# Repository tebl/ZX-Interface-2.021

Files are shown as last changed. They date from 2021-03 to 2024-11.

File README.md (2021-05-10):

# ZX Interface 2.021
I woke up in the middle of the night with idea, and like most non-sensical ideas - they usually disappear in the morning. Can't remember what that idea was, but it was properly better than this one: recreating a simple version of the *ZX Interface 2* because I simply can't afford the prices the original ones are going for. Having made a few *improvements* to the original design, I was going to call it the *ZX Interface 2000* - that would however imply that I had put anything modern into it, so *ZX Interface 2.021* was the name I came up with instead. There's even a short video showing it running on [YouTube](https://youtu.be/rGyqisjjOV8).

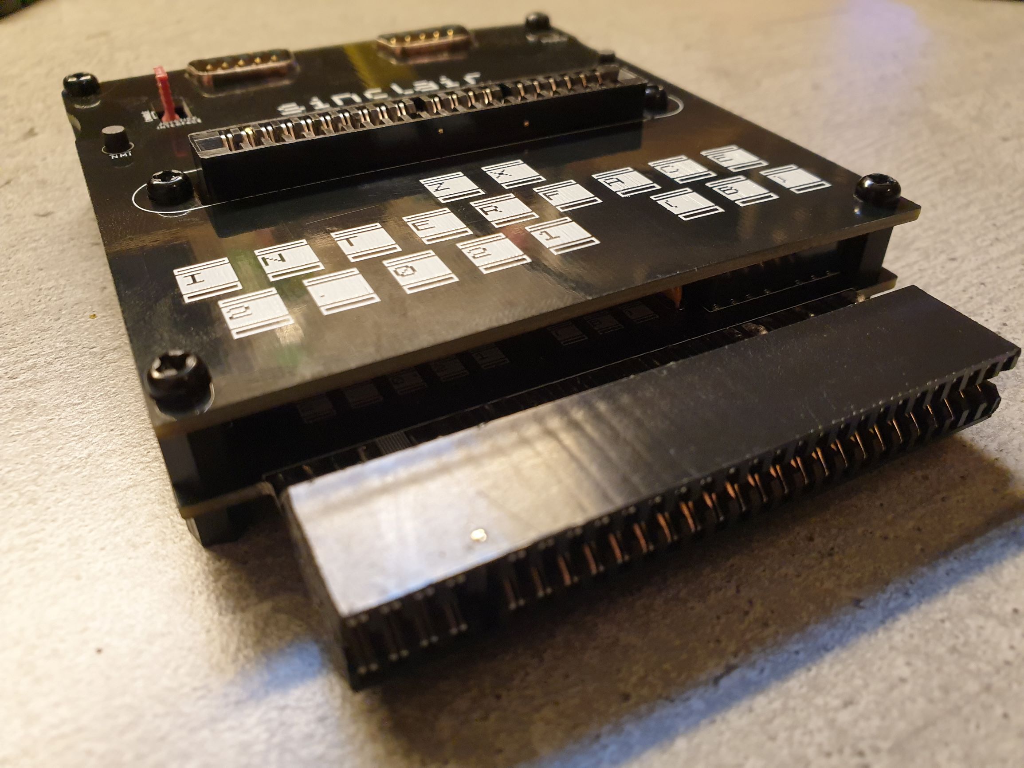
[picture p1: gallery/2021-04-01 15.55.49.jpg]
ZX Interface 2.021


There are other more modern implementations for putting together a ZX Spectrum cartridge solution, the Dandanator comes to mind, but I wanted something without the magic black boxes (MCUs, FPGAs or GALs) - my goal is that it should be easy to build and easy to understand. Also, I kind of like having various physical cartridges that can plug into it - so an actual cartridge slot was always a requisite for this project. 

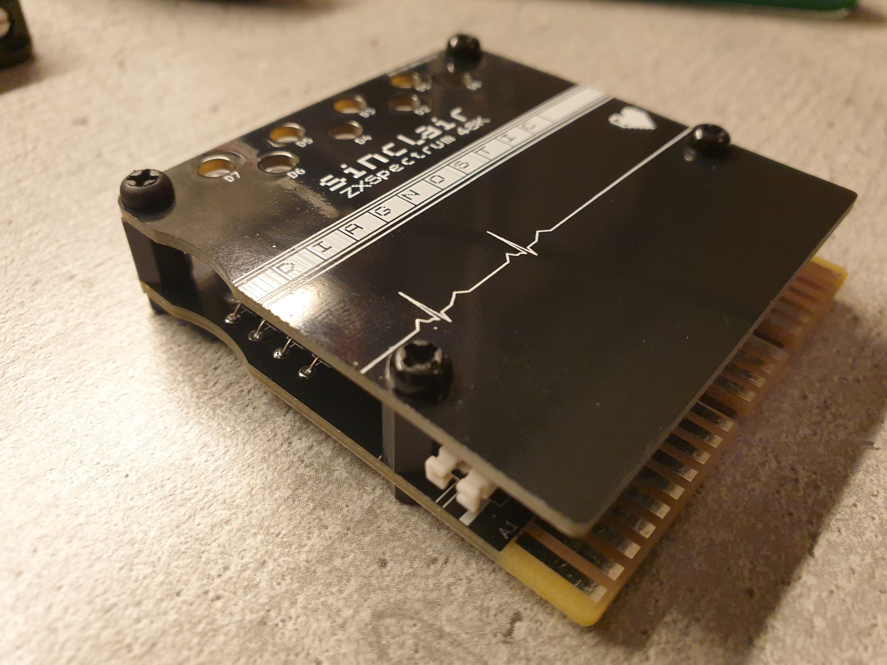
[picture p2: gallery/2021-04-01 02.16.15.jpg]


Over to the improvements then, of which there are mainly just one that hasn't already been mentioned (the first one being the elimination of custom IC, for which there are no replacements). The other one is that logic for bank switching has been integrated into the interface, in its current state it allows you to access up to 512k ROMs in 16k segments. Four of them actually, bringing the maximum addressable ROM up to a whopping 4MB (that's 4096KB, not merely 4 Mbit).

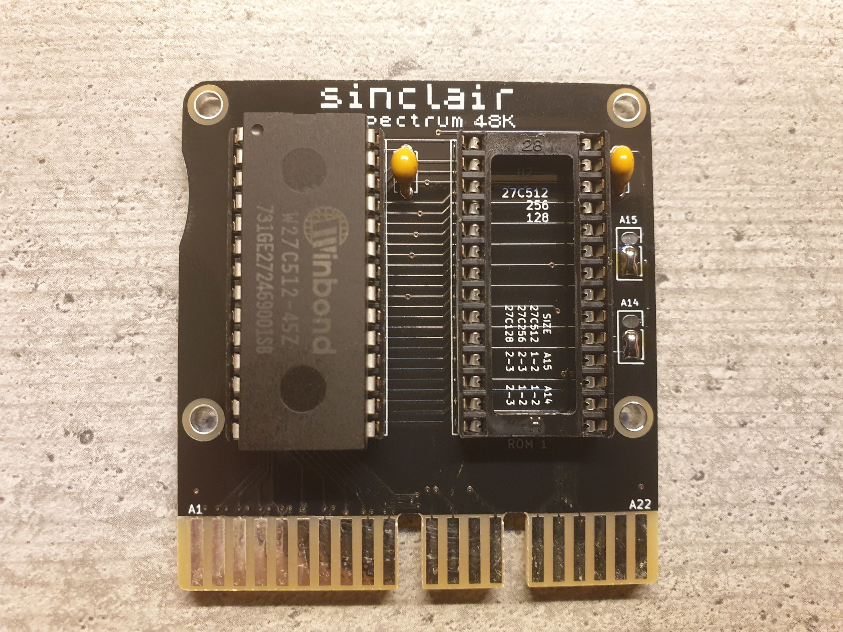
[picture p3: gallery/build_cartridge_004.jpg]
ZX Cartridge 2.021

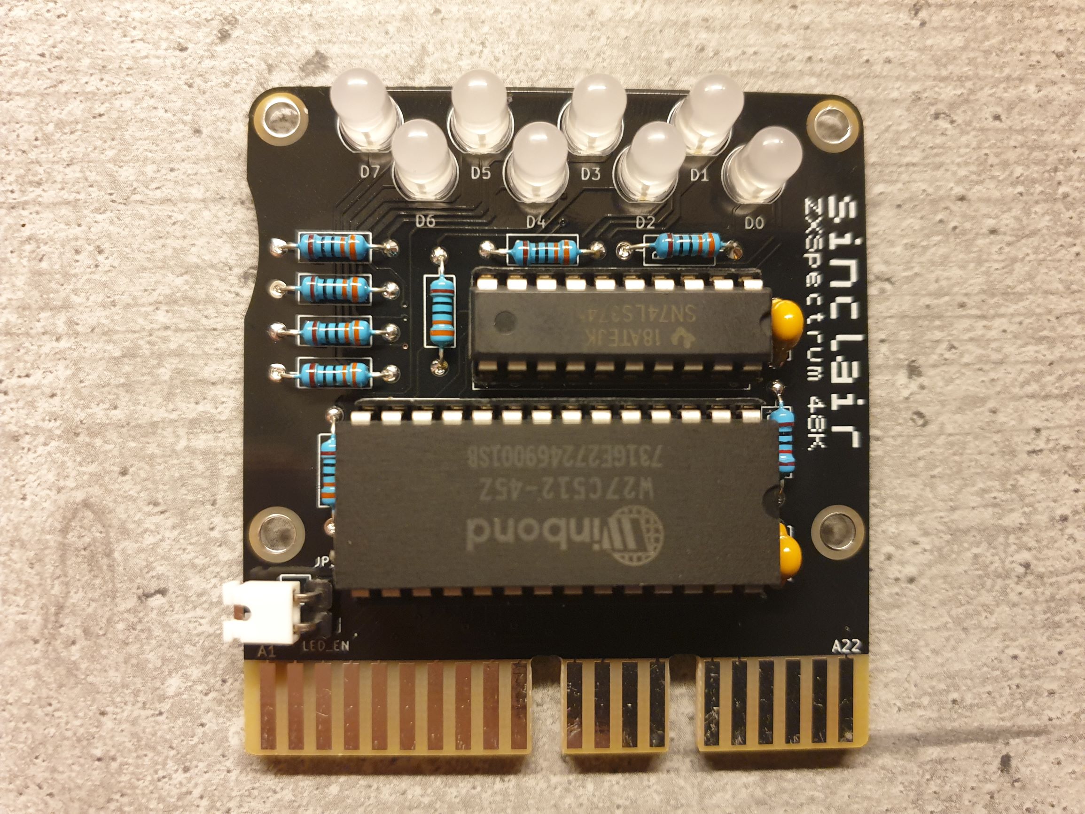
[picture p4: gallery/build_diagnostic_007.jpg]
ZX Diagnostic 2.021


The cartridges available mostly will have some different attributes, so you'll need to check out the README for each one of them to access all relevant information. When starting out I recommend starting with the diagnostic cartridge, it supports a single EPROM of up to 64K - giving you access to four 16K ROM images that you can switch between by using a technique called [bank switching](https://github.com/tebl/ZX-Interface-2.021/blob/main/documentation/bank_switching.md). The ZX Spectrum computer doesn't exactly expect you to hot-swap them this way, so there is a need to add a [Cartridge Loader](https://github.com/tebl/ZX-Interface-2.021/tree/main/software/cartridge_loader) program to ensure that the program starts correctly. To make things a bit easier on myself when it comes to creating cartridge compilations, I've put together a [Cartridge Creator](https://github.com/tebl/ZX-Interface-2.021/tree/main/software/cartridge_creator) that automates tasks as well as supporting updating the loader program with bank titles as well as changing out the boot screen with ZX Spectrum SCR-files.

The diagnostic software I'm using by Brendan Alford, will attempt to write state information to the LEDs on port 63. You can also play around with them directly from basic, just do an "*OUT 63, 255*" - to turn all of them on. Battlestar Galactica fans will intuitively know what tomorrows project ought to be!

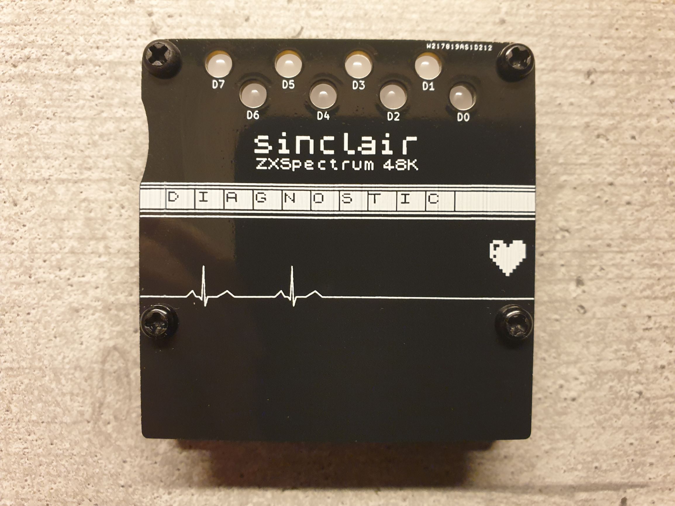
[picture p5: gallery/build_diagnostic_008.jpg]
ZX Diagnostic 2.021 FA1


The project includes a bunch of faceplates, they are mainly just there to look incredibly cool! Especially in black. While I've done a few pretty ones to match specific games, I've not obtained permission to include the likeness of any of the characters - for that reason, those have been intentionally kept separate from the github-repository. They may however show up in the gallery sections, because they exist and I had fun making them for my own personal enjoyment.

## Getting one
I don't have the capability of selling completed units or "kits" for building one, mainly due to health reasons. If you want one you will probably have to build it yourself, alternatively you could always call your favourite friend - preferably one that already owns, or is willing to buy a soldering iron of reasonable quality.

The following table will point you to more information about the specific modules, including a list of the components that goes into building one of them (referred to as a BOM). While the interface can be used as a standalone Sinclair joystick interface, you'll more than likely want at least one of the additional cartridges so that you have something to plug into it as well. Note that there will be several faceplates available for these, these as well as the PCBs for the modules listed are available on [PCBWay shared projects](https://www.pcbway.com/project/shareproject/?tag=ZX%20Interface%202.021).

| Module | Description |
| --- | --- |
| [ZX Interface 2.021](https://github.com/tebl/ZX-Interface-2.021/tree/main/ZX%20Interface%202021) | The actual interface, includes cartridge slot and joystick interface.
| [ZX Diagnostic 2.021](https://github.com/tebl/ZX-Interface-2.021/tree/main/ZX%20Diagnostic%202021) | A diagnostic cartridge, only for use with *ZX Interface 2.021*.
| [ZX Cartridge 2.021](https://github.com/tebl/ZX-Interface-2.021/tree/main/ZX%20Cartridge%202021) | Cartridge supporting up to two 64K ROMs, eight banks of data in total. Only for use with *ZX Interface 2.021*.
| [ZX Cartridge 1.983](https://github.com/tebl/ZX-Interface-2.021/tree/main/ZX%20Cartridge%201983) | A simple cartridge that can also be used with the original ZX Interface 2 (without bank switching support).

**NB!** As with all things you're soldering together by yourself, the one who soldered it - takes responsibility for it. I'll try to help in any way that I can, but know that this is a hobby-grade project and my health is not such that I can focus on too many things at any given time. Check out the [schematic](https://github.com/tebl/ZX-Interface-2.021/tree/main/documentation/schematic) while you wait, just about every problem is just an opportunity for learning and there is a significant chance that you'll be able to find your answer within it.

## Setting it up
The *ZX Interface 2.021* has a handful of jumpers that need to be set correctly in order to keep everything working as intended (refer to image below for reference). The jumper in the top left corner is used to enable the joystick interface, put a jumper across pins 1-2 (the lower position) and it should provide you with many hours of joy with your favourite Atari-compatible stick.

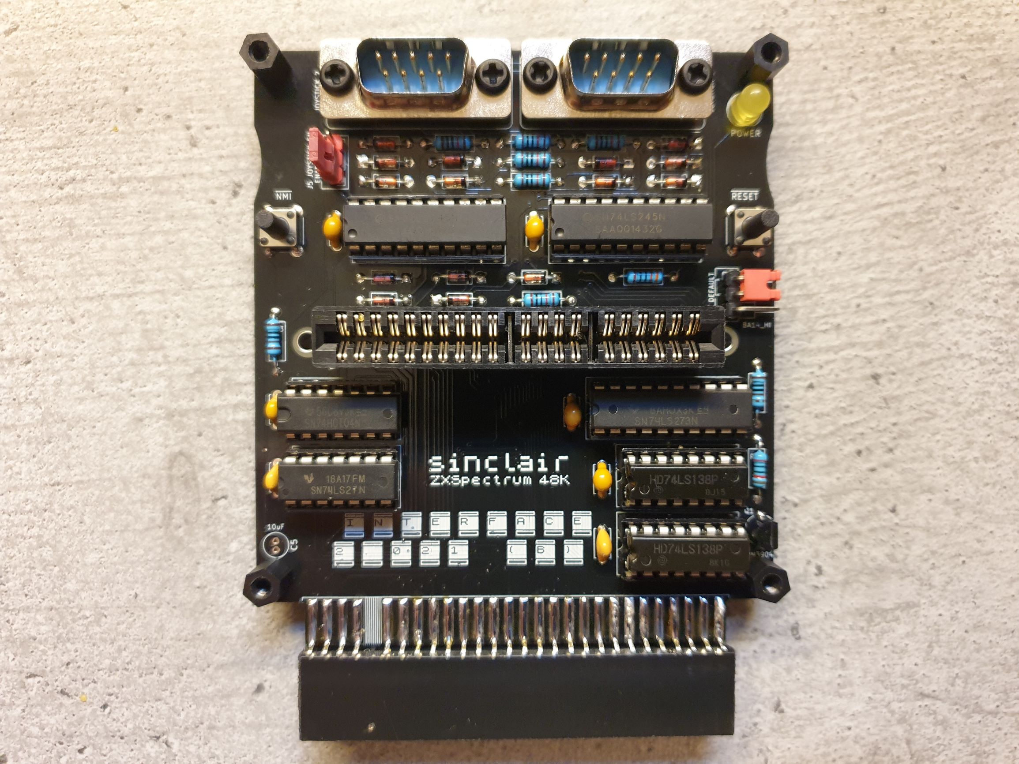
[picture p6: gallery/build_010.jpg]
ZX Interface Jumpers


The second jumper, middle right section allows you to hardcode one of the address lines used for bank switching. Setting it the lower position forces it high, in effect allowing you to quickly select between two 16k ROM images in the first and second bank - when all else fails. This is here as a way to swap between diagnostic images when the machine isn't capabable of doing this in the preferred way. In normal use, jumper across pins 1-2 (this is the upper position).

**NB!** As with all kinds of vintage electronics that you don't want to destroy, you shouldn't attempt to insert or remove a cartridge when the system is powered up. Ignoring this will either kill this interface, the cartridge or your computer - sometimes all of them.

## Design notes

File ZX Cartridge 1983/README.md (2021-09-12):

# ZX Cartridge 1.983
With the ZX Cartridge 2.021, I intentionally created a cartridge that wouldn't be compatible with any of the original cartridge interfaces released for the ZX Spectrum. The more known of these type of interfaces is the original *ZX Interface 2*, but Kempston also released a well known one in the form of the *Kempston Pro Joystick Interface*. The first one was naturally priced firmly out of my price-range, the second one I got a hold of wasn't in a working state - so I went for option three instead, the *RAM turbo Mk2* joystick interface. Having found a working interface, I wanted an actual cartridge to use with it - so I created the *ZX Cartridge 1.983* to test things out.

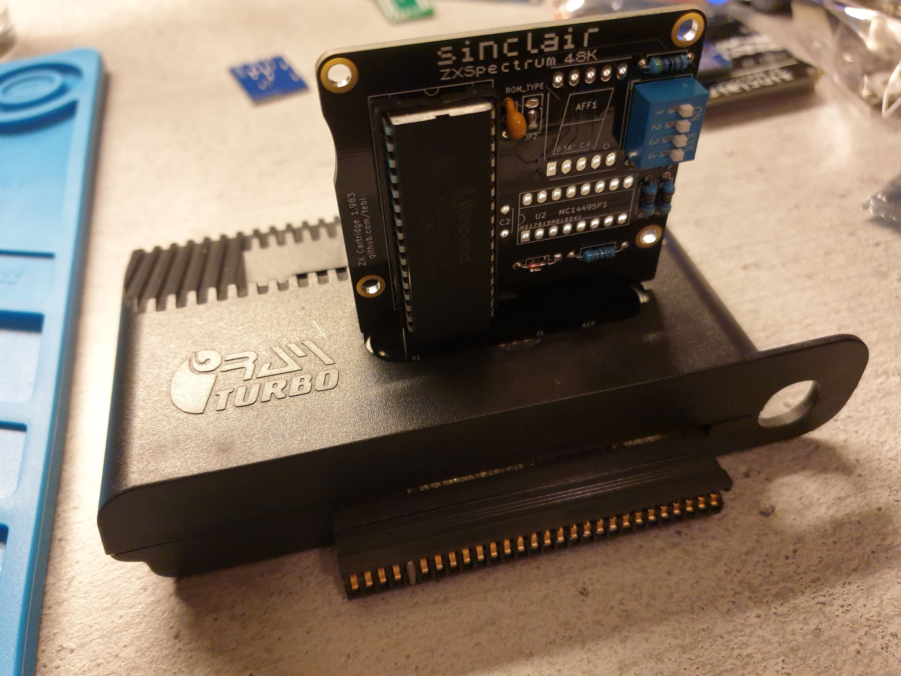
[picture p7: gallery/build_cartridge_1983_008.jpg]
ZX Cartridge 2.021


True to form, I didn't simply want to build a 16K cartridge - so I sprinkled a little bit of extra feature creep upon it. I figured that I'd look into being able to use even larger EEPROMs that what I'd used so far, with the 27C020 able to hold 16 of these images - pretty extreme when considering that the system only had 10 officially released titles. There are a few [cassette conversions](http://www.fruitcake.plus.com/Sinclair/Interface2/Cartridges/Interface2_RC_New_3rdParty_GameConversions.htm) that can be used as well, good enough to fill a couple of them. With 16 images possible combinations I needed a way to choose between them, cheap as I am the solution became a 4 position DIP-switch. Just because I already had them and the space, I added a completely optional HEX-decoder IC and 7segment display - gloriously over-engineered. Smaller (E)EPROMs can still be used such as the 27C256/27C512 can still be used, you just need to install components to match.

- [1> Building the cartridge](#1-building-the-cartridge)
  - [1.1> Soldering it together](#11-soldering-it-together)
  - [1.2> Testing it out](#12-testing-it-out)
- [2> Schematic](#2-schematic)
- [3> BOM](#3-bom)

# 1> Building the cartridge
Building the unit assumes you have at least minor experience soldering things together, recommended is at least a soldering station with adjustable temperature to get started - usually you'll want some 60/40 solder tin (if you can get that where you live). Given that we're going to be flashing data onto EPROM chips, you'll need an EPROM programmer suitable for this task - the one I'm using is a MiniPro TL866CS and so far it's surpassed my expectations for such a reasonably priced device. If you are going to use EPROM chips you will need an EPROM ereaser as well, but read on - you might not need that depending on the chips you purchase.

With the equipment sorted, now comes the shopping - so head on over to the [BOM](#3-bom)-section for some information on what you need. Note that with sites such as ebay, AliExpress and similar sites that sell cheap chinese components, you'll need to treat these as a suggested search term and look for something that matches the gallery pictures.

You'll need to order some EPROM chips as well. As previously mentioned, you can use anything from 27C128 up to 27C020 chips. One specific chip I can recommend looking for is the W27C512, W27C010 or W27C020 as that is actually an EEPROM with the compatible pin layouts, meaning you won't need the previously mentioned EPROM ereaser. The price difference should be negligible unless you're going to make a lot of them.

## 1.1> Soldering it together
The construction of this unit should be straight-forward, there's only a few components to speak of - and none of them overlap in any way. I do however recommend that you build up the components in increasing size, that way you'll have an easier time getting everything on there straight.

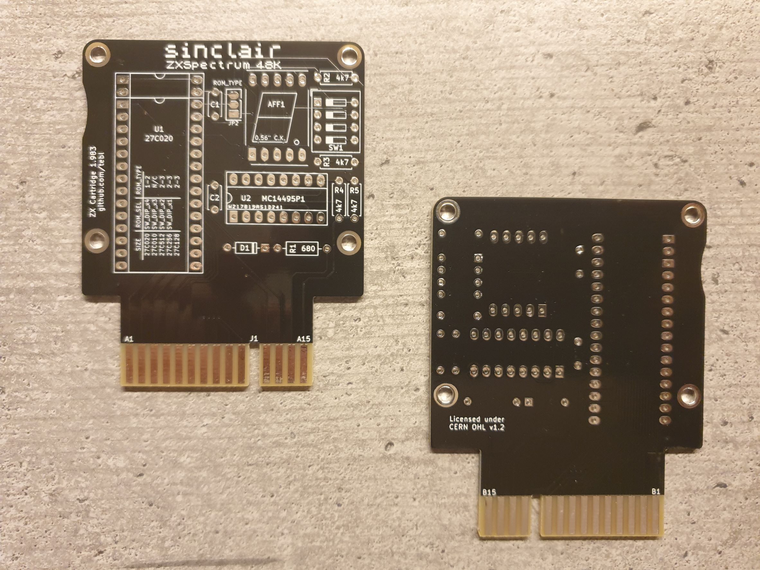
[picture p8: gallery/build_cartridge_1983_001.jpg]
Build cartridge 001

Build cartridge 001

As shown above, we've started by installing resistors as well as the single diode (note the polarity marking, the line should match up with the board). Before moving onto anything else, we need to figure out which (E)EPROM chips we're going to install, for the two larger options we'll need to use a 32-pin socket (reconsider your life choices if not installing sockets) - for anything 27C512 or smaller we can use the common 28-variety, making sure that we leave a gap of four holes at the **top** of the board. Solder the jumper marked *ROM_TYPE* according to the table (the square pad marks pin 1, N/C means leave unconnected).

| (E)EPROM | ROM_SEL | ROM_TYPE |
| --- | --- | --- |
| 27C020 | 4 way DIP | 1-2 |
| 27C010 | 3 way DIP | N/C |
| 27C512 | 2 way DIP | 2-3 | 
| 27C256 | 1 way DIP | 2-3 |
| 27C128 | | 2-3 | 

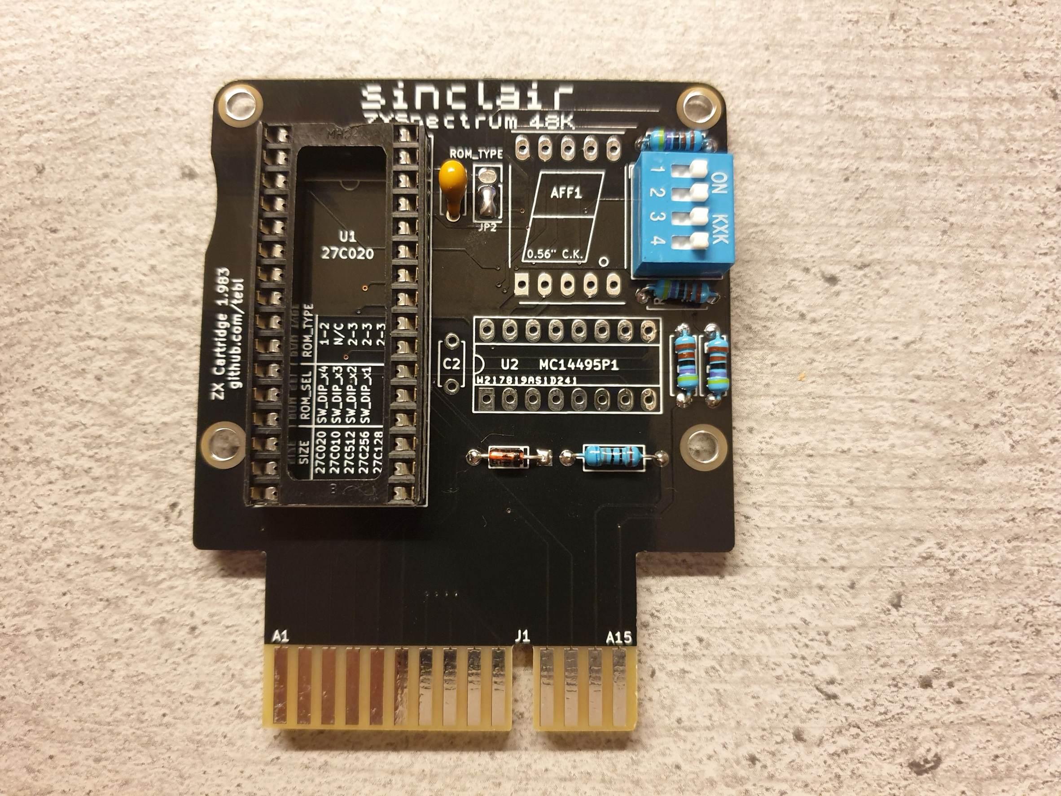
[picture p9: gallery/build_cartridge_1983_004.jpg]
Build cartridge 001


The two capacitors aren't polarized, just get them stuck into the hole and you'll be ready to move along to a suitable beat. Next step is to put in the DIP-switches, but refer to the table above so that you use the correct one - mount it at the top, leaving empty holes towards the bottom of the board.

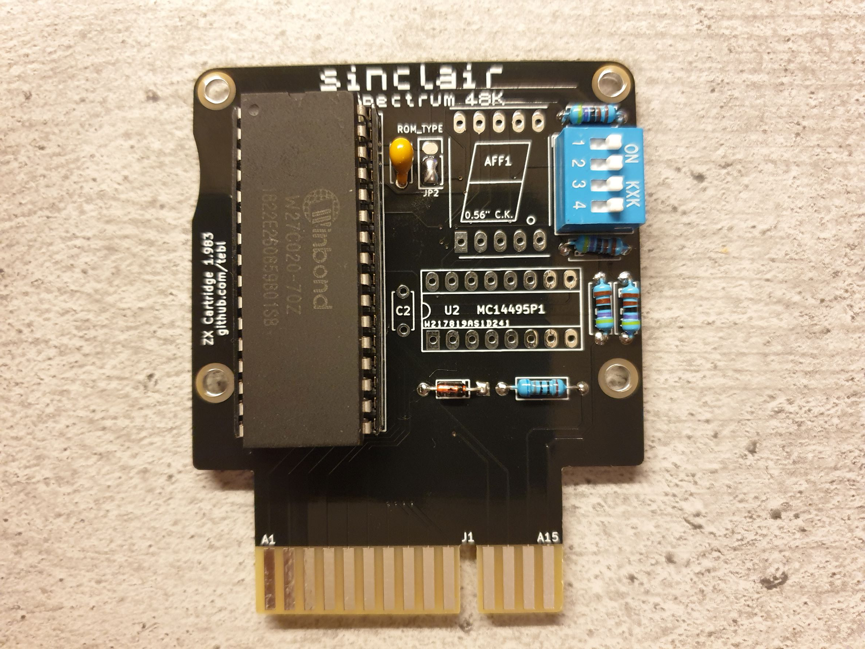
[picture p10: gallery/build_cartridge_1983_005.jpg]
Build cartridge 001


With the end of the build in sight, we focus on the single remaining component - the 7-segment display. The display should have be a 0.56" one, it should have been sold to you as one with a common cathodes (C.K.). If in doubt whether you have the correct display, put your multimeter in diode testing mode (oftenly referred to as *continuity*-mode) and ensure that you can light up one segment by putting the negative lead on the bottom center pin. Using the display requires an old IC marked MC14495P1, it is the only one I've come across that can count displays digits above 9 without costing an arm and a leg (I bought mine on AliExpress).

## 1.2> Testing it out
I shouldn't have to say it at this point, but I'll do so anyway - cartridges are not memory cards, plugging them in or unplugging them while the system is powered on will **KILL** your equipment. If you've not already done so, you'll need to put something on your selected (E)EPROM - see separate document on [flashing an EEPROM](https://github.com/tebl/ZX-Interface-2.021/blob/main/documentation/flash_eeprom.md) for details on how to do this (in particular the part on combining 16K images). With that out of the way, just plug the cartridge into the slot  and power on the ZX Spectrum.

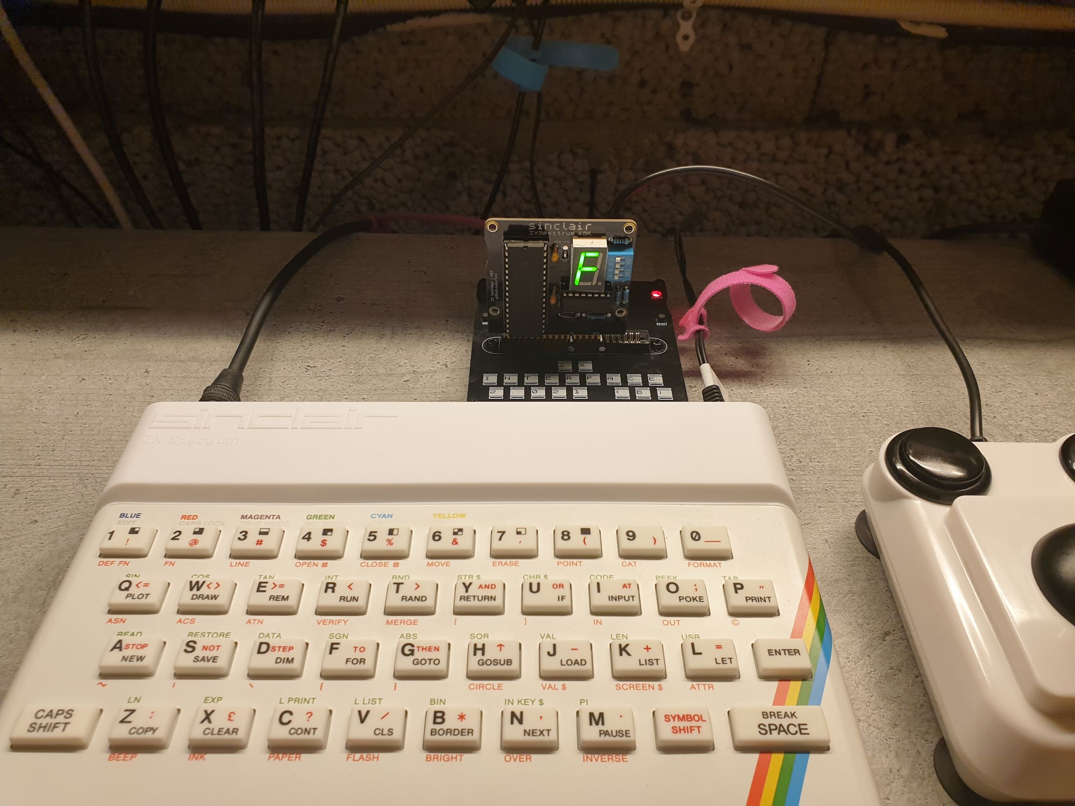
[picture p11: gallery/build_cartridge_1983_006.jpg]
Build cartridge 006


One thing that I've found with ZX Spectrum cartridges is that they tend to restart when program running on it crashes, which we can at times use to simply move the switches to swap games. Not all of them will work reliably, but as with everything ZX Spectrum - if in doubt, just reset the computer and everything should be back to normal again. If you don't have a reset button available, such as when using the old interfaces on a non-plussed computer, you'd need pull the power - just like we did in 1983.

# 2> Schematic
The supplied KiCad files should be sufficient as both a schematic and as a  starting point for ordering PCBs (basically you could just zip the contents of the export folder and upload that on a fabrication site), the schematic is also available in [PDF-format](https://github.com/tebl/ZX-Interface-2.021/tree/main/documentation/schematic) and this is what you'll need to print and work your way through this things don't work as expected after assembly.

# 3> BOM
Most parts should be easy to get a hold of from your favourite local electronic component shop, but given that I don't have access to such shops where I live so everything was based on whatever I could get cheapest from eBay/AliExpress (free shipping, but plan on waiting 3-4 weeks for delivery). 

| Reference | Item | Count | Order  |
| --- | --- | ----- | --- |
| Cartridge PCB | Fabricate using Gerber files | 1 | [PCBWay]()
| AFF1 * | 0.56" 7-segment display (C.K.) | (1)|
| C1,C2 | 100nF ceramic capacitor (5mm pin spacing) |  1 (1)|
| D1 | 1N4148 small signal diode (DO-35) | 1 | 
| R1 | 680 ohm resistor | 1 |
| R2-R5 | 4k7 (4700) ohm resistor | 4 |
| U1 ** | 27C020 or smaller (E)EPROM (W27C020 recommended) | 1 |
| U1 * | MC14495P1 (DIP-16) | (1)|
| SW1 ** | 1-4 way DIP switch | 1 |
| Mounting *** | Nylon M3 hex standoffs 8mm | (4)|
| Mounting *** | Nylon M3x6mm nylon screws | (4)|
| Mounting *** | M3 nylon nut | (4)|  

*) These are optional components that are just used to show the slot number. Cool, but not needed.

**) The DIP switch needs to match the size of the (E)EPROM that you wish to install on the board, for more information have a read-through of [1.1> Soldering it together](#11-soldering-it-together).

***) The easiest way of ordering these is to just one of the M3 nylon standoff kits on ebay, AliExpress or any similar sites. That way you'll get more than what you need in various sizes for future projects as well. Check out [faceplate](https://github.com/tebl/ZX-Interface-2.021/tree/main/faceplates) section of this repository or [PCBWay shared projects](https://www.pcbway.com/project/shareproject/?tag=ZX%20Interface%202.021) for available options.

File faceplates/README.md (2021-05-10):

# Faceplates
When designing the *ZX Interface 2.021* I had a vision of using cartridge on it that didn't look like a bare circuit board, but it needed to be something that didn't require any sort of 3D-printing facility so I opted to just make the *"case"* another PCB. Adding a label printer finishes the look though I probably should have bought some with a clear backing, but there's always next month for those sorts of changes.

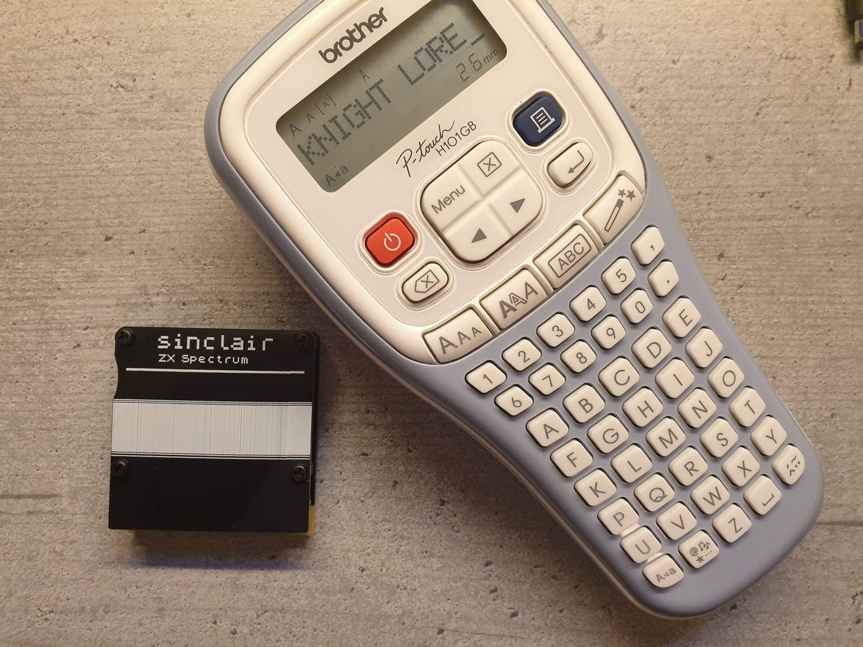
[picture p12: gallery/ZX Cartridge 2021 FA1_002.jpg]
Label printer

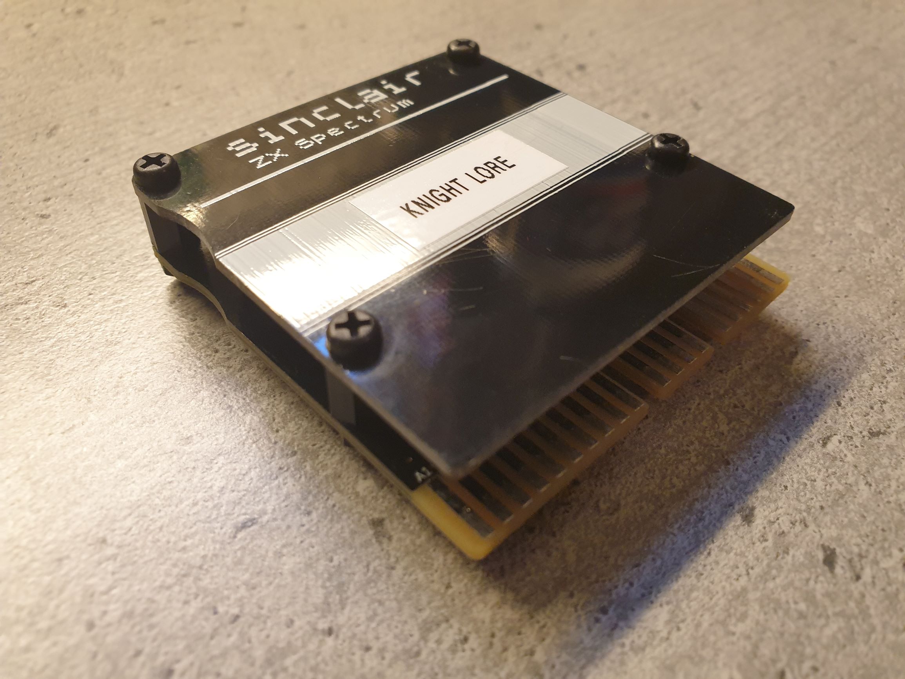
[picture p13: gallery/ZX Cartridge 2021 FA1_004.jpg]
Finished cartridge

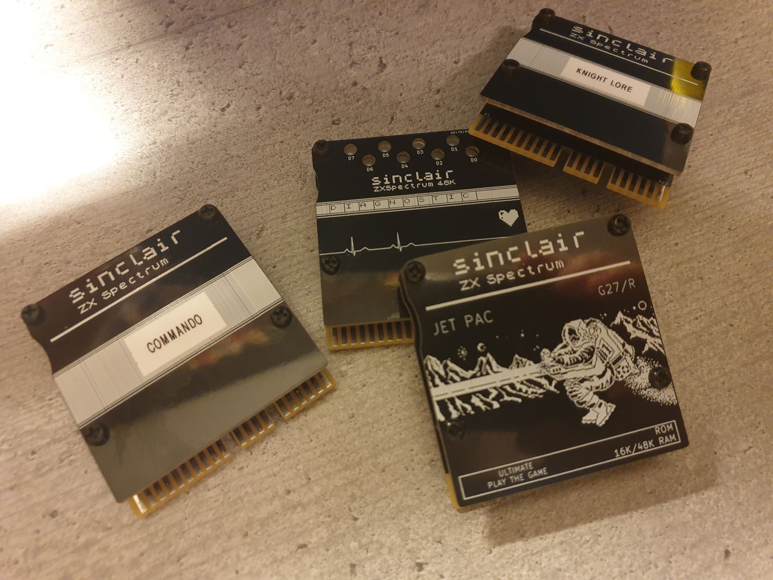
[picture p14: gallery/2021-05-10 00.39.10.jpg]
Varius cartridge


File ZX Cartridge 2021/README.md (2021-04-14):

# ZX Cartridge 2.021
The ZX Cartridge 2.021, simply referred to as *cartridge* for the remainder of this document, is a modified version of the one released by Sinclair back in 1983. The original cartridge design was limited to 16K without any of the signals required to easily build a larger one, so the *ZX Cartridge 2.01* set out to fix that - simply by extending the length of the cartridge. This does mean that you can't use it with the original *Sinclair ZX Interface 2*, you can only use it with the *ZX Interface 2.021*.

ZX Cartridge 2.021

Though the interface itself is able to address ROM chips in sizes up to 512K, four of them actually, the cartridge itself was designed with the ROM chips ranging from 27C128 up to 27C512. I might make a monster cartridge at some point, but given that there were only around 10 cartridges released for the original system - having the space for 8 of them is a good starting point.

Note that there are various faceplates available for the cartridges, these complete the look of the cartridge as well as help them balance on top of the interface. Check out the [faceplates](https://github.com/tebl/ZX-Interface-2.021/tree/main/faceplates) section for an overview over the ones that have been made available, also see [PCBWay shared projects](https://www.pcbway.com/project/shareproject/?tag=ZX%20Interface%202.021).

- [1> Building the cartridge](#1-building-the-cartridge)
  - [1.1> Soldering it together](#11-soldering-it-together)
  - [1.2> Assembling the unit](#12-assembling-the-unit)
  - [1.3> Testing it out](#13-testing-it-out)
- [2> Schematic](#2-schematic)
- [3> BOM](#3-bom)

# 1> Building the cartridge
Building the unit assumes you have at least minor experience soldering things together, recommended is at least a soldering station with adjustable temperature to get started - usually you'll want some 60/40 solder tin (if you can get that where you live). Given that we're going to be flashing data onto EPROM chips, you'll need an EPROM programmer suitable for this task - the one I'm using is a MiniPro TL866CS and so far it's surpassed my expectations for such a reasonably priced device. If you are going to use EPROM chips you will need an EPROM ereaser as well, but read on - you might not need that depending on the chips you purchase.

With the equipment sorted, now comes the shopping - so head on over to the [BOM](#3-bom)-section for some information on what you need. Note that with sites such as ebay, AliExpress and similar sites that sell cheap chinese components, you'll need to treat these as a suggested search term and look for something that matches the gallery pictures.

You'll need to order some EPROM chips as well. As previously mentioned, you can use anything from 27C128 up to 27C512 chips. One specific chip I can recommend looking for is the W27C512 chip as that is actually an EEPROM with the same pin layout, meaning you won't need the previously mentioned EPROM ereaser. The price difference is negligible unless you're going to make a lot of them.

## 1.1> Soldering it together
The construction of this unit should be straight-forward, specifically as there are only a handful of components to deal with. If you are only going to install a single (E)EPROM into the board, you just need to solder in the left socket and the capacitor next to it.

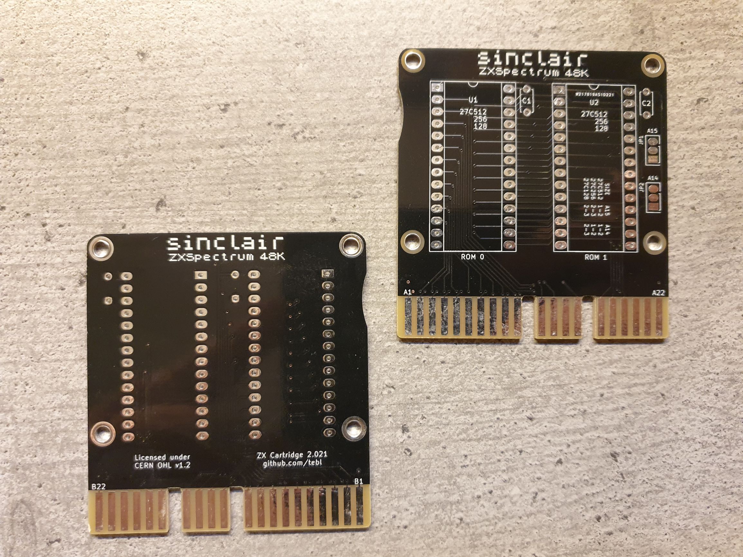
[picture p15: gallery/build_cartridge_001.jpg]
Build cartridge 001


There are two solder jumpers on the right side of the cartridge, these are clearly labelled A14 and A15 with pin 1 identifiable as the square pad. You need to add some solder to bridge between two of the pins, this is dependent on the type of (E)EPROM you are going to install into the slots (they need to be of the same kind so no mixing and matching).

| (E)EPROM | A15 | A14 |
| --- | --- | --- |
| 27C512 | 1-2 | 1-2 | 
| 27C256 | 2-3 | 1-2 | 
| 27C128 | 2-3 | 2-3 | 

A completed unit with the jumpers soldered in for the installed 27C512 chip can be seen below, this is mainly all there is to it. The rest of the components that are usually associated with ZX Spectrum cartridges are integrated into the *ZX Interface 2.021* instead - meaning you can quickly solder together all the cartridges you'll ever need in just a few minutes.

Build cartridge 004

## 1.2> Assembling the unit
There isn't all that much that can be said for assembling the unit, chances are you've already finished the entire thing by this point. The only remaining step would just be to add a [faceplate](https://github.com/tebl/ZX-Interface-2.021/tree/main/faceplates), it helps keep the cartridge from flopping around in the cartridge slot while adding quite a bit of visual flair to it.

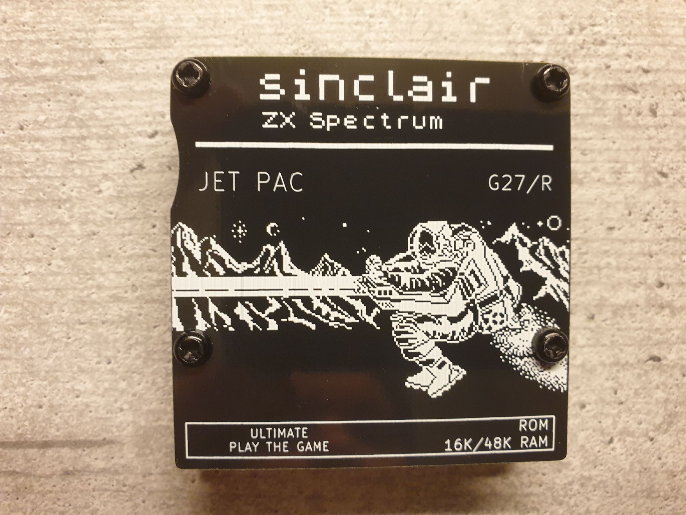
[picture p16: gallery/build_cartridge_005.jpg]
Build cartridge 005


The faceplate is just a simple PCB, the suggested way of attaching it is by using components found in cheap *M3 nylon hex* kits. It will look at its best when using an 8mm nylon hex standoff (F-F), then adding screws from both sides. If, on the other hand, you want to stay within the kit - then I suggest using the 8mm M-F standoffs, add M3 nuts on the bottom and snip off the remaining part of the nylon screw that'll poke through. Add screws on top.

## 1.3> Testing it out
I shouldn't have to say it at this point, but I'll do so anyway - cartridges are not memory cards, plugging them in or unplugging them while the system is powered on will **KILL** your equipment. With that out of the way, just plug the cartridge into the slot and then apply power to see if whatever you put into the first 16K of the (E)EPROM starts up as expected.

The ZX Spectrum doesn't actually have any knowledge of any of the bank switching logic installed on the interface, in fact the ROM in your computer will be completely disabled when any cartridge is inserted into the interface. So in order to access any of the other banks available we'll need to come up with something else, but that is described separately in [bank_switching](https://github.com/tebl/ZX-Interface-2.021/blob/main/documentation/bank_switching.md) that have been included as part of the [documentation](https://github.com/tebl/ZX-Interface-2.021/tree/main/documentation).

# 2> Schematic
The supplied KiCad files should be sufficient as both a schematic and as a  starting point for ordering PCBs (basically you could just zip the contents of the export folder and upload that on a fabrication site), the schematic is also available in [PDF-format](https://github.com/tebl/ZX-Interface-2.021/tree/main/documentation/schematic) and this is what you'll need to print and work your way through this things don't work as expected after assembly.

# 3> BOM
Most parts should be easy to get a hold of from your favourite local electronic component shop, but given that I don't have access to such shops where I live so everything was based on whatever I could get cheapest from eBay/AliExpress (free shipping, but plan on waiting 3-4 weeks for delivery). 

| Reference | Item | Count | Order  |
| --- | --- | ----- | --- |
| Cartridge PCB | Fabricate using Gerber files | 1 | [PCBWay](https://www.pcbway.com/project/shareproject/ZX_Cartridge_2_021.html)
| Faceplate PCB * | Fabricate using Gerber files | (1)| [PCBWay](https://www.pcbway.com/project/shareproject/ZX_Cartridge_2_021__Faceplate_FA1_.html)
| U1,U2 ** | 27C128,27C256 or 27C512 (W27C512 recommended) |  1 (1)|
| C1,C2 ** | 100nF ceramic capacitor (5mm pin spacing) |  1 (1)|
| Mounting * | Nylon M3 hex standoffs 8mm | (4)|
| Mounting * | Nylon M3x6mm nylon screws | (4)|
| Mounting * | M3 nylon nut | (4)|  

*) The easiest way of ordering these is to just one of the M3 nylon standoff kits on ebay, AliExpress or any similar sites. That way you'll get more than what you need in various sizes for future projects as well. Check out [faceplate](https://github.com/tebl/ZX-Interface-2.021/tree/main/faceplates) section of this repository or [PCBWay shared projects](https://www.pcbway.com/project/shareproject/?tag=ZX%20Interface%202.021) for available options.

**) Only a single (E)EPROM is required to build a cartridge, components U2 and C2 are therefore listed as optional. Installing 28-pin wide DIP sockets is highly recommended rather than soldering the (E)EPROM directly to the board.

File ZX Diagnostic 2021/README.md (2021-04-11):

# ZX Diagnostic 2.021
The *ZX Diagnostic 2.021*, simply referred to as the *diagnostic cartridge* for the remainder of this document, has been specially made to work with the [diagnostic firmware](https://github.com/brendanalford/zx-diagnostics) developed by Brendan Alford. Part of the hardware used within the *ZX Interface 2.021* has been designed to be functionally similar to other diagnostic cartridges, in particular the bank switching scheme and the way  the cartridge can be disabled by the computer was based on the following [blog post](https://blog.gjmccarthy.co.uk/wp-content/uploads/2019/12/how.html).

ZX Diagnostic 2.021
ZX Diagnostic 2.021 (no faceplate)

The rest of the functionality needed to serve as a diagnostic cartridge has been added to the *ZX Diagnostic 2.021*, apart from being a 16K cartridge there is an 8bit latch that will be used to output diagnostic status to the LEDs. The LEDs will allow some additional feedback to show that the computer is somewhat functional, even when there there is no image. Compared to the *ZX Cartridge 2.021*, this only supports a single ROM chip with sizes ranging ranging from 27C128 up to 27C512.

ZX Diagnostic 2.021 (faceplate)

Note that there are various faceplates available for the cartridges, these complete the look of the cartridge as well as help them balance on top of the interface. Check out the [faceplates](https://github.com/tebl/ZX-Interface-2.021/tree/main/faceplates) section for an overview over the ones that have been made available, also see [PCBWay shared projects](https://www.pcbway.com/project/shareproject/?tag=ZX%20Interface%202.021).

- [1> Building the cartridge](#1-building-the-cartridge)
  - [1.1> Soldering it together](#11-soldering-it-together)
  - [1.2> Assembling the unit](#12-assembling-the-unit)
  - [1.3> Testing it out](#13-testing-it-out)
- [2> Schematic](#2-schematic)
- [3> BOM](#3-bom)

# 1> Building the cartridge
Building the unit assumes you have at least minor experience soldering things together, recommended is at least a soldering station with adjustable temperature to get started - usually you'll want some 60/40 solder tin (if you can get that where you live). Given that we're going to be flashing data onto EPROM chips, you'll need an EPROM programmer suitable for this task - the one I'm using is a MiniPro TL866CS and so far it's surpassed my expectations for such a reasonably priced device. If you are going to use EPROM chips you will need an EPROM ereaser as well, but read on - you might not need that depending on the chips you purchase.

With the equipment sorted, now comes the shopping - so head on over to the [BOM](#3-bom)-section for some information on what you need. Note that with sites such as ebay, AliExpress and similar sites that sell cheap chinese components, you'll need to treat these as a suggested search term and look for something that matches the gallery pictures.

You'll need to order some EPROM chips as well. As previously mentioned, you can use anything from 27C128 up to 27C512 chips. One specific chip I can recommend looking for is the W27C512 chip as that is actually an EEPROM with the same pin layout, meaning you won't need the previously mentioned EPROM ereaser. The price difference is negligible unless you're going to make a lot of them.

## 1.1> Soldering it together
The construction of this unit should be fairly straight-forward, just take your time in order to make sure everything goes into place - more or less straight. I usually recommend starting by having a good look at the PCBs, try to figure out where all of the listed components go and in which orientation they go (all of this should be clearly marked on the silkscreen). 

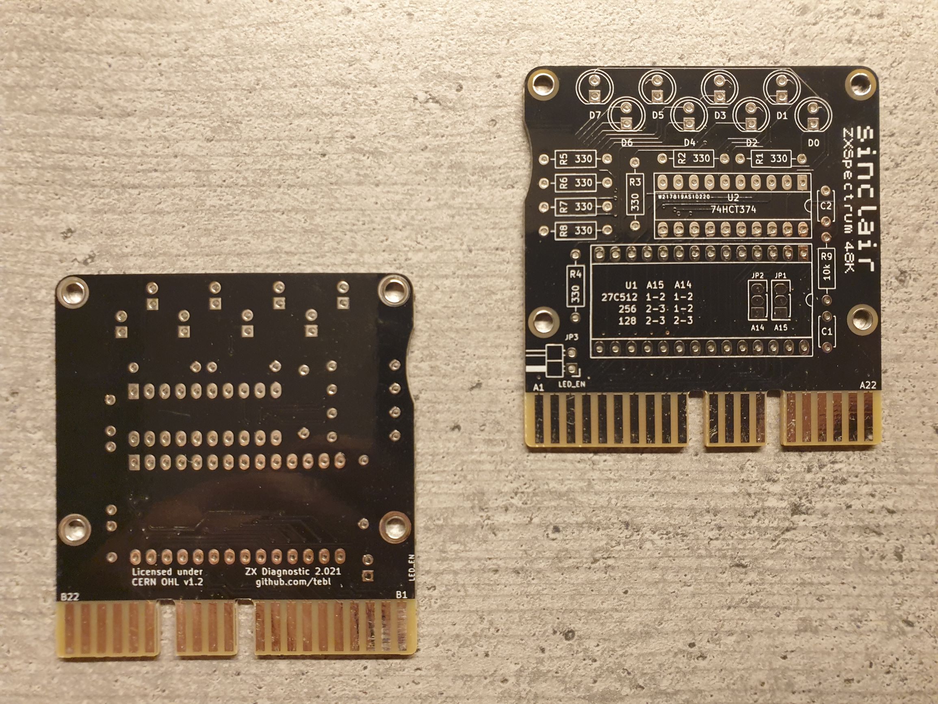
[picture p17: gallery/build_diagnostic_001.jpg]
Build cartridge 001


The last version I built is the one shown above, and going forward I usually try installing components sorted by physical - going from the smallest to the largest. The reason for this is that you want to be able to solder most of it into place before it starts wobbling on your desk, for the *ZX Diagnostic 2.021* this means saving all of those LEDs until last.

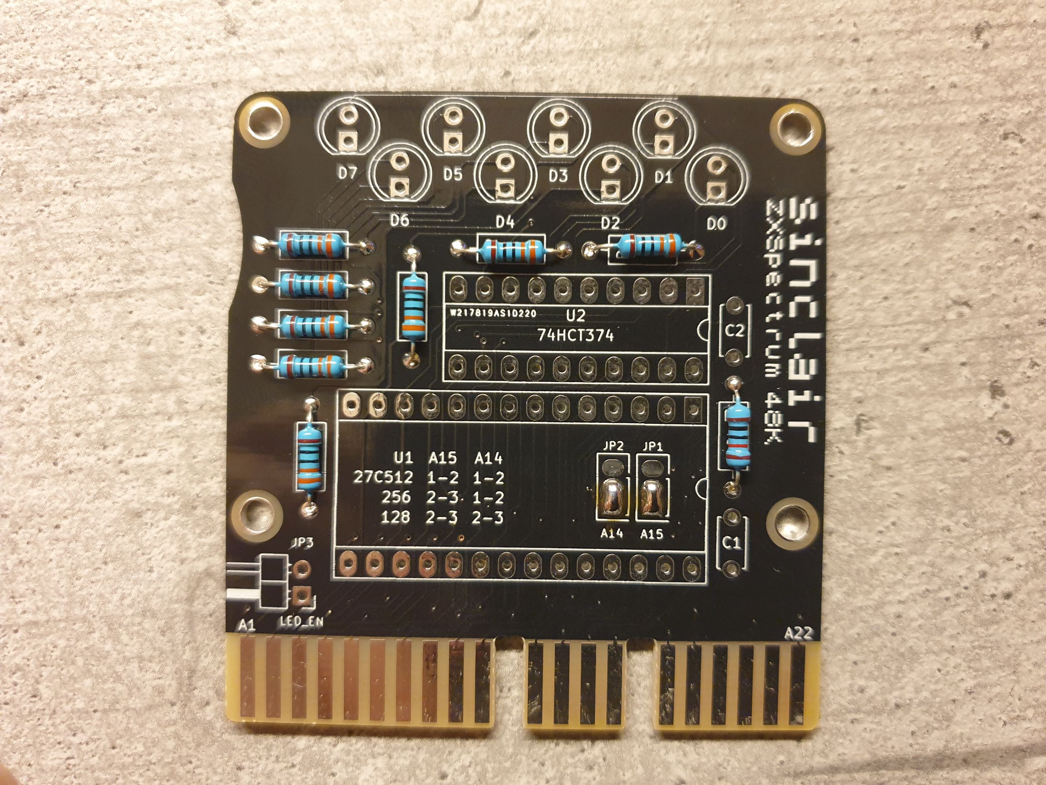
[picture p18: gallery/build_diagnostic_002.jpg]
Build cartridge 002


At this point we've soldered in all of the resistors, but take note that one of them will have a different resistor value from the others. There are two solder jumpers on the cartridge, these are clearly labelled A14 and A15 with pin 1 identifiable as the square pad. You need to add some solder to bridge between two of the pins, this is dependent on the type of (E)EPROM you are going to install into the socket marked U1 - see the table below for all supported ROM types.

| (E)EPROM | A15 | A14 |
| --- | --- | --- |
| 27C512 | 1-2 | 1-2 | 
| 27C256 | 2-3 | 1-2 | 
| 27C128 | 2-3 | 2-3 |

Next is the single right-angle pin header that is used to enable the LEDs at the top - to get that on straight, just solder on one of the pins, then reheat and adjust the position before soldering in the final pin. Alternatively you could also just solder a wire across the two pins to keep them permanently disabled, but this isn't recommended unless you know that the cartridge will only ever be used for diagnostic purposes.

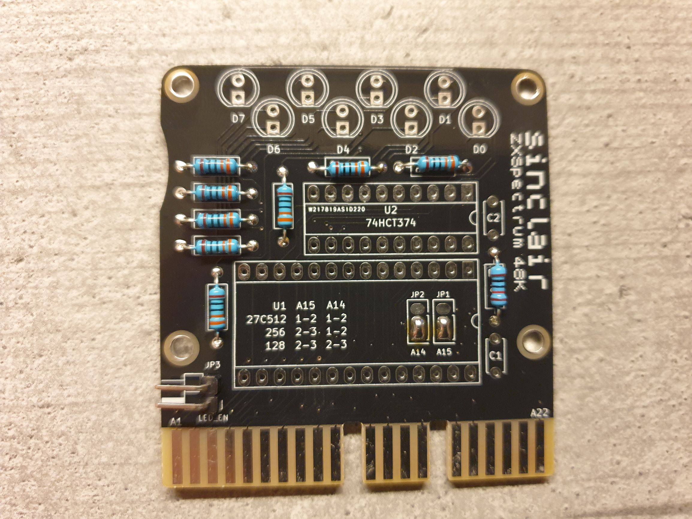
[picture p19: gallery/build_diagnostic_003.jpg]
Build cartridge 003

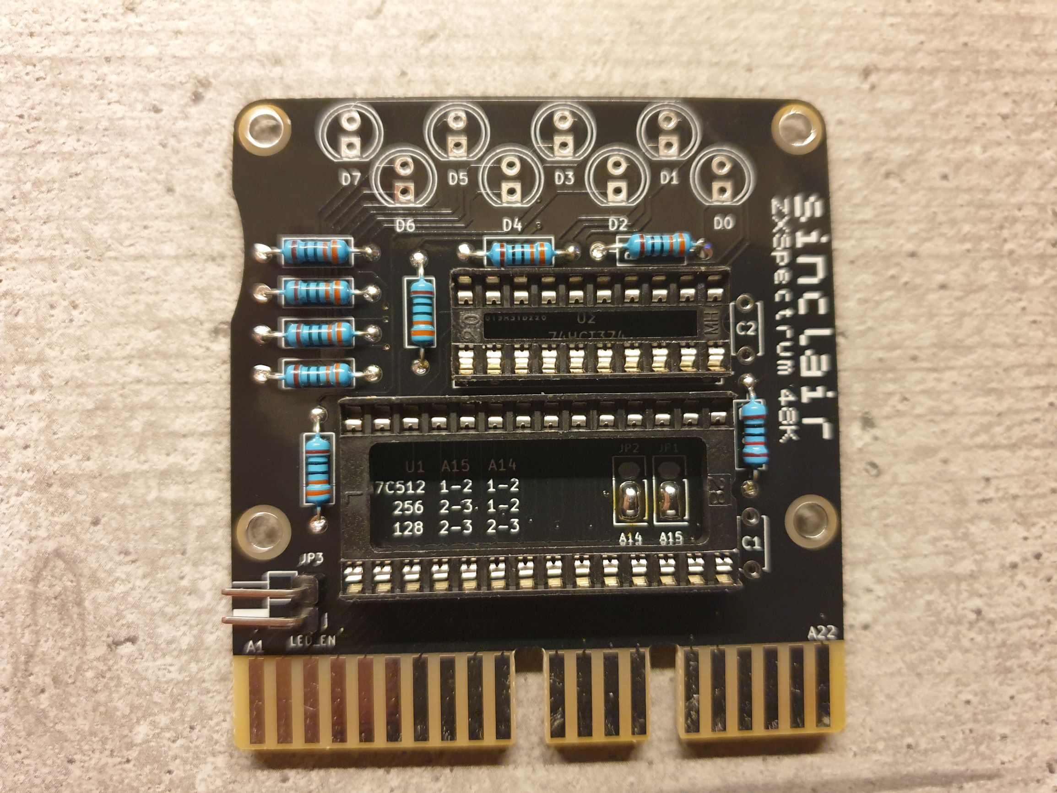
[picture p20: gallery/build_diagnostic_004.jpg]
Build cartridge 004


At this point, we've just gone ahead and added both the sockets, making sure to match the indent in the sockets with the symbols on the silkscreen - this means that pin 1 of the ICs is at the top-right corner of the sockets. Solder in the corners of the sockets first, gently reheat one pin at a time and press the socket firmly against board to avoid accidentally soldering it in at an angle (removing a socket is a lot harder than it is to solder it in).

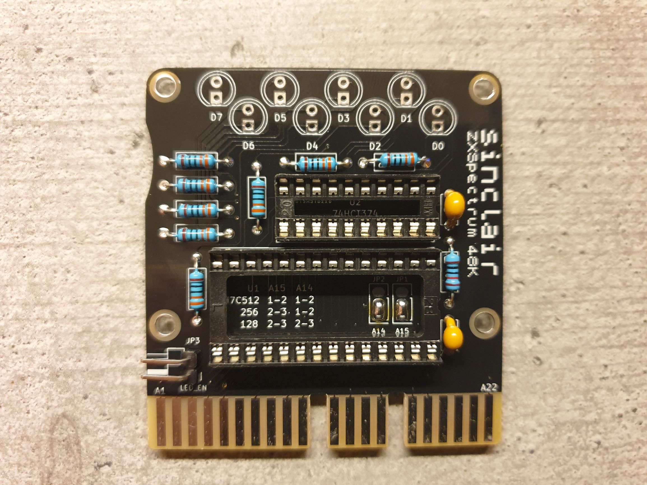
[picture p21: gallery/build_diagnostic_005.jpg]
Build cartridge 005


The ceramic capacitors do not have a polarity, so we can just solder them into place without issues. Personally I tend to ensure that the values printed on them is visible from the outside, but that's just nit-picking.

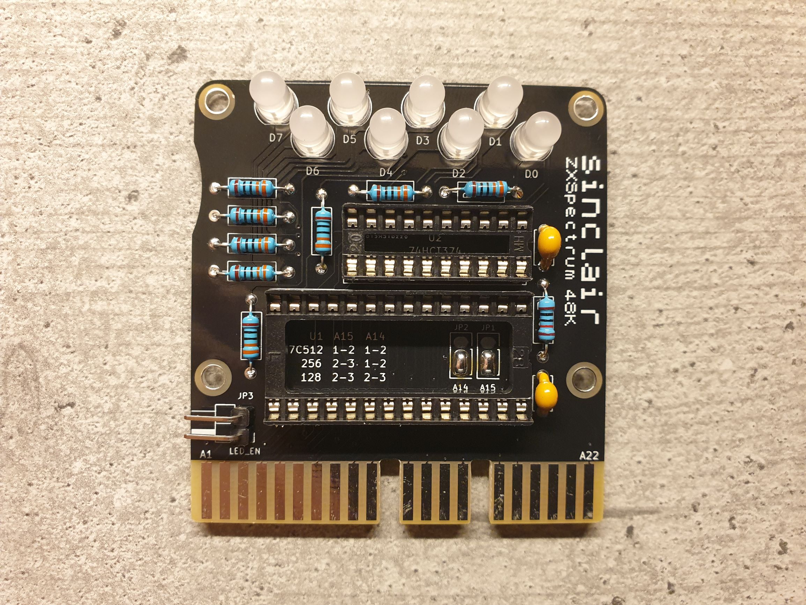
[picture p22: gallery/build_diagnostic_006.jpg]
Build cartridge 006


The last thing we're going to solder into place is the LEDs, but as they need to line up with the holes in the faceplate we'll need to take care when doing so to ensure that they're straight. Before we get that far though, we'll need to say a few words about the LEDs themselves - soldering them in the wrong way will ensure that won't work. I can never remember what the proper names of each of the pins are, so I'll just pass along the way I do it - essentially the longest lead goes into the round hole. The shorter lead, big surprise here, goes into the other hole.

Just do one row at a time, soldering in just one of the pins - then reheat and push the LED flush against the board (no matter how hard I try, they're never straight enough on the first try). When you're sure that all of them line up correctly, only then do you solder in the other pin.

Build cartridge 007

The last step that we need to do is simply inserting the chips, as has been pictured so far I've soldered the jumpers according to the settings for a 27C512-type of ROM - in this case using the W27C512 EEPROM. Make sure that you insert the chips in the correct orientation, the indent will be to the right. I put together a separate document that goes into [flashing the (E)EROMs](https://github.com/tebl/ZX-Interface-2.021/blob/main/documentation/flash_eeprom.md), the diagnostic firmware can be downloaded from the authors [github](https://github.com/brendanalford/zx-diagnostics/releases)-repository (it'll be called *testrom.bin*, this file can only be downloaded as part of the releases). Then add a jumper cap to enable the LEDs.

## 1.2> Assembling the unit
There isn't all that much that can be said for assembling the unit, chances are you've already finished the entire thing by this point. The only remaining step would just be to add a [faceplate](https://github.com/tebl/ZX-Interface-2.021/tree/main/faceplates), it helps keep the cartridge from flopping around in the cartridge slot while also adding quite a bit of visual flair to it.

Build cartridge 007

The faceplate is just a simple PCB, the suggested way of attaching it is by using components found in cheap *M3 nylon hex* kits. It will look at its best when using an 8mm nylon hex standoff (F-F), then adding screws from both sides. If, on the other hand, you want to stay within the kit - then I suggest using the 8mm M-F standoffs, add M3 nuts on the bottom and snip off the remaining part of the nylon screw that'll poke through. Add screws on top. Your success on this step will be dependent on how straight you soldered on the LEDs, so reheat and adjust any that fails to line up with the holes in the faceplate.

## 1.3> Testing it out
I shouldn't have to say it at this point, but I'll do so anyway - cartridges are not memory cards, plugging them in or unplugging them while the system is powered on will **KILL** your equipment. With that out of the way, just plug the cartridge into the slot and then apply power to see if whatever you put into the first 16K of the (E)EPROM starts up as expected. I put together a separate document that goes into [flashing the (E)EROMs](https://github.com/tebl/ZX-Interface-2.021/blob/main/documentation/flash_eeprom.md).

The ZX Spectrum doesn't actually have any knowledge of any of the bank switching logic installed on the interface, in fact the ROM in your computer will be completely disabled when any cartridge is inserted into the interface. Given that this is meant to be a diagnostic cartridge, I'll assume you've gone ahead and used Brendan Alfords diagnostic firmware as the first 16K bank - it should start automatically and run through the tests as it should.

Unless you hold down any of the buttons when starting the computer, it should run through all of the tests once and then - after a countdown - page out the diagnostic ROM and return you to the standard ZX Spectrums basic. This is normal, it just shows that the entire system for the most part works as it should. At this point you might want to try out any of the images put into the other ROM banks, I've added some more details on what to do next to the [bank_switching](https://github.com/tebl/ZX-Interface-2.021/blob/main/documentation/bank_switching.md) document.

You can control the LEDs directly from basic if you want to, they're placed on port 63 and by using the *OUT* command you can control them. All you need to do is write a value to have the LEDs display it in binary, for example the following to separately light up each row of LEDs:
```
OUT 63, 85
OUT 63, 170
```

You know you want to program an LED chaser now, you know you do! In case you're not old enough, they're what made KITT cool and the Cylons scary.

# 2> Schematic
The supplied KiCad files should be sufficient as both a schematic and as a  starting point for ordering PCBs (basically you could just zip the contents of the export folder and upload that on a fabrication site), the schematic is also available in [PDF-format](https://github.com/tebl/ZX-Interface-2.021/tree/main/documentation/schematic) and this is what you'll need to print and work your way through this things don't work as expected after assembly.

# 3> BOM
Most parts should be easy to get a hold of from your favourite local electronic component shop, but given that I don't have access to such shops where I live so everything was based on whatever I could get cheapest from eBay/AliExpress (free shipping, but plan on waiting 3-4 weeks for delivery). Components in parenthesis can be considered optional to enable basic functionality, but where's the fun in that? You deserve the complete package.

| Reference | Item | Count | Order  |
| --- | --- | ----- | --- |
| Cartridge PCB | Fabricate using Gerber files | 1 | [PCBWay](https://www.pcbway.com/project/shareproject/ZX_Diagnostic_2_021.html)
| Faceplate PCB * | Fabricate using Gerber files | (1)| [PCBWay](https://www.pcbway.com/project/shareproject/ZX_Diagnostic_2_021__Faceplate_FA1_.html)
| JP1 ** | 2pin right-angle pin-header (with jumper cap) | (1)|
| U1 | 27C128,27C256 or 27C512 (W27C512 recommended) | 1 |
| U2 ** | 74HCT374 (DIP-20) | (1)|
| C1 | 100nF ceramic capacitor (5mm pin spacing) | 1 |
| C2 ** | 100nF ceramic capacitor (5mm pin spacing) | (1)|
| R1-R8 ** | 330 ohm resistor | (8)|
| R9 ** | 10k ohm resistor | 1 |
| Mounting * | Nylon M3 hex standoffs 8mm | (4)|
| Mounting * | Nylon M3x6mm nylon screws | (4)|
| Mounting * | M3 nylon nut | (4)|  

*) The easiest way of ordering these is to just one of the M3 nylon standoff kits on ebay, AliExpress or any similar sites. That way you'll get more than what you need in various sizes for future projects as well. Check out [faceplate](https://github.com/tebl/ZX-Interface-2.021/tree/main/faceplates) section of this repository or [PCBWay shared projects](https://www.pcbway.com/project/shareproject/?tag=ZX%20Interface%202.021) for available options.

**) These components are used for the LED output, they can be considered optional for building a simple cartridge though they're recommended when you want to use it for diagnostic purposes.

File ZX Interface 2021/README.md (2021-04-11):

# ZX Interface 2.021
This is the module that the project is named after, the actual implementation of the the *ZX Interface 2.021*. Part of the hardware used within the *ZX Interface 2.021* has been designed to be functionally similar to available diagnostic cartridges, but I've also added a Sinclair joystick interface that should functionally work the same way as the original *ZX Interface 2*. 

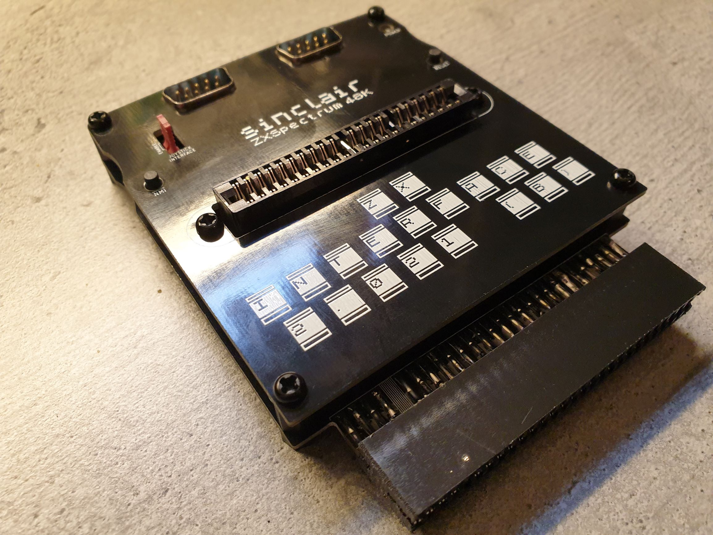
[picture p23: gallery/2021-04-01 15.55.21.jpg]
ZX Interface 2.021


While the original interface only supported 16K cartridges, severely limiting the amount of titles that could have been released for it, I didn't want to design a new interface without addressing those shortcomings. This was solved by adding a new section of pins to the end of the cartridge - these'll probably get in the way of original cartridges, but I can't afford any of those so unless someone straight-up sends me some I can't design anything for them. In theory, it should work without any changes.

ZX Diagnostic 2.021 (no faceplate)

Note that there are various faceplates available for the interface as well as the cartridges, these complete the look as well as add some sturdyness to the design. Check out the [faceplates](https://github.com/tebl/ZX-Interface-2.021/tree/main/faceplates) section for an overview over the ones that have been made available, also see [PCBWay shared projects](https://www.pcbway.com/project/shareproject/?tag=ZX%20Interface%202.021).

- [1> Building the interface](#1-building-the-interface)
  - [1.1> Soldering it together](#11-soldering-it-together)
  - [1.2> Card edge connectors](#12-card-edge-connectors)
  - [1.3> Assembling the unit](#13-assembling-the-unit)
  - [1.4> Testing it out](#14-testing-it-out)
- [2> Schematic](#2-schematic)
- [3> BOM](#3-bom)

# 1> Building the interface
Building an interface such as this assumes you have at least minor experience soldering things together, recommended is that you at least have access to a soldering station with adjustable temperature - if you can get it, you should probably start with 60/40 solder tin as the lead-free alternatives tends to be harder to work with though it's certainly a category that can be considered too cheap.

With the equipment sorted, now comes the shopping - so head on over to the [BOM](#3-bom)-section for some information on what you need. Note that with sites such as ebay, AliExpress and similar sites that sell cheap chinese components, you'll need to treat these as a suggested search term and look for something that matches the gallery pictures.

This document will only cover the actual interface, there are separate documents for the various cartridges available - at a minimum I recommend starting with the *ZX Diagnostic 2.021*, it has a few extra features that you can easily have silly amounts of fun with.

## 1.1> Soldering it together
The construction of this unit should be fairly straight-forward, just take your time in order to make sure everything goes into place - more or less straight. I usually recommend starting by having a good look at the PCBs, try to figure out where all of the listed components go and in which orientation they go in (all of this should be clearly marked on the silkscreen). 

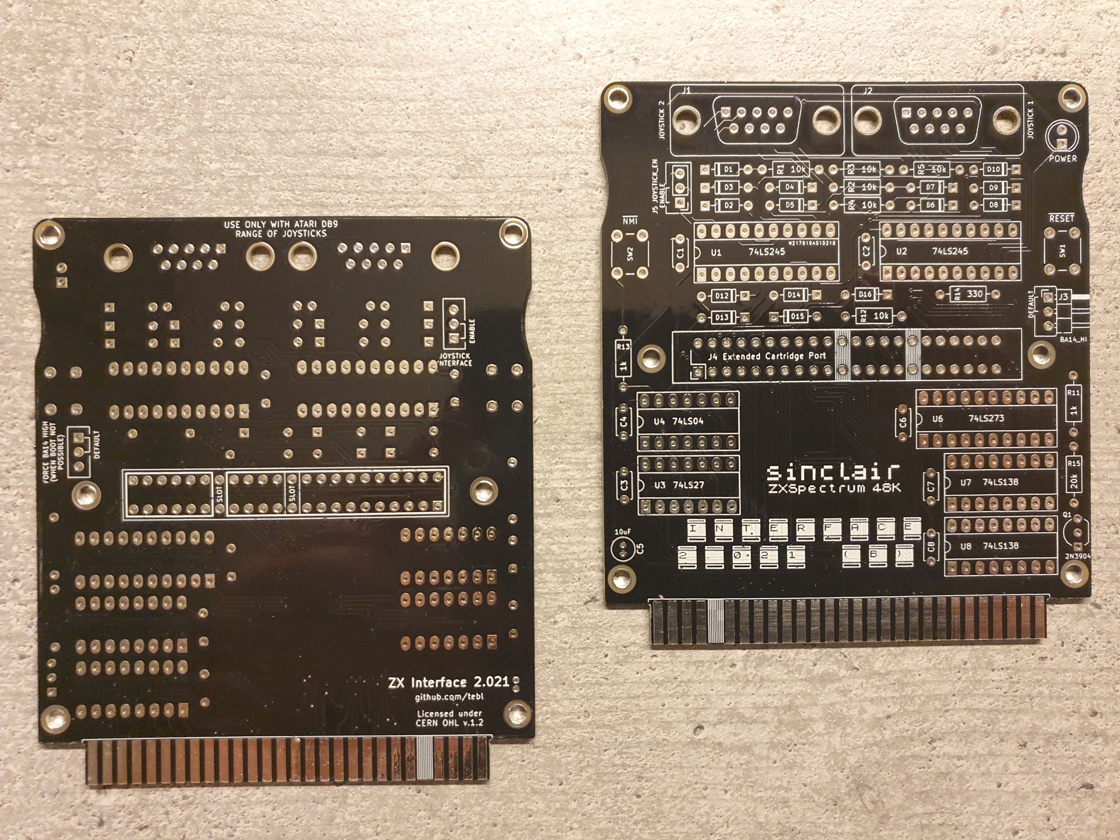
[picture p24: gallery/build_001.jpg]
Build 001


I will usually try to install components sorted by their physical size, doing it this way means you'll have an easier time keeping everything from looking somewhat crooked. This is your board, your build and you want it perfect - don't you? If you said no, then go sit in the corner because I worked hard creating this for myself and whoever wants one.

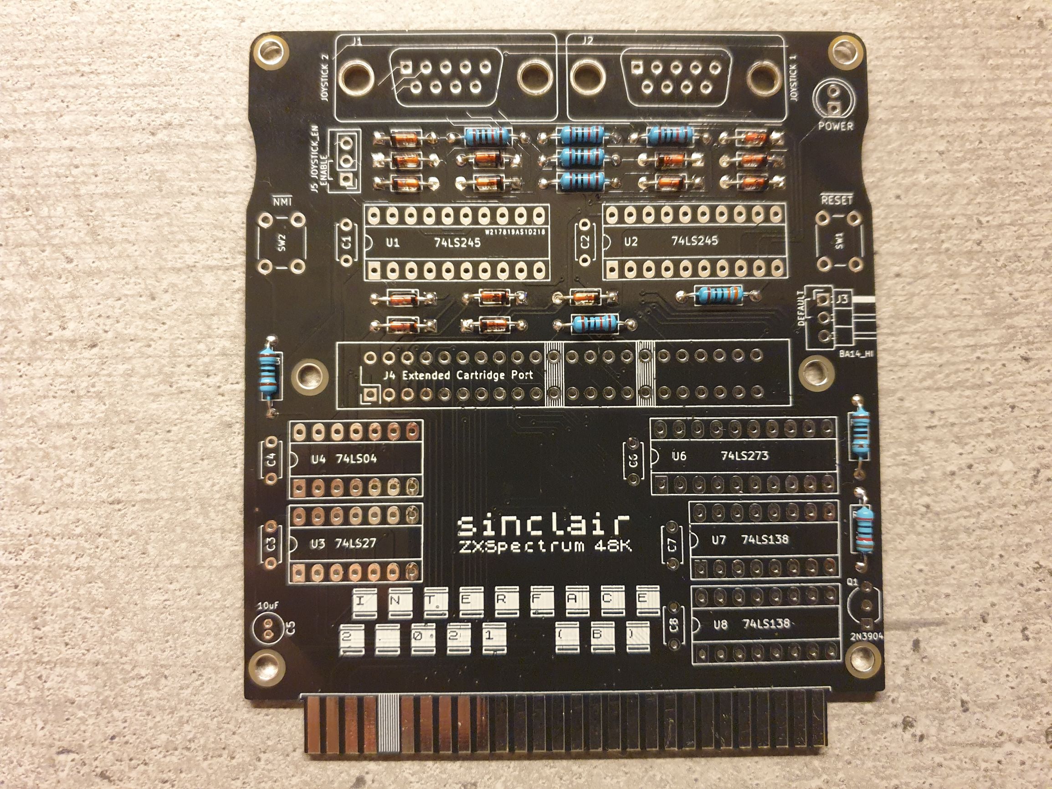
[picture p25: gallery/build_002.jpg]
Build 002


Here we've started by soldering all of the resistors, ensuring that we're using the correct values in each position. The diodes are installed similarly, but these have a polarity and so you need to install these correctly by matching up the stripe with the stripe as shown on the silkscreen.

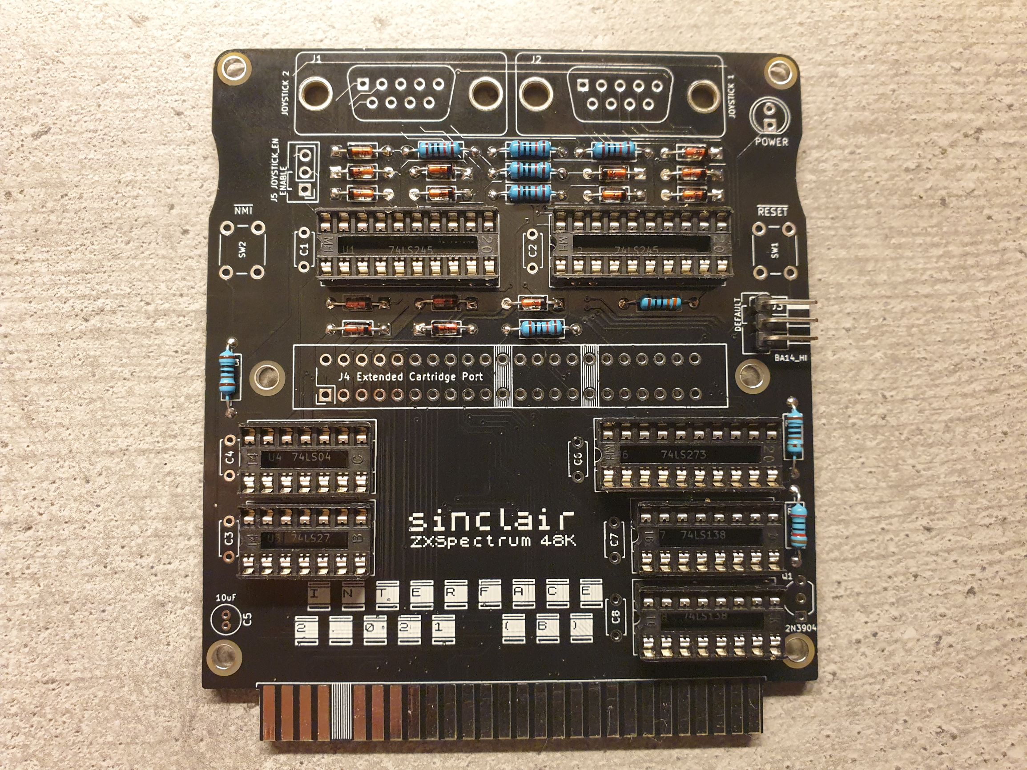
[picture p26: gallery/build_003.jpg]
Build 001


Moving things along, we've added the right-angle pin header - soldering one pin into place, then reheating and adjusting it's position so that it looks straight before soldering the rest of the pins. The sockets have been installed as well, here we've taken care to match up the indent in the socket as shown on the silkscreen - pins 1 on all of the ICs here will therefore be found on the lower-left corner. I recommend soldering in each of the corners on the sockets, but before soldering the rest - check that they're still sitting flush against the board.

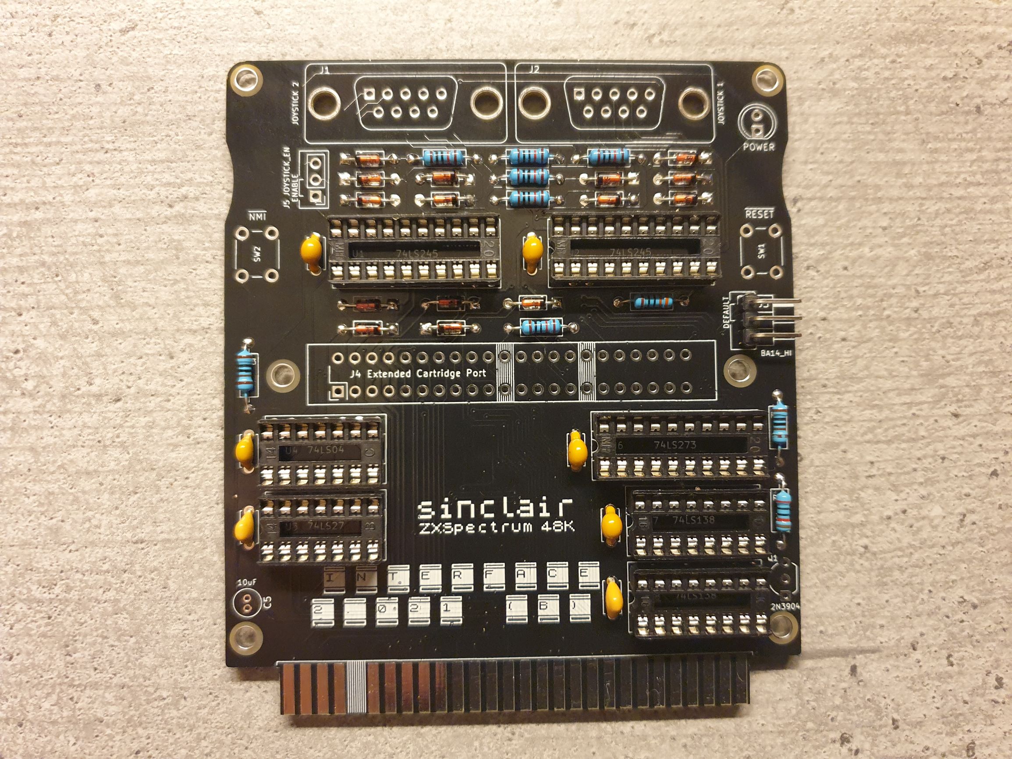
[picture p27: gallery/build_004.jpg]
Build 001


The capacitors used on this board are mainly non-polarized, these are the small yellow ones found next to the IC-sockets and these are quickly soldered into place. The electrolytic marked C5 on the other hand needs to be installed the correct way - the longer lead goes into the lower hole marked with a "*+*". Don't solder that into place yet though, you need to measure the height of the component first as we will only have space for one that is at most 8mm tall - if the ones you have are longer, you'll need to install it on it's side instead.

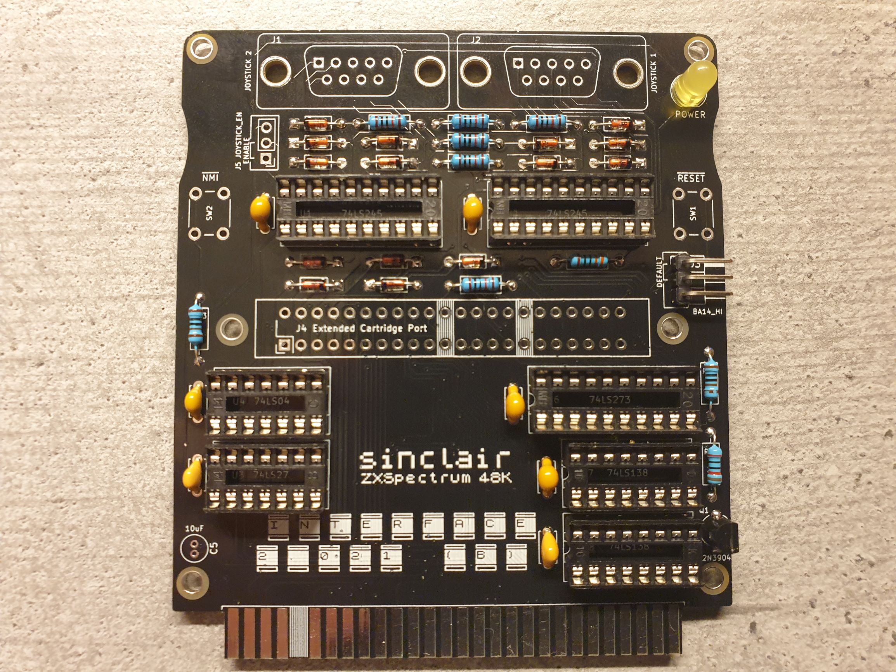
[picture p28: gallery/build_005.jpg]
Build 001


Here, the LED have been added to the PCB. These also have a specific orientation that you need to install it in, but to keep things short without actually using any of the correct terms - just put the longer lead into the round hole. Solder one of the pins into place first, then reheat and push it firmly against the board before soldering in the remaining lead. We need this to line up with the faceplate that goes on top, so you need to aim straight here. Given that this is your new power LED, this will always be lit when the computer is on - so pick a colour you find comfortable to look at (preferably not one of those awful super-bright blue ones).

At this point we'll be jumping a bit ahead in the build, mainly because there are a few components that we need to ensure will match the cutouts on the faceplate. So here I've gone ahead and soldered in the two switches, choosing something that's long enough to poke through the faceplate so that you can actually push them (or not, in case you want to force yourself to use a sharpie to push them instead). The DB9-connectors I've just screwed onto the main PCB by using longer M3 nylon screws through eight M3 nylon nuts, through the board and finally adding four more M3 nylon nuts to the underside of the board.

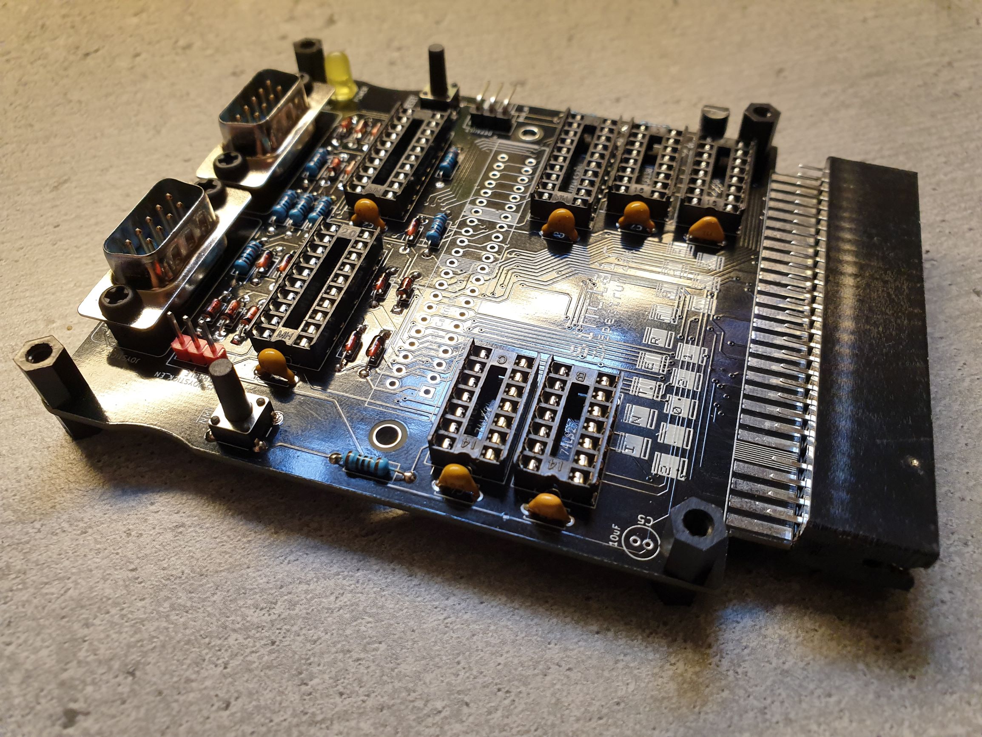
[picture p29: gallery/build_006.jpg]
Build 006


Now it's time to the install the card edge connectors that connects to the actual ZX Spectrum computer, but we'll need to cut it down for size and add a nail through it to add some keying. Given that doing this is an entirely different project by itself, at least when you're doing it for the first time - you'll find all of the details in [1.2> Card edge connectors](#12-card-edge-connectors), then come back here for the exciting continuation of this project.

Start by soldering the component, aligning the pins to the underside of the PCB without bending them in any way - keep them straight and take care that you install the keyed part with the section marked *SLOT* on the PCB. When it looks straight enough, solder in two of the opposing corners before doing the rest. At this point you need to check that the slot isn't at an angle, but looks to be parallell to the PCB. When satisfied continue soldering the rest of the pins on the underside.

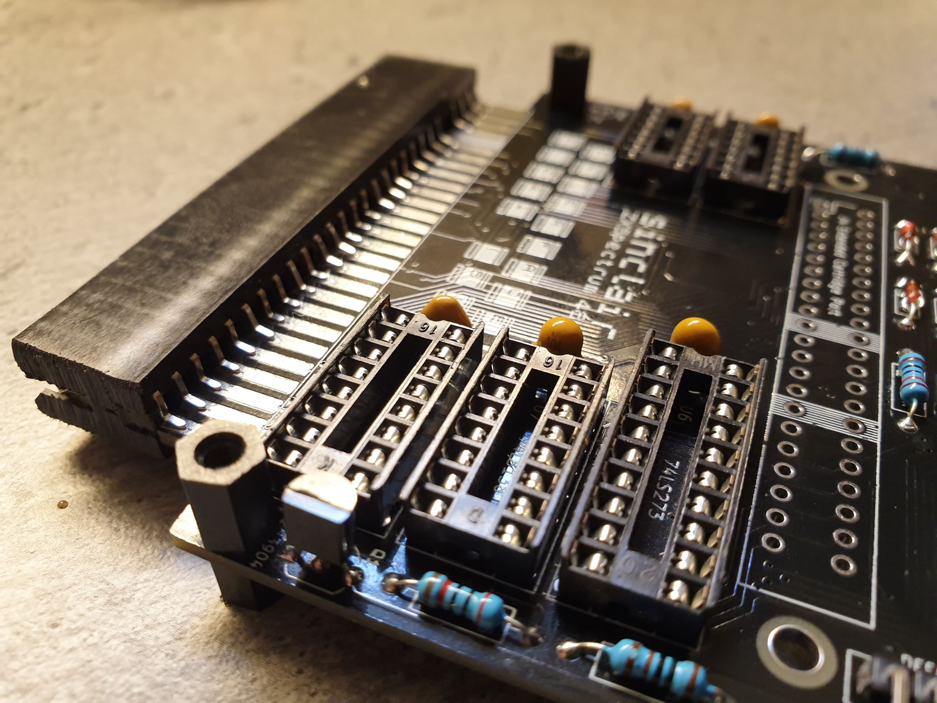
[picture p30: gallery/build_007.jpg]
Build 007


Now it's time to deal with the pins on the topside of the PCB. There are no correct way to install it as the part really has pins that are too short, but I thing you'll get the strongest joint when the pins have been bent into an L-shape like in the picture. You can easily get this shape by taking a flat-bladed screwdriver, place it onto the center of the pin and pushing it down until you get the desirable shape as you can see in the picture above. When done, recheck that the connector still is parallel to the main PCB - bend it slightly if not. Solder everything into place, as long as you don't bridge anything onto the next pin I recommend adding a *LOT* to give it some added strength.

Build 008
Build 009

The last of the big components to go into place is the cartridge connector, as with the other connector we'll need to match up the areas marked *SLOT* with the keying added. You should already have checked out [1.2> Card edge connectors](#12-card-edge-connectors), where I went into detail on how the keying part is done. Solder it into place. If you haven't already soldered the DB9-connectors into place, feel free to do so after testing that the alignment will fit snuggly with the faceplate.

Build 010

Finally, we're ready to add the jumper caps to the board as shown above - the joystick enable jumper must be in the lower position (across pins 1-2) for the Sinclair joystick interface to work. The other jumper should be kept in the upper position, this can be used to select between the two lower ROM banks of the inserted cartridge - the idea here was that with a non-functional computer you could use this to swap between two diagnostic ROMs. The various ICs have also been inserted into the sockets, taking care to match up the indented part of the chip with the socket as well as the silkscreen underneath.

At this point you should be ready to skip forward to section [1.3> Assembling the unit](#13-assembling-the-unit), mainly as we've already done everything that was described in section [1.2> Card edge connectors](#12-card-edge-connector) at an earlier stage.

## 1.2> Card edge connectors
The card edge connectors used with the *ZX Interface 2.021* widely vary in terms of quality, especially those sold from sites that primarily sell Chinese components tend to be somewhat weak. If you want one that is of a better quality, you can usually get them ready-made from Ben Versteeg at [bytedelight.com](https://www.bytedelight.com/?product=edge-connector-ready-for-zx-spectrum-a-brand). The cheaper ones are however the ones I have, so these are the ones you'll find in the pictures. If you intend to sell a completed unit to someone else, you'll probably need to look for one for sale at a more reputable electronics shop such as mouser etc.

Build 050

Cheap or expensive, unless you bought some that have already been adapted for use - we'll need to make some changes to them. If you find an ebay seller that describes them as *uncut* ZX Spectrum edge connectors, you're getting the cheap ones at a higher price - you'll still need to follow the rest of this section to adapt them for use. For the computer-side of the interface, we'll need to cut down on the width of the connector as well as add keying to it.

Build 051

Starting with the ones that plug into the ZX Spectrum computer, you'll quickly find that these are a bit too wide to actually fit the computer. At this point you'll need some sort of fine-toothed saw, I simply can't recommend attempting to chew it off - they taste rather *industrial*. A vise such as the one shown above will help quite a bit if you have one, but you could always try holding it in place. Where exactly to cut? Well, notice the little nubs on the underside of the component? Just align your saw with the inner side of these and cut straight down through the plastic, use some sanding paper or a file to clean up the edges.

This connector, as well as the cartridge slot, will require some sort of keying - this ensures that the pins line up perfectly, or at least close enough that we don't accidentally short the wrong things. These are marked on the PCB as *SLOT*, the classic way of adding them is using nails. Not even kidding, I'm totally serious.

Build 052

Start by removing the copper spring from that area, just push the pin upwards from the underside of the connector, then pull them out from the top. For the next step I recommend finding an extremely small drill, it needs to be smaller than the nail you want to use and then drill a hole along the top of the connector - leaving enough space that the nail won't simply be pulled through the plastic.

Build 053

Take your selected nail, making sure that it's not a ridiculously big one or made super-strong so that you can't cut it - think of those super-cheap ones you get with IKEA furniture, these are ones you're looking for. Push it through the holes you drilled. In order to get the head flush with the plastic, I tend to use my soldering iron to push it slightly into the plastic - this'll also ensure that it won't be going anywhere soon. Use a strong pair of pliers to cut off the remainder of the nail from the other side, try to get it as close to the plastic as you can to avoid scratching up your desk or ZX Spectrum case too much.

Build 054
Build 055

That should be it, remember that the cartridge slot will have two keying pins that you need to add, but at least you won't have to cut the actual connector. When finished, get back to section [1.1> Soldering it together](#11-soldering-it-together) to finish building the actual interface.

## 1.3> Assembling the unit
There isn't all that much that can be said for assembling the unit, chances are you've already finished the entire thing by this point - test-fitting as you went along with it. A [faceplate](https://github.com/tebl/ZX-Interface-2.021/tree/main/faceplates) might not be a requirement for building a functional interface, but it is highly recommend that you get it -  it helps keep the cartridge from flopping around in the cartridge slot. Not to mention the added visual flair!

Build 011
Build 012

The suggested way of attaching the faceplate is by using 8mm tall nylon hex standoffs between it and the main PCB, adding M3 screws from the top to fit it firmly into place. The middle section can be of the F-F kind, but the M-F will also work here. The most important part is that you need 6mm tall M3 nylon standoffs to the bottom of the PCB, this should ensure that the interface lines up with your desktop surface while plugged into ZX Spectrum computer without wobbling around - refer to the image above to see how they're assembled (just don't over-tighten them like I did).

## 1.4> Testing it out
I shouldn't have to say it at this point, but I'll do so anyway - cartridges are not memory cards, plugging them in or unplugging them while the system is powered on will **KILL** your equipment. With that out of the way, just plug any suitable cartridge into the slot and then apply power to see if whatever you put into the first 16K of the (E)EPROM comes up as expected.

With the interface connected to your ZX Spectrum computer, but no cartridge inserted - the computer should boot into ZX Basic as normal. If it doesnt't then quickly disconnect it as something will have gone wrong with the build, you should attempt to figure out what that is before powering it up again. Try comparing your built unit to the pictures earlier in this document, pay particular attention to the components that need to be installed in a specific way - especially the diodes, the transistor and the various ICs all have a specific orientation that they need to be installed in.

If it boots as normal, then you can test out the joystick interface - simply by plugging in an Atari-style joystick into any of the ports and you should get characters printed on the screen when any of the directions or the button is pushed.

ZX Spectrum Diagnostics

When you're ready to plug in a cartridge, remember to unplug the power to the computer - now that we've added that fancy new power LED, this should be easy to remember so unplug the bleeping thing. Ahem... now just plug in a cartridge you've previously built, it should start up whatever has been added as the first data bank on the inserted cartridge. This could be a a game, a diagnostic program, which was badly photographed above, or even a complete replacement for the ZX Basic.

If you want to access something in the other banks, you'll at least need a basic or some other kind of selector program in the first bank - these are all details I've attempted to describe in a separate document named [bank_switching](https://github.com/tebl/ZX-Interface-2.021/blob/main/documentation/bank_switching.md). For more information, also see the README that comes with each of the cartridges.

# 2> Schematic
The supplied KiCad files should be sufficient as both a schematic and as a  starting point for ordering PCBs (basically you could just zip the contents of the export folder and upload that on a fabrication site), the schematic is also available in [PDF-format](https://github.com/tebl/ZX-Interface-2.021/tree/main/documentation/schematic) and this is what you'll need to print and work your way through this things don't work as expected after assembly.

# 3> BOM
Most parts should be easy to get a hold of from your favourite local electronic component shop, but given that I don't have access to such shops where I live so everything was based on whatever I could get cheapest from eBay/AliExpress (free shipping, but plan on waiting 3-4 weeks for delivery). Components in parenthesis can be considered optional to enable basic functionality, but where's the fun in that? You deserve the complete package.

| Reference | Item | Count | Order  |
| --- | --- | ----- | --- |
| Interface PCB | Fabricate using Gerber files | 1 | [PCBWay](https://www.pcbway.com/project/shareproject/ZX_Interface_2_021.html)
| Faceplate PCB * | Fabricate using Gerber files | (1)| [PCBWay](https://www.pcbway.com/project/shareproject/ZX_Interface_2_021__Faceplate_FA1_.html)
| C1-C4,C6-C8 | 100nF ceramic capacitor (5mm pin spacing) | 6 |
| C5 | 10uF 25v electrolytic capacitor (2mm pin spacing) | (1)|
| D11 | 5mm LED, preferably one that is frosted | 1 |
| D1-D10,D12-D16 | 1N4148 small signal diode (DO-35) | 15 | 
| J1,J2 | D-SUB 9 Pin Male straight round pin PCB connector | 2 |
| J3 | 3pin right-angle pin-header (with jumper cap) | 1 |
| J4 | Industrial Card Edge Slot Socket Connector 22x2P 44P 2.54mm 0.1"  | 1 |
| J5 | 3pin straight pin-header (with jumper cap) | 1 |
| Q1 | 2N3904 transistor (TO-92) | 1 |
| R1-R5,R12 | 10k ohm resistor | 6 |
| R11,R13 | 1k ohm resistor | 2 |
| R14 | 330 ohm resistor | 1 |
| R15 | 20k ohm resistor | 1 |
| SW1,SW2 | 6x6x9mm momentary switch | 2 |
| U1,U2 | 74LS245 (DIP-20) | 2 |
| U3 | 74LS27 (DIP-14) | 1 |
| U4 | 74LS04 (DIP-14) | 1 |
| U6 | 74LS273 (DIP-20) | 1 |
| U7,U8 | 74LS138 (DIP-14) | 2 |
| Z1 | Industrial Card Edge Slot Socket Connector 28x2P 56P 2.54mm 0.1"  | 1 |
| Metal nails | Small metal nails used for keying edge connectors | 3 |
| Mounting ** | Nylon M3 hex standoffs 6mm (F-F) | 6 |
| Mounting ** | Nylon M3 hex standoffs 8mm (M-F) | (6)|
| Mounting ** | Nylon M3x6mm nylon screws | 6 |
| Mounting *** | Nylon M3x10mm nylon screws | (4)|
| Mounting *** | M3 nylon nut | (12)|  

*) Check out [faceplate](https://github.com/tebl/ZX-Interface-2.021/tree/main/faceplates) section of this repository or [PCBWay shared projects](https://www.pcbway.com/project/shareproject/?tag=ZX%20Interface%202.021) for available options. The default one will be linked as the order URL.

**) These are used in various places of the project. You can usually find some kits for M3 nylon standoffs, but given the amounts we're using - it's a good idea to order extras as well. The F-F variants won't be included with the tip, but with some creative cutting and combining things you should be able to achieve the same results - the important part is the heights between the components. When not installing a faceplates you'll be able to save on these, just keep the 6mm tall standoffs on the bottom.

***) These are used when bolting the DB9 connectors to the PCB - you can do without them, but in order to reduce the wear and tear on the main PCB I recommend installing them. You can't add these after the DB9-connectors have been soldered into place, at least not easily.

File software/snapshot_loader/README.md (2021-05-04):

# Snapshot Loader
The ZX Spectrum wasn't originally designed to have cartridge support, I assume this was due to the rather excessive costs involved in creating one-off hardware like this at the time when it was designed. The expansion connector at the back of the computer did however have the capability of disabling the system ROM found inside the machine, no doubt with the intention of allowing peripherals to upgrade the machine in this way.

This is what they did with the release of the Sinclair Interface 1, replacing the built-in ROM with one that supported the Microdrive and RS232 hardware that it added. The Interface 2 that was released sometime later did not come with a ROM by itself, this was moved onto individual cartridges like what people at that point had come to expect. The did however make a few mistakes, the biggest one was designing it in a way that made it hard to access more than the initial 16K ROM found on the cartridge - at a time when games had started to adopt the larger capabilities of the 48K machines. While I've sought to improve the hardware side of things when designing the *ZX Interface 2.021*, it still sees software in 16K segments and we need some software to handle switching between the available 16K banks of data (see [bank switching](https://github.com/tebl/ZX-Interface-2.021/blob/main/documentation/bank_switching.md) for a more general description on how that is done).

The *Snapshot Loader* is actually the second loader I've written for the *ZX Interface 2.021*, the other is the [Cartridge Loader](https://github.com/tebl/ZX-Interface-2.021/tree/main/software/cartridge_loader) and handles the traditional 16K ROM-files available for the ZX Spectrum. Back to the *Snapshot Loader* again, this one instead of dealing with ready-made cartridge images focuses on snapshot-files ([*.SNA*](https://worldofspectrum.org/faq/reference/formats.htm) files) - more than likely created by the computer itself (using additional hardware such as the Multiface).

The snapshot, when created freezes the contents of a running program by copy all parts of the running computer - the entire 48K of RAM, as well as the CPU registers added to the start of the snapshot as a header. So in order to restore a snapshots, we'd just need to restore all of the RAM and set the CPU registers equal to what it was when the computer was frozen. All of that is easy stuff, on an emulator. When doing it on the computer itself, it's an entirely different situation as you need at least some of those register to keep track of where we are in the process - essentially counting fingers, breaking one off for every step. Anyway, that's my explanation for the state of the code.

When it comes to the final steps of the restoration process, we need to bank out the code we're running in order to get back the standard ZX Spectrum ROM. Doing this when running code from the ROM at the same time is a guaranteed crash of some sort, so we'll need to use some small amount of RAM for this part of the program (13 bytes to be specific) and jump to that location to run it. This location is referred to as the *LOADER_ADR* by the assembly code, *LoaderAddress* in the [Snapshot Creator](https://github.com/tebl/ZX-Interface-2.021/tree/main/software/cartridge_creator) and if this is left at the default value of 0x0000 (2 bytes) - we'll attempt to figure this out for ourselves. The strategy for doing this is to take the snapshots SP-value (Stack Pointer) and subtract 17 addresses and place the program there (we're leaving 4 bytes for actual stack usage). The routine will then perform a *RETN*-instructions, normally only used to end interrupt handlers that pop the current stack value and resume the program from there (this value will have been added when the snapshot was created).

 That should just about cover it when it comes to describing what the *Snapshot Loader* does, but for those that just want to create their own cartridge compilations and have fun doing that - I've put together a [Cartridge Creator](https://github.com/tebl/ZX-Interface-2.021/tree/main/software/cartridge_creator) that will do most of the heavy lifting when it comes to dealing with the loader.

# 1> Assembling the code
This section is mostly for those that want to reprogram parts of the loader, the binary files are included in the repository so unless you want to assemble it yourself there shouldn't be a need to actually do so. The program is written in Z80 Machine Language, and as everyone who's attempted to do so - there is a lot of differences in the code due to the various dialects used by the assembler, every program therefore needs to be paired with the assesmbler it was written for.

The one I'm using is the [SB-Assembler 3](https://www.sbprojects.net/sbasm/index.php), it is open source and written in [Python](https://www.python.org/) so you should be able to use it on all common platforms without issues - just download and unzip the assembler files somewhere you'll be able to find them. I'm using Windows, for some reason, so there are batch-files accompanying the source code - these assume that you've added the location of the assembler in your PATH-variable. Double-click the file named *__assemble.bat* to assemble the output, then pause to allow you to actually see the command-line output before the batch execution finishes.

I've tried quite a few solutions for developing, assembling and testing out code for the ZX Spectrum and most of them quite simply don't work or can be considered more *proofs of concept* rather than usable setups. Your mileage may wary though, but this is the state of things as I see it. Most emulators are quite good at playing games, but they have varying amounts of helpful tools when it comes to testing out new code. For developing the *Cartridge Loader*, a cartridge ROM, the solution that worked for me was the ZXSpin emulator and using *Tools -> Options... -> ROM Images* and setting *ROM Image* to point to the file generated by the assembler (*snapshot.rom*).

ZXSpin Options

# 2> References
Everything comes from something, so does every bit of code created from earlier code found in manuals and blogs. Particularly helpful was a series of blog posts on a site called [Break into program](http://www.breakintoprogram.co.uk/) which in addition of a copy of *Spectrum Machine language for the absolute beginner* by William Tang inspired most of the code. The bugs are probably all mine.

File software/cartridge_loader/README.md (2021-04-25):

# Cartridge Loader
The ZX Spectrum wasn't originally designed to have cartridge support, I assume this was due to the rather excessive costs involved in creating one-off hardware like this at the time when it was designed. The expansion connector at the back of the computer did however have the capability of disabling the system ROM found inside the machine, no doubt with the intention of allowing peripherals to upgrade the machine in this way.

This is what they did with the release of the Sinclair Interface 1, replacing the built-in ROM with one that supported the Microdrive and RS232 hardware that it added. The Interface 2 that was released sometime later did not come with a ROM by itself, this was moved onto individual cartridges like what people at that point had come to expect. The did however make a few mistakes, the biggest one was designing it in a way that made it hard to access more than the initial 16K ROM found on the cartridge - at a time when games had started to adopt the larger capabilities of the 48K machines. While I've sought to improve the hardware side of things when designing the *ZX Interface 2.021*, it still sees software in 16K segments and we need some software to handle switching between the 16K banks.

Boot screen

The *Cartridge Loader* is the software-side of my solution for supporting more than one 16K games or applications on a single cartridge. Placing it in the first 16K bank of a cartridge, will allow the routines to prepare the computer for running machine code (setting up CPU registers and so on) before showing a boot screen. In order to allow us to switch out the first 16K bank for something else, we'll need to relocate the program into RAM instead before starting to execute instructions from there instead. At this point the user will be presented with a menu, selecting one of the items will switch over to the specified bank and at this point we can start the program we want to run. Check out the [documentation](https://github.com/tebl/ZX-Interface-2.021/blob/main/documentation/) for a separate document on [bank switching](https://github.com/tebl/ZX-Interface-2.021/blob/main/documentation/bank_switching.md).

Loader menu

 That should just about cover it when it comes to describing what the *Cartridge Loader* does, but for those that just want to create their own cartridge compilations and have fun doing that - I've put together a [Cartridge Creator](https://github.com/tebl/ZX-Interface-2.021/tree/main/software/cartridge_creator) that for the most part automates dealing with the loader.

# 1> Assembling the code
This section is mostly for those that want to reprogram parts of the loader, the binary files are included in the repository so unless you want to assemble it yourself there shouldn't be a need to actually do so. The program is written in Z80 Machine Language, and as everyone who's attempted to do so - there is a lot of differences in the code due to the various dialects used by the assembler, every program therefore needs to be paired with the assesmbler it was written for.

The one I'm using is the [SB-Assembler 3](https://www.sbprojects.net/sbasm/index.php), it is open source and written in [Python](https://www.python.org/) so you should be able to use it on all common platforms without issues - just download and unzip the assembler files somewhere you'll be able to find them. I'm using Windows, for some reason, so there are batch-files accompanying the source code - these assume that you've added the location of the assembler in your PATH-variable. Double-click the file named *__assemble.bat* to assemble the output, then pause to allow you to actually see the command-line output before the batch execution finishes.

I've tried quite a few solutions for developing, assembling and testing out code for the ZX Spectrum and most of them quite simply don't work or can be considered more *proofs of concept* rather than usable setups. Your mileage may wary though, but this is the state of things as I see it. Most emulators are quite good at playing games, but they have varying amounts of helpful tools when it comes to testing out new code. For developing the *Cartridge Loader*, a cartridge ROM, the solution that worked for me was the ZXSpin emulator and using *Tools -> Options... -> ROM Images* and setting *ROM Image* to point to the file generated by the assembler (*loader.rom*).

ZXSpin Options

# 2> References
Everything comes from something, so does every bit of code created from earlier code found in manuals and blogs. Particularly helpful was a series of blog posts on a site called [Break into program](http://www.breakintoprogram.co.uk/) which in addition of a copy of *Spectrum Machine language for the absolute beginner* by William Tang inspired most of the code. The bugs are probably all mine.

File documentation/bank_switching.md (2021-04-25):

# Bank switching
The cartridges I've designed can utilize (E)EPROM chips with a size larger than the original 16k, but while the program put into the first 16K of the ROM will start automatically as you would normally expect - accessing software placed in the other 16K banks requires something more than that. An essential bit of information to start with, is that the ZX Spectrum was never designed with any knowledge of the cartridge system added later. Additionally, inserting a cartridge completely deactivates the ROM found within the machine - it's simply not there anymore, taking with it all hope of sharing routines between them without straight out copying them into your own program.

That solution is creating a small launcher program that goes into the first bank, it would then ensure that each cartridge can be started properly - setting up CPU registers, RAM contents and so on. What we've got now is a ZX Spectrum running code from the first bank, but when the bank is switched out - it'll still attempt to execute reading instructions from the same ROM location. The CPU is completely oblivious to the fact that the program previously stored there has disappeared and more problematically, something else has appeared there instead. That's a recipe for a crashed CPU - no actual damage, it just won't be doing anything sensible until we reset the computer. The launcher program should solve this by copying itself into RAM, then start executing it from there before doing any of the actual bank switching. 

The [Cartridge Loader](#2-cartridge-loader) program is my solution for all this, it is also described in more detail later in this document. If you would like to learn a bit more about the bank switching routine, I recommend playing around with the functionality in a more direct fashion - check out the [Doing it manually](#1-doing-it-manually) section for this.

# 1> Doing it manually
Doing it manually is a bit hit and miss for the reasons previously explained, but it does allow us to learn about the interface when doing so. We'll need a program in the first bank that'll actually allow us to do something, so we'll need some sort of basic ROM in the first slot. You can use a copy of the original ZX Spectrum ROM, alternatively you can use any of the rather excellent replacements instead. Both [OpenSE BASIC](https://sourceforge.net/projects/sebasic/) or the [Gosh wonderful ROM](https://k1.spdns.de/Vintage/Sinclair/82/Sinclair%20ZX%20Spectrum/ROMs/gw03%20'gosh%2C%20wonderful'%20(Geoff%20Wearmouth)/gw03%20info.htm) will be perfectly suited for this task.

When booted up into either of the basics, you can then do a write to port 31 in order to manaully control the bank switching logic. You need to enter the value in the form of a decimal number, but it will be easiest to list it up as individual bits (as each bit is used for different things):

| BIT | 0 | 1 | 2 | 3 | 4 | 5 | 6 | 7 |
| --- | ---- | ---- | ---- | ---- | ---- | ---- | --- | --- |
| | BA14 | BA15 | BA16 | BA17 | BA18 |  /EN | ROM_SEL0 | ROM_SEL1 |

The *ROM_SEL* bits can be used to select one of four ROM chips addressed on a cartridge, bits 0 through 4 is used to select the 16K bank within the chip (not all of which may be available, depending on the type of ROMs installed on the cartridge). Bit 5 deactivates the cartridge, effectively reactivating the ROM chip found within the ZX Spectrum computer.

For now we'll just attempt to select between the four 16K images flashed onto a 27C512 (64K) (E)EPROM, it has then been inserted into the *ROM 0* socket on a *ZX Spectrum 2.021* cartridge. The 27C512 only has two extra address lines, so only values written to BA14 and BA15 will have an effect on the bank switching. ROM banks can be selected by writing a value between 0 and 3, to select the second bank we'll write a 1 to port 31:
```
OUT 31,1
```
Either it works or it just crashed the basic, try hitting the *NMI* button to see if that fixes it. Using the reset button will reset the bank switching circuit, returning us to whatever we had in the first bank.

Try some of the other values until you find something to have fun with. Setting bit 6 high allows you to access banks on the *ROM 1* socket, meaning you'd write value from 64 through 67 instead.

# 2> Cartridge Loader
As previously mentioned, the Cartridge Loader is a program intended for flashing into the first 16K bank of any of the regular ZX Interface 2.021 cartridges - it is the first thing that runs when the computer is powered up with the cartridge inserted. Because I couldn't help myself and had already commited to using the entire 16K bank for this purpuse, I added a pretty little boot screen to it as well. Note that there is also a specific [Cartridge Loader](https://github.com/tebl/ZX-Interface-2.021/tree/main/software/cartridge_loader) page, this is where you'll find more information on tools used to assemble the code.

Boot screen

The loader functions in a two-stage manner, the first thing it'll do is copy itself out of the ROM and into the computers RAM then it'll start executing instructions from that location - this is done while the boot screen is being displayed. Relocating the code to RAM avoids the common bank switching pitfalls, as the RAM stays where it is while we switch around the ROM banks. Once all of that is done, the program will display a menu - allowing the user to select from any of the other 16K banks (using either a joystick or the keyboard keys as listed on the screen).

Loader menu

You can find the [Cartridge Loader](https://github.com/tebl/ZX-Interface-2.021/tree/main/software/cartridge_loader) as a file named [loader.rom](https://github.com/tebl/ZX-Interface-2.021/blob/main/software/cartridge_loader/loader.rom), make sure that you click the *Download*-button on that page instead of right-clicking and selecting *save link as* - we want to save a copy of the ROM and not a web page describing it. You can refer to the document [Flash (E)PROM](https://github.com/tebl/ZX-Interface-2.021/blob/main/documentation/flash_eeprom.md) for more details on manually combining ROM-files and then flashing them onto an (E)EPROM.

The [So BASIC!](https://github.com/tebl/ZX-Interface-2.021/tree/main/software/cartridge_creator/cartridges/basic) cartridge can be found at the link provided, this is suitable for flashing onto a single 27C512 or W27C512 (E)EPROM. As I did not want to manaully edit assembly files in order to create a new cartridge such as this one, I've also created a [Cartridge Creator](https://github.com/tebl/ZX-Interface-2.021/tree/main/software/cartridge_creator) tool - this takes care of assembling the images into the correct positions, updating titles and even changing the boot screen.

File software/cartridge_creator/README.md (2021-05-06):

# Cartridge Creator
The *ZX Interface 2.021* supports more than a single 16K cartridge program, using a [bank switching](https://github.com/tebl/ZX-Interface-2.021/blob/main/documentation/bank_switching.md) technique implemented on the interface itself. Unfortunately the computer has no concept of how to deal with bank switching by itself, so the we'll to add some sort of software to the machine to help it along.

ZX Interface 2.021

These are the various loader programs found within the repository, the first one is [Cartridge Loader](https://github.com/tebl/ZX-Interface-2.021/tree/main/software/cartridge_loader) and allows you to create compilations of 16K ROM files such as those released for the original ZX Interface 2 (complete with a boot screen and menu to select between them). The second one is the [Snapshot Loader](https://github.com/tebl/ZX-Interface-2.021/tree/main/software/snapshot_loader) and allows you to load and restore a snapshot file from the cartridge.

I did not want to change the assembly source every time I wanted to change out the program content or any of the settings, nor did I want the user to deal with installing an assembler and making them learning how to use it - the solution I came up with for all this is the *Cartridge Creator*. In reality it's just a fancy name for a [Python](https://www.python.org/) script, but it takes out a lot of the trial and error that would usually be associated with trying to do a lot of little things manually.

- [1> Requirements](#1-requirements)
- [2> Using the tools](#2-using-the-tools)
  - [2.1> Creating a blank cartridge](#21-creating-a-blank-cartridge)
    - [2.1.1> Creating a standard cartridge](#211-creating-a-standard-cartridge)
    - [2.1.2> Creating a snapshot cartridge](#212-creating-a-snapshot-cartridge)
  - [2.2> Verifying a cartridge](#22-verifying-a-cartridge)
  - [2.3> Processing cartridge](#23-processing-cartridge)
- [Appendix A> Command-line arguments](#appendix-a-command-line-arguments)
- [Appendix B> Cartridge defition](#appendix-b-cartridge-definition)
  - [B.1> 'standard' cartridge](#b1-standard-cartridge)
  - [B.2> 'snapshot' cartridge](#b2-snapshot-cartridge)
- [Appendix C> Attributes](#appendix-c-attributes)

# 1> Requirements
The scripts do not require anything other than a standard installation of [Python](https://www.python.org/), it should be available for all of the modern operating systems. though I don't have the ability to test on anything other than my Windows laptop. There will be some Windows batch included in the project, you can use them if you prefer or you can have a look at their contents to determine what they're attempting to do. 

The *Cartridge Creator* should come with everyting you need to use it, *loader.rom* as well as the fonts are from the [Cartridge Loader](https://github.com/tebl/ZX-Interface-2.021/tree/main/software/cartridge_loader) - that is also where you'll find source code can be found for these files. Likewise, there are also files from the [Snapshot Loader](https://github.com/tebl/ZX-Interface-2.021/tree/main/software/snapshot_loader) that will be used depending on the arguments used with the tool. The batch files *assemble.bat* and *copy_loader.bat*, respectively take care of assembling the machine code as well as copy the resulting files into the expected locations. For regular use, unless you want to change parts of the code, you probably don't want deal with these directly and so you wouldn't need to go through installing the assembler I'm using.

# 2> Using the tools
The *Cartridge Creator* is a command-line tool, it does not come with a graphical interface (for us Windows users starting up a new *Command Prompt*, usually just referred to as *cmd.exe*). You can get a brief descriptions of what each of the possible arguments that you can give by doing the following:
```
python cartridge.py --help
```
From looking at the file hierarchy, you can see that there is a subfolder called *cartridges* - when the tool refers to a cartridge name, it'll be a named directory found here. Supplied as part of the repository, you should have two of them already - one of them is a "blank" cartridge with placeholders that you can use as a template,  the other is a collection of BASIC replacements that can be used with the ZX Spectrum. The tool works by parsing the *_cartridge.ini* found within the folder. See [Appendix A> Command-line arguments](#appendix-a-command-line-arguments) for a more comprehensive description.

Cartridge Creator

## 2.1> Creating a blank cartridge
The tool comes with the command-line arguments for creating a new blank cartridge, this mostly just creates the directory structure as well as a few of the files that are needed for it to generate a cartridge. Most of the contents should be considered placeholders, so after running the command you'll need to edit the file *_cartridge.ini* afterwards.

As there are two different loaders included in the project, there's two different cartridge types that can be created using the same tool. The **standard** cartridge are those created for use with the [Cartridge Loader](https://github.com/tebl/ZX-Interface-2.021/tree/main/software/cartridge_loader), this variant allows you to create compilations of 16K ROM files such as those released for the original ZX Interface 2 (complete with a boot screen and menu to select between them). The second is the **snapshot** cartridge, they're created using the [Snapshot Loader](https://github.com/tebl/ZX-Interface-2.021/tree/main/software/snapshot_loader) - allowing you to restore a snapshot file from a cartridge.

### 2.1.1> Creating a standard cartridge
The [ZX Cartridge 2.021](https://github.com/tebl/ZX-Interface-2.021/tree/main/ZX%20Cartridge%202021) installing two chips on the board itself, so you have the option of using 1 or 2 chips on these boards. The interface itself supports up to 4 chips, which is why the *Cartridge Creator* also support that **number** of chips. You will need to specify the size of (E)EPROMs that you intend to use as well as the number of these chips that you are going to install on the cartridge.

When there is a reference to the **size** of an (E)EPROM, this refers to the name of the chips that are used. When using a 27C512, you'd specify 512 here - 27C256 is 256 etc. In case you were wondering how a 64K (E)EPROM came to be specified as a 512, it's mainly just marketing - listing as thousands of Kilobits (Kb) instead of KiloBytes (KB) made it look like it was significantly more than you got. Just divide the number by 8 to get a sensible number, dividing that further by 16 gets you the number of 16K banks that we can put on the chip. The first bank will always be used by the [Cartridge Loader](https://github.com/tebl/ZX-Interface-2.021/tree/main/software/cartridge_loader), meaning that for a 512 chip we'll be able to fit 3 banks of data on it (4 on subsequent chips).

Cartridge Creator

To create a new standard cartridge called *test*, using a single 27C512 chips you'd issue a command like the following (note that this will overwrite the contents if you specify a name already in use):
```
python cartridge.py --create test --chip-size 512 --chip-count 1
```
As long as the command finishes without any errors, you should now have an empty cartridge definition to work with - if you named it *test* as in the example, then you'll find the files in the directory named *cartridges/test*. You can refer to the pictures below.

Cartridge Creator
Cartridge Creator

As I went into detail on earlier, we have 3 slots available on a 512 chip (ROM 0-0 is taken up by the [Cartridge Loader](https://github.com/tebl/ZX-Interface-2.021/tree/main/software/cartridge_loader)). You can customize what you want in here, it is a configuration format just about anyone wanting to deal with old hardware should have come across before. The easiest ones to tackle are the titles, all you need to do is put in what you want here - as long as you keep it under 30 characters and don't use any weird non-ASCII characters.

For the ROMs, you just copy them into the folder and then copy the FileName into the file. The *blank.rom* just displays an image on the screen, so it is actually a valid ZX Spectrum machine code program though you'll no doubt have more interesting things to put in the slots. If you just want something to test things out with, you can find a few of the original cartridge titles on [www.fruitcake.plus.com](http://www.fruitcake.plus.com/Sinclair/Interface2/Cartridges/Interface2_RC_Cartridges.htm), they've also got a set of [Cassette Conversions](http://www.fruitcake.plus.com/Sinclair/Interface2/Cartridges/Interface2_RC_New_3rdParty_GameConversions.htm) that I've enjoyed immensely.

The *Cartridge Creator* also supports replacing a few of the assets used by the [Cartridge Loader](https://github.com/tebl/ZX-Interface-2.021/tree/main/software/cartridge_loader), you can uncomment the **BootScreen** option and supply it with a filename to change out the boot screens that shows when the computer is started. It expects a ZX Spectrum SCR-file, these can either be created by saving the contents of a screen in a ZX Spectrum emulator or you can download something from [zxart.ee](https://zxart.ee/eng/graphics/top-rated/) (click on the title of the picture to get to the download links).

**Font1** is used for the title at the top, **Font2** is used for the rest. The value here should match any of the fonts found within the fonts-directory, the case is ignored and the name corresponds to a file named *fonts/font_<name>.bin*. The fonts were adapted for the ZX Spectrum by Jim Blimey and there are pictures of each one on his [blog](https://www.jimblimey.com/blog/24-zx-spectrum-fonts/).

### 2.1.2> Creating a snapshot cartridge
The snapshot cartridge, allows you to use ZX Spectrum [*.SNA*](https://worldofspectrum.org/faq/reference/formats.htm)-files instead of the traditional 16K ROM-files supported by the standard cartridge. What this means is that you aren't limited by the original 10 titles released for the ZX Interface 2, instead you'll have access to thousands of them instead. The [Snapshot Loader](https://github.com/tebl/ZX-Interface-2.021/tree/main/software/snapshot_loader) takes care of most of the complexity running on the ZX Spectrum itself, but the *Cartridge Creator* will take care of packaging the 48K snapshot data along with the loader itself on a single 27C512 or W27C512 (E)EPROM chip.

Cartridge Creator

To create a new snapshot cartridge called *test*, you'd issue a command like the following (note that this will overwrite the contents if you specify that is already in use):
```
python cartridge.py --create test --cartridge-type snapshot
```
As long as the command finishes without any errors, you should now have an empty cartridge definition to work with - if you named it *test* as in the example, then you'll find the files in the directory named *cartridges/test*. You can refer to the pictures below.

Cartridge Creator
Cartridge Creator

The file *_cartridge.ini* defines how the script works, for the most part it should be familiar to anyone who's ever taken look at a standard ini-file before (given that you're interested in old stuff, I'll take that bet). Most of the settings that are there at the moment can be considered placeholders and while you actually could run it as it is, it probably won't be all too exciting stuff apart from showing that everything works as expected.

Put the snapshot-file that you want to use and copy it into the folder, then change the *FileName* option to match. The only other setting that you might need to deal with is *LoaderAddress*, it is used to override the current behavior of [Snapshot Loader](https://github.com/tebl/ZX-Interface-2.021/tree/main/software/snapshot_loader) when it comes to the final steps necessary to restore the snapshot - it is a routine that needs to be stored in RAM as we'll be banking out the cartridge in favor of the original ZX Spectrum ROM. Leaving it commented out or set to 0x0000, means that we'll try to put this routine below the system stack - possibly overwriting some parts of the program. If you experience a program where this destroys something that is needed for the game to work, you can specify a different address to use here instead. Finding a suitable location may require loading the snapshot in an emulator, then opening up the debugger or memory browser within it and look for a space that is at least 17 bytes then try again.

## 2.2> Verifying a cartridge
Somehow I ended up writing a lot of verification code to ensure that the options entered into the cartridge definition, for a description of most of the stuff that goes into them - see [Creating a blank cartridge](#21-creating-a-blank-cartridge). The idea is that you run through the verification routines and it spits out most of your errors in an understandable format.

The following command verifies the cartridge definition for a cartridge named *test*:
```
python cartridge.py --verify test
```
The output from my system is shown below, you just go through the list and ensure that the status of each task is listed with an *OK* in the second column. Relevant parameters should be listed along with it, check these sections of the configuration if you encounter any errors among the way - usually this is due to errors in filenames specified.

Cartridge Creator

## 2.3> Processing cartridge
Processing a cartridge means actually going through the routines to generate the resulting *.bin* files (as well as Intel HEX files), these are the files that you need when you want to [flash your (E)EPROMs]([flashing](https://github.com/tebl/ZX-Interface-2.021/blob/main/documentation/flash_eeprom.md)). It's recommended that you [verify the cartridge](#22-verifying-a-cartridge) before going on with this step, mainly to catch the more obvious mistakes before using these routines - mainly because of the information overload.

The following command verifies the cartridge definition for a cartridge named test:
```
python cartridge.py --process test
```

The output from running this command on my system is shown below. The most important part is to ensure that the output is generated without any errors, for the most part you just check that most have a result listed as *OK*. The easiest is for the most part is to look for the part that reads *(E)EPROM image* near the end and ensure that it says *Size OK*, after that it'll have listed the status of the operation that took care of generating some Intel HEX files for use with your (E)EPROM Programmer.

Cartridge Creator

Note that depending on the type of cartridge specified, you may have more than one output file generated and you should in those cases use the same size of (E)EPROMs and in the capacity specified (mixing of sizes is not supported by any of the loaders). As previously mentioned, head on over to [flashing (E)EPROMs](https://github.com/tebl/ZX-Interface-2.021/blob/main/documentation/flash_eeprom.md) for instructions on using one of the more common (E)EPROM Programmers (Minipro TL866).

# Appendix A> Command-line arguments
The main executable script file, *cartridge.py* supports a number of command-line arguments - most of which should be straight-forward. Most of the commands take a directory name as one or more parameters, these should correspond to a directory found within the *cartridges*-directory and will be referred to as *<dirname>*. Where certain arguments are only relevant in combination with a specific cartridge type, I've listed those specifically under *Cartridge type*.

| Argument | Cartridge type | Description |
| --- | --- | --- |
| -c, --create <dirname> | | Creates one or more empty cartridges, with <dirname> as specified. See *-t* to specify which cartridge type is used on creation, *standard* will be used if nothing else is specified.
| -cs, --chip-size <size> | standard | When creating a standard cartridge, specifies the size of the (E)EPROMs to be used. Specify 512 for 27C512, the number must be a multiple of 128 as that is the smallest unit.
| -cc, --chip-count <number>  | standard | When creating a standard cartridge, specifies the number of (E)EPROMs to be physically installed on the cartridge. Valid values are from 1 to 4.
| -t, --cartridge-type <type> | | When creating a cartridge, this specifies the type of cartridge that will be created. Valid types are either *standard* or *snapshot*.
| -p, --process <dirname> | | Processes a cartridge definition, <dirname> specifies the name of directory found within the *cartridge*-subdirectory. The command will generate *.bin*- and *.hex*-files to be flashed onto one or more (E)EPROMs (depending on cartridge type).
| -h, --help | |  List recognized program arguments
| -v, --verify <dirname> | | Verifies the contents of a cartridge definition, <dirname> specifies the name of directory found within the *cartridge*-subdirectory. The command will attempt to sanity check all configured options. This step is recommended before you --process a definition.
| --version | | Displays the scripts name and version, for reference. When in doubt, try to update and use the latest version of the files. 

# Appendix B> Cartridge definition
A cartridge definition will be named *_cartridge.ini*, found within the a named subdirectory within the folder named *cartridges* ([commands](#appendix-a-command-line-arguments) expects this in place of "*<dirname>*"). The structure of the file should be familiar to anyone with a passing experience with *.ini*, standard in the last truly great version of *MS Windows (3.11)*.

Cartridge Creator

The configuration is divided into sections, the start of each of these is specified by placing the name of them within square brackets. Options are specified by name, value after the equal sign as expected. Any lines starting with a semi-colon have been commented out, the program will usually add most of these as an example of what is supported. Several cartridge types are supported, but given that they have different behavior these will be described in separate subchapters - note that some of these will have more than one section.

## B.1> 'standard' cartridge
Cartridge Creator

| Section | Option | Required | Description |
| --- | --- | --- | --- |
| **[Cartridge]**  | | Yes | Start of the cartridge definition.
| | Title | Yes | Specify the name of the cartridge, this will be displayed at the top of the menu screen. Supports up to 30 ASCII letters.
| | ChipSize | Yes | Specifies the size of the (E)EPROMs to be used, it is specified as it is specified on the chip themselves - in thousands of kilobits. Specify 512 for 27C512 and so on, the number must be a multiple of 128.
| | ChipCount | Yes | Specifies the number of (E)EPROMs to be physically installed on the cartridge, valid values are from 1 to 4.
| | BaseName | Yes | Specifies the filename used when generating files (*.bin* and *.hex*)
| | BasePath | | Specifies a base-path used for all generated files (*.bin* and *.hex*), using a relative value such as "..\\..\\" will place files in the main script directory.
| | BootScreen | | Specify the filename of an SCR-file that will be used as a boot screen, this will be displayed for a few seconds before displaying the menu. For a tool to create your own, see [img2spec](https://github.com/jarikomppa/img2spec)
| | Font1 | | Specifies the name of the font that will be used for the title-section of the menu. The font name is expected to correspond to a file within the *fonts*-directory, named in the format of *font_<name>.bin*
| | Font2 | | Same as above, except this affects the text used in the other sections of the menu such as the slot titles.
| **[ROM X-Y]** | | Yes | Specifies the start of a slot definition, X designates the chip ID with Y specifying slot ID (the IDs are numbered from 0). Note that these must be specified according to *ChipCount* and *ChipSize* specified, as the *Cartridge Loader* program takes up [ROM 0-0] there is no definition for it.
| | Title | Yes | Specifies the title of a specific slot, it will be displayed in the menu as a selectable title. Supports up to 30 ASCII letters.
| | FileName | Yes | Specifies the name of the ROM-file, the file is expected to have been placed within the cartridge definition folder.
| **[Attributes]** | | | Can optionally be used to specify text attributes used with various parts of the cartridge menu, see [Appendix C> Attributes](#appendix-c-attributes) for more information on valid combinations of values.
| | Border | | Specify the colour of the border while displaying the boot screen, usually to match the **BootScreen** used. Only supports colours, other attributes are not supported.
| | BorderMenu | | Specify the colour of the border when displaying the menu, Only supports colours, other attributes are not supported.
| | DefaultText | | Default text attributes, this is used when normally displaying text.
| | ProgramTitle | | Specify the attributes used with the program title at the top of the menu, also controls the appearance of the box around the title section.
| | CartridgeTitle | | Specify the attributes used with the title of the cartridge, as specified by the *Title*-option in the *Cartridge*-section.
| | InactiveRow | | Used on rows corresponding to slots that are currently not selected.
| | ActiveRow | | Used on the row corresponding to the currently selected slot.
| | HelpText | | Used with the help text at the bottom of the screen, usually giving instructions for valid key combinations.
| | ErrorText | | Appearance of text on the error screen (if you are lucky enough to find it).
| | ErrorTitle | | Appearance of title on the error screen (if you are lucky enough to find it).

## B.2> 'snapshot' cartridge
Cartridge Creator

| Section | Option | Required | Description |
| --- | --- | --- | --- |
| **[Cartridge]**  | | Yes | Start of the cartridge definition.
| | Type | Yes | Defines the type of cartridge that this file describes, for a *snapshot* cartridge this must be set to **snapshot**,
| | BaseName | Yes | Specifies the filename used when generating files (*.bin* and *.hex*)
| | BasePath | | Specifies a base-path used for all generated files (*.bin* and *.hex*), using a relative value such as "..\\..\\" will place files in the main script directory.
| | LoaderAddress | | Can be used to specify where the last bit of the snapshot loader routines will be placed in RAM, this will override the default behavior of trying to place it directly below current stack pointer. The routines require 13 bytes of memory, the only way of figuring out a suitable place may be to use an emulator.

# Appendix C> Attributes
The **standard** cartridge type functions by adding a menu that is loaded from the first ROM slot, enabling you to interactively select between the remaining available slots. The menu appearance of the menu can be customized through the use of relevant definition keys, see [Appendix B> Cartridge definition](#appendix-b-cartridge-definition) for more information on what these are. Attributes is specified by adding the name to the value, separating multiple values by spaces where this is possible (borders only support a single colour). The following case-sensitive values are recognized:

| Name | Description |
| --- | --- |
| BLACK |
| BLUE |
| RED |
| MAGENTA |
| GREEN |
| CYAN |
| YELLOW |
| WHITE |
| BLACK_PAPER |
| BLUE_PAPER |
| RED_PAPER |
| MAGENTA_PAPER |
| GREEN_PAPER |
| CYAN_PAPER |
| YELLOW_PAPER |
| WHITE_PAPER |
| BRIGHT | Affects colour brightness. Bright colours are the clearest, non-bright colours have a darker and slightly muddier appearance.
| FLASH | The contents will flash, colour attributes for text and paper will alternate.

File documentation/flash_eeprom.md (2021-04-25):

# Flash (E)PROM
The various cartridges for the *ZX Interface 2.021* utilizes common (E)EPROM chips of varying sizes, from 27C128 to 27C512. These are commonly EPROMs, meaning that they are UV-erasable programmable ROM chips - this requires a separate device to consistently erase the contents of the chips. Personally, I tend to instead look for EEPROMs as they are electrically ereasable instead - a common alternative is the W27C512, which is also the one I recommend purchasing unless you already have suitable chips in a drawer somewhere.

Flashing contents onto the chip requires a dedicated programmer for this, the one I recommend purchasing is the MiniPro TL866CS if you can find it. It doesn't support all of the extremely old ROM chips, but it will support just about anything that is commonly available for a reasonable price. I've not had any need to look for anything else, so I can't cover any of the other tools available. The remainder of this document will therefore assume the use of a MiniPro TL866, for anything else I'll just assume you know how to use it.

- [1> Combining images](#1-combining-images)
  - [1.1> Combining ROMs](#11-combining-roms)
  - [1.2> Padding out images](#12-padding-out-images)
- [2> Using MiniPro TL866](#2-using-minipro-tl866)

# 1> Combining images
The ZX Spectrum cartridge format has a hardware-defined 16K size, more modern cartridge alternatives as well as the ones I've created for the *ZX Interface 2.021* are still required to handle data in chunks of 16K segments. You can switch out the segment that the CPU currently sees by using a technique called [bank switching](https://github.com/tebl/ZX-Interface-2.021/blob/main/documentation/bank_switching.md). Most of the software, in particular the original releases will therefore be available as 16K files with a rom extension though you might come across files that are less than this - especially when first starting to develop your own programs in machine code. See [1.2> Padding out images](#12-padding-out-images) if you are looking for an easy way to pad it out to 16k in size.

If all of this sounds like it's a bit more work than you'd like to deal with, then I've got news for you - I did so too. So I made the [Cartridge Creator](https://github.com/tebl/ZX-Interface-2.021/tree/main/software/cartridge_creator), it takes care of assembling the image for you and taking care of updating menu titles and so forth. The following sub-sections deal with doing this in a more manual fashion, either because you want to assemble it yourself or because you don't want my fancy loader and want something else instead. A ready-made cartridge, in form of the [So BASIC!](https://github.com/tebl/ZX-Interface-2.021/tree/main/software/cartridge_creator/cartridges/basic) cartridge is available as an example of the cartridges this generates.

When you're ready to continue, meaning that you have your *.bin* or *.hex* file ready to go, skip on over to [Using MiniPro TL866](#2-using-minipro-tl866) for instructions on how to flash those onto an (E)EPROM.

# 1.1> Combining ROMs
There are many ways of combining binary files, but as MS Windows is among the most problematic when it comes to doing simple command line tasks it is the one I'll be covering. You can use the *COPY* command with a parameter for treating the data as binary, then you'll list each of the filenames with a plus in between - ending with the filename you need. Ensure that the resulting file has a reasonable file, meaning it's 32K or 64K - depending on the ROM size used. 
```
copy /B file1.rom + file2.rom 27c256_image.bin
copy /B file1.rom + file2.rom + file3.rom + file4.rom 27c512_image.bin
```
Combining files

# 1.2> Padding out images
I've encountered a few ROM-files that have a size smaller than 16k, usually this just means that unused data has been left out - when combining files we do however need those empty bytes. The easiest way of handling this is following the steps in [2> Using MiniPro TL866](#2-using-minipro-tl866), configuring the chip to be a 16K variant such as the 27C128 and then loading the image into the memory using *File -> Open*. Then just save the image using *File -> Save*, specify bin as the file type and you'll have a perfectly padded 16K file.

# 2> Using MiniPro TL866
In order to flash data onto the ROM chip we'll need a suitable file in either BIN- or HEX-file format, see [1.1> Combining ROMs](#11-combining-roms) if you don't have any of them ready to go. You could always just use a 16K image by itself with a larger chips, it just means that all of the other ROM banks will have nothing in them.

Flash 002

Starting with the *MiniPro Programmer* software, it'll look something like what is shown above. There'll be the name of a specific ROM chip under the section titled *Select IC* - more than likely it'll be the wrong one (you need to match the chip as well as manufacturer information exactly or you will get errors along the way). Click the button to get the dialog as shown below, enter a search term such as W27C512 - it's a Winbond manufactured part.

Flash 003

The main window will now be updated, the main data display will be blanked out as well (in case you had tried loading data into it earlier) and updated to reflect the exact size of the chip. You're now ready to load data into the program, just use *File -> Open* and find the file you've already prepared for this.

Flash 004

The next dialog just allows you to specify how the file is loaded into the program, mainly it should detect automatically what you need to do here. The only interesting bit here is, if you want to use *MiniPro Programmer* to combine images instead of the method described in [1.2> Combining ROMs](#12-combining-roms) - in which case you need to specify a new address in the *To Buffer Strat. Addr(HEX)* value to a different starting point (usually $0000, $4000, $8000 or $C000), then set *Clear Buffer when loading the file* to *Disabled*.

Flash 005

Verify that the data window shows data where you expect it to be, but as it is Z80 machine code most will be unreadable thought you'll probably see some recognizable text here and there. Given a 64K ROM, you should see individual 16K banks starting at $0000, $4000, $8000 and $C000.

Flash 006

Flash 007

The final steps is actually flashing the chips, use *Device -> Program* to open up the programming dialog as shown below. You'll then need to put the ROM chip into the programmer, matching the pin layout as shown. Finally, click *Program* to actually program the chip.

Flash 008
Flash 009
Flash 010

Hopefully the chip will have programmed successfully as shown in the screenshot above. If you get a chip ID error, then that usually means that either you've selected the wrong manufacturer for the chip you have - or - the chip you have was rebadged at some point, in which case you should get your money back. If the data verification failed, meaning the data read back from the chip was not the same as was written - then you've got a bad chip and need to get another one.

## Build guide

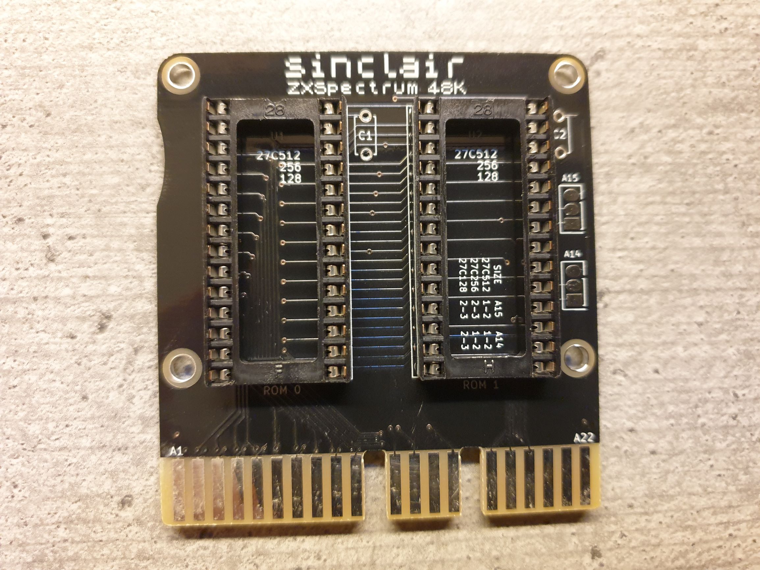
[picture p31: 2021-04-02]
gallery/build_cartridge_002.jpg

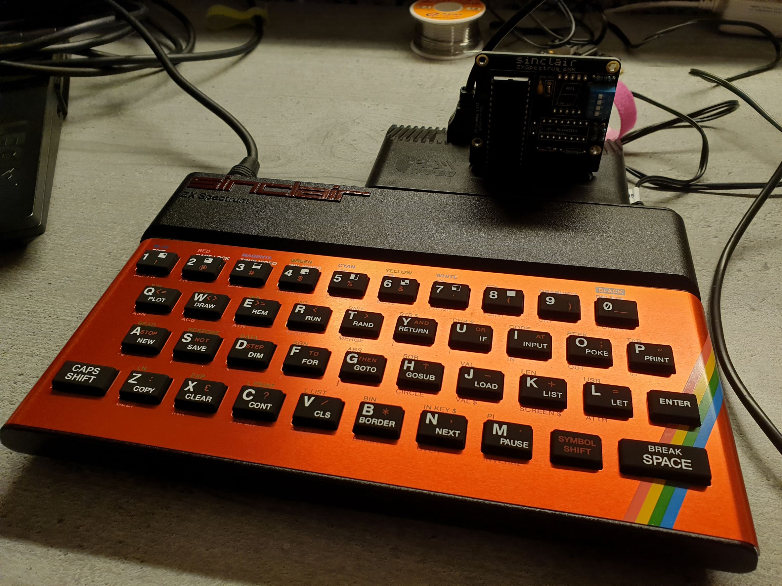
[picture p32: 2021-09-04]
gallery/build_cartridge_1983_009.jpg

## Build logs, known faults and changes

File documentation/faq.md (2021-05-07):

# FAQ
You probably have a lot of questions and while I sometimes appear to have them, they're usually a best-effort sort of thing. Electronics is not my day job, I actually don't one as I'm currently suffering from a chronic illness that severely limits my ability to function beyond basic day-to-day stuff. I dabble in electronics when I have the energy to do so, because everyone needs a hobby and I find that building simple things gives me a sense of accomplishment though it might not seem like much to actual EE-engineers.

The files made available through any of my repositories are free, but that those not mean that they come without any sort of limitations. Read through the [LICENSE](https://github.com/tebl/ZX-Interface-2.021/blob/main/LICENSE.txt) if you want to, but for most practical purposes - the most important one is that the software and hardware designs come without anything even resembling a warranty. If you soldered it together, you take full responsibility for it (intended or accidental). If you connected it, ran it or powered it up - you're still responsible. I will however attempt to help you to the best of my abilities.

For anything else not answered up until this point, I've attempted to organize things into relevant sections below. Again, to the best of my abilities - which may at times be somewhat limited.

- [1> General](#1-general)
  - [1.1> Why did you make it?](#11-why-did-you-make-it)
  - [1.2> How can I help?](#how-can-i-help)
  - [1.3> Is this the same as a ZX Interface 2?](#13-is-this-the-same-as-a-zx-interface-2)
  - [1.4> Can I use my original cartridges?](#14-can-i-use-my-original-cartridges)
  - [1.5> Can I sell these?](#15-can-i-sell-these)
  - [1.6> Did you design this from scratch?](#15-did-you-design-this-from-scratch)
- [2> Hardware](#2-hardware)
  - [2.1> Can you build me one?](#21-can-you-build-me-one)
  - [2.2> Where can I get the PCBs?](#22-where-can-get-the-pcbs)
  - [2.3> Is it compatible with the…?](#23-is-it-compatible-with-the)
  - [2.4> What joysticks can I use?](#24-what-joysticks-can-i-use)
  - [2.5> Where’s the BOM?](#25-wheres-the-bom)
  - [2.6> It doesn’t work, why doesn’t it work?](#26-it-doesnt-work-why-doesnt-it-work)
- [3> Software](#3-software)
  - [3.1> How do I put something on my cartridge?](#31-how-do-i-put-something-on-my-cartridge) 

# 1> General
## 1.1> Why did you make it?
As previously mentioned, probably because I saw it done somewhere or read about it somewhere - and - wanted one. I mainly build simple things, usually related to 8bit computers as most of those were at one point simple enough that I can figure out how the work using various descriptions found online or in my extensive library of outdated reference books.

Usually I enjoy drawing or building projects more than using them, so if I can - I do it is as a little hobby project rather than just buy one that is ready-made (as long as the skills required appears to be within my limitations). I can spend a month doing tiny little increments, build it and if it works - I usually just put it in a drawer and wonder about what to do next.

When it comes to the expensive stuff, I can't afford them. So my options are either to save up for them over extended periods of time or build them. For the excessively expensive stuff, I have to convince myself that I don't need them.

## 1.2> How can I help?
There are many ways that you can help out with projects such as this, the easiest way is to just share your pictures and the fun you had building and using it - that's inspiring for aspiring hobby-tinkerers such as myself. If you find problems and have some bit of knowledge that you feel should exist somewhere within the repository, that is also a great way to contribute.

A PCB is cheap once it is ready for use, but there are usually several versions that never worked sufficiently - every time, I'm paying out of my own pocket to the PCB fabrication company, shipping and finally the import fees collected by the country where I live. For these three alone, a project usually is in the scale of a few hundred dollars. When ordering PCBs via projects that I've shared on [PCBway](https://www.pcbway.com/project/member/?bmbno=04C9EDC7-08B5-43), you can get one without dealing with most of the difficult questions as well as give me a small discount on my next order - you can also get a list of all projects related to the [ZX Interface 2.021](https://www.pcbway.com/project/shareproject/?tag=ZX%20Interface%202.021).

If on the other hand, you'd like to buy me a cup of coffee instead - there's a button below for that stuff.



## 1.3> Is this the same as a ZX Interface 2?
The original ZX Interface 2 from Sinclair used a custom IC that doesn't have any direct replacements, which is why the ZX Interface 2.021 uses quite a lot of components in an attempt to replace it. One feature that the original interface supports, that my version of the interface does not - is the machine can't tell the difference between a keyboard press and a button or direction pushed on any of the joystick ports. For all practical purposes, both interfaces function the same.

[Bank switching](https://github.com/tebl/ZX-Interface-2.021/blob/main/documentation/bank_switching.md) was added directly to the Interface 2.021, this means that you no longer need to implement this on every cartridge. Building a [ZX Cartridge 2.021](https://github.com/tebl/ZX-Interface-2.021/tree/main/ZX%20Cartridge%202021) only requires the (E)EPROM and nothing else, meaning that you can easily build all of the cartridge you'd ever want with just a handful of components.

Yes, but no - mostly it's  more.

## 1.4> Can I use my original cartridges?
I don't own any original cartridges, I can't even afford them and I've never actually seen one - so I can't give you a straight answer here. What I can say is that I've tested it with reproduction cartridges that were designed for the original ZX Interface 2, those worked without any issues so it's unlikely that you'd have any issues using them. If in doubt, send me an original cartridge - I promise that someone'd have to pry it from my cold, dead hands to get it back from me. 

## 1.5> Can I sell these?
Yes, but please treat your customers kindly - be prepared to support them as I have limited capacity to do so. Don't charge more than what is reasonable. If you'd like to support the project, consider contributing towards improving the project with your experiences from doing so. I'd appreciate it if you ordered your PCBs via my [PCBway shared projects](https://www.pcbway.com/project/shareproject/?tag=ZX%20Interface%202.021), but I understand that you'd probably use your own favourite PCB fabrication company. Alternatively, you could simply buy me a coffee instead.



## 1.6> Did you design this from scratch?
No. I'm not good enough to just intuitively know how everything works - not even by sniffing the air around it, which is something I can't do since I simply don't own one. When it comes to technology, nothing ever comes out of nothing - everything is built upon the knowledge on things that came before it. I've tried to maintain a list of my primary sources of information when it comes to the inner workings of this design below, mainly because I repeatedly fail at finding my previous set of bookmarks. It's a safe assumption to consider that the bugs added, are probably mine alone.

* http://www.users.globalnet.co.uk/~jg27paw4/yr01/yr01_58.htm
* http://www.users.globalnet.co.uk/~jg27paw4/yr03/yr03_19.htm#Buffer
* http://www.users.globalnet.co.uk/~jg27paw4/yr04/yr04_25.htm
* https://k1.spdns.de/Vintage/Sinclair/82/Doityourself/IF2%20cartridges/
* https://blog.gjmccarthy.co.uk/wp-content/uploads/2019/12/how.html
* http://www.fruitcake.plus.com/Sinclair/Interface2/Interface/Interface2_Circuitry.htm
* http://trastero.speccy.org/cosas/droy/cartuchos/cartuchos_s.htm

# 2> Hardware
## 2.1> Can you build me one?
I unfortunately don't have the energy necessary to build more than my own prototypes, which is why they're available for *free* instead of being put on a web-shop somewhere. That's a good thing, it means you have everything I have so you can build as many as you'd like. At times there *may* be other people selling them, so consider asking on facebook groups related to the computer this project belongs to.

I take pride in doing simple things that anyone with access to decent tools should be able to build - using only the cheapest ebay parts. If someone is charging more than a moderate amount of money for them, I recommend you build it yourself - you'll enjoy it more as well.

## 2.2> Where can I get the PCBs?
- You can ask in your favourite facebook group, in particular those that specificly discuss vintage computers, to see if someone has extras.
- You can order them from [PCBway](https://www.pcbway.com/setinvite.aspx?inviteid=88707), that way you don't need to deal with Gerber files and figure out how to fill in the order forms. Add them to the cart, then someone from PCBway will come along and verify that everything looks right - only at that point can you pay for the order. Check out my [shared projects](https://www.pcbway.com/project/shareproject/?tag=ZX%20Interface%202.021) related to the *ZX Interface 2.021*.
- You can have them produced used the Gerber-files found within this repository, usually what they'll want is a zipped-up copy of the files found within each projects *export* directory. Fill in the options you need, what you'd need is two-layer PCB though there might be a few different values you'd need to fill in correctly.

## 2.3> Is it compatible with the...?
If the *...* is a *ZX Spectrum 48K* computer, either the rubber-keyed one that we all know and love - or - the *ZX Spectrum+*. Clones of these computers should also work, in fact I'm primarily using it on a ZX Harlequin 48K computer - which is why mine is the white variety as shown below.

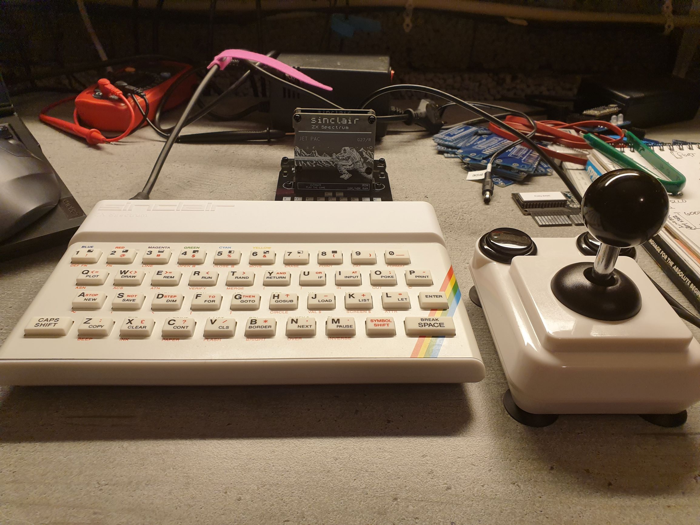
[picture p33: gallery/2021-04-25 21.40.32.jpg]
ZX Harlequin


For anything else, probably not.

It might work, it might not work, it might kill your computer and/or peripheral that you somehow managed to connect together. This is not a limitation of my design, for the most part it is the limitations of the original hardware. Most peripherals of the day simply weren't meant to be used together and without detailed of how a peripheral functions - I couldn't even pretend to know what would happen if you chose to combine them.

Except tape players, those are safe.

## 2.4> What joysticks can I use?
Contrary to popular misconceptions, the original ZX Interface 2 supported standard Atari-style joysticks. The pinouts were shuffled around with the release of the ZX Spectrum +2 computer, this was an attempt by new owner - Amstrad - to force their customers to buy their vastly inferior SJS-line of joysticks.

The ZX Interface 2.021 retains the original port pinouts, meaning that most Atari-style joysticks should function properly as long as it doesn't require a power source to work. Most joysticks produced for the Atari 2600, Commodore 64, Commodore Amiga or simply marked Kempston-compatible should be sufficient.

## 2.5> Where's the BOM?
The BOM (*Bill of Manufacturing*) is the list of components needed to build the ZX Interface 2.021, so where is it? That depends on your definition of what a BOM should look like. I unfortunately can't afford the rather extreme import and shipping costs associated with ordering from mouser, digikey and similar professional sites, so I can't provide you with the specific part numbers for those sites as I don't have the ability to verify their suitability - I would rather redesign to avoid parts that are only found on those sites. Sorry, but until the country I live decide that importing across country-lines isn't an inherent evil - then this probably won't change.

The parts I use primarily come from sources such as ebay, aliexpress or banggood. Unfortunately these sites aren't exactly known for being particularly detailed when it comes to sales listings, but on the other hand most of them only sell the same parts. My BOMs can therefore be considered as a general search query, then usually you'd need to compare the pictures to see if the listing matches what has been used. This does lead to some open questions, this is unavoidable, but usually you could order a couple of different options for a modest amount of money.

Each of the main project modules have their own BOM, most of them should have been linked here: 
- [ZX Interface 2.021](https://github.com/tebl/ZX-Interface-2.021/tree/main/ZX%20Interface%202021#3-bom)
  - [ZX Diagnostic 2.021](https://github.com/tebl/ZX-Interface-2.021/tree/main/ZX%20Diagnostic%202021#3-bom)
  - [ZX Cartridge 2.021](https://github.com/tebl/ZX-Interface-2.021/tree/main/ZX%20Cartridge%202021#3-bom)
- [ZX Cartridge 1.983](https://github.com/tebl/ZX-Interface-2.021/tree/main/ZX%20Cartridge%201983#3-bom)

## 2.6> It doesn't work, why doesn't it work?
I try my best to make my designs easy to build, but that doesn't mean everyone's guaranteed success on their first attempt at building one. All is definitely not lost though, what you've earned is the perfect chance to learn more than you've bargained for. Start by doing a visual inspection, check that every components that have a polarity (meaning that they go in a certain way) is in the same orientation as can be seen in the pictures. Look for jumpers that are missing, pins you've forgotten to solder or simply accidentally bridged.

With all of the easy stuff out of the way, now comes the time that you'll need to learn how to decipher a [schematic](https://github.com/tebl/ZX-Interface-2.021/tree/main/documentation/schematic). They're more of a logical view of how the components work together, not the physical location of them, but you shouldn't have any problems finding out which part part connects given the time - a pro tip is to print it to paper and then mark, note down your findings along the way. The designs are simple and should for the most part be easy to follow using a multimeter, allowing you to observe or decide how to isolate the problem to a specific area.

If all of that fails, you could always open a ticket here on github. Alternatively, you could always ask on any of the ZX Spectrum facebook groups to see if someone knows what the problem would appear to be. 

# 3> Software
## 3.1> How do I put something on my cartridge?
This depends somewhat on which type of cartridge you mean, but for the resmainder of this answer I'll assume you mean either the ZX Cartridge 2.021 or the ZX Diagnostic 2.021. In the case of the [ZX Cartridge 1.983](https://github.com/tebl/ZX-Interface-2.021/tree/main/ZX%20Cartridge%201983), I recommend that you take a look at [combining ROM files](https://github.com/tebl/ZX-Interface-2.021/blob/main/documentation/flash_eeprom.md#11-combining-roms) directly as it does not support [bank switching](https://github.com/tebl/ZX-Interface-2.021/blob/main/documentation/bank_switching.md) like the other two.

For the other two, I've put together a piece of software that I've creatively called the [Cartridge Creator](https://github.com/tebl/ZX-Interface-2.021/tree/main/software/cartridge_creator) in order to prepare a *.bin* or *.hex* suitable for [flashing onto an (E)EPROM using](https://github.com/tebl/ZX-Interface-2.021/blob/main/documentation/flash_eeprom.md) an (E)EPROM Programmer. Check out [Cartridge Creator](https://github.com/tebl/ZX-Interface-2.021/tree/main/software/cartridge_creator) for all of the details, but in shorter terms you find the ROM-files you want to put onto the same cartridge or you can put a single .sna (*snapshot*) file on one of them - the tool will take care of preparing the image for you.

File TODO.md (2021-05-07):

# TODO
- Add M1 override for computers with non-functional M1 (for use with diagnostic cartridge)

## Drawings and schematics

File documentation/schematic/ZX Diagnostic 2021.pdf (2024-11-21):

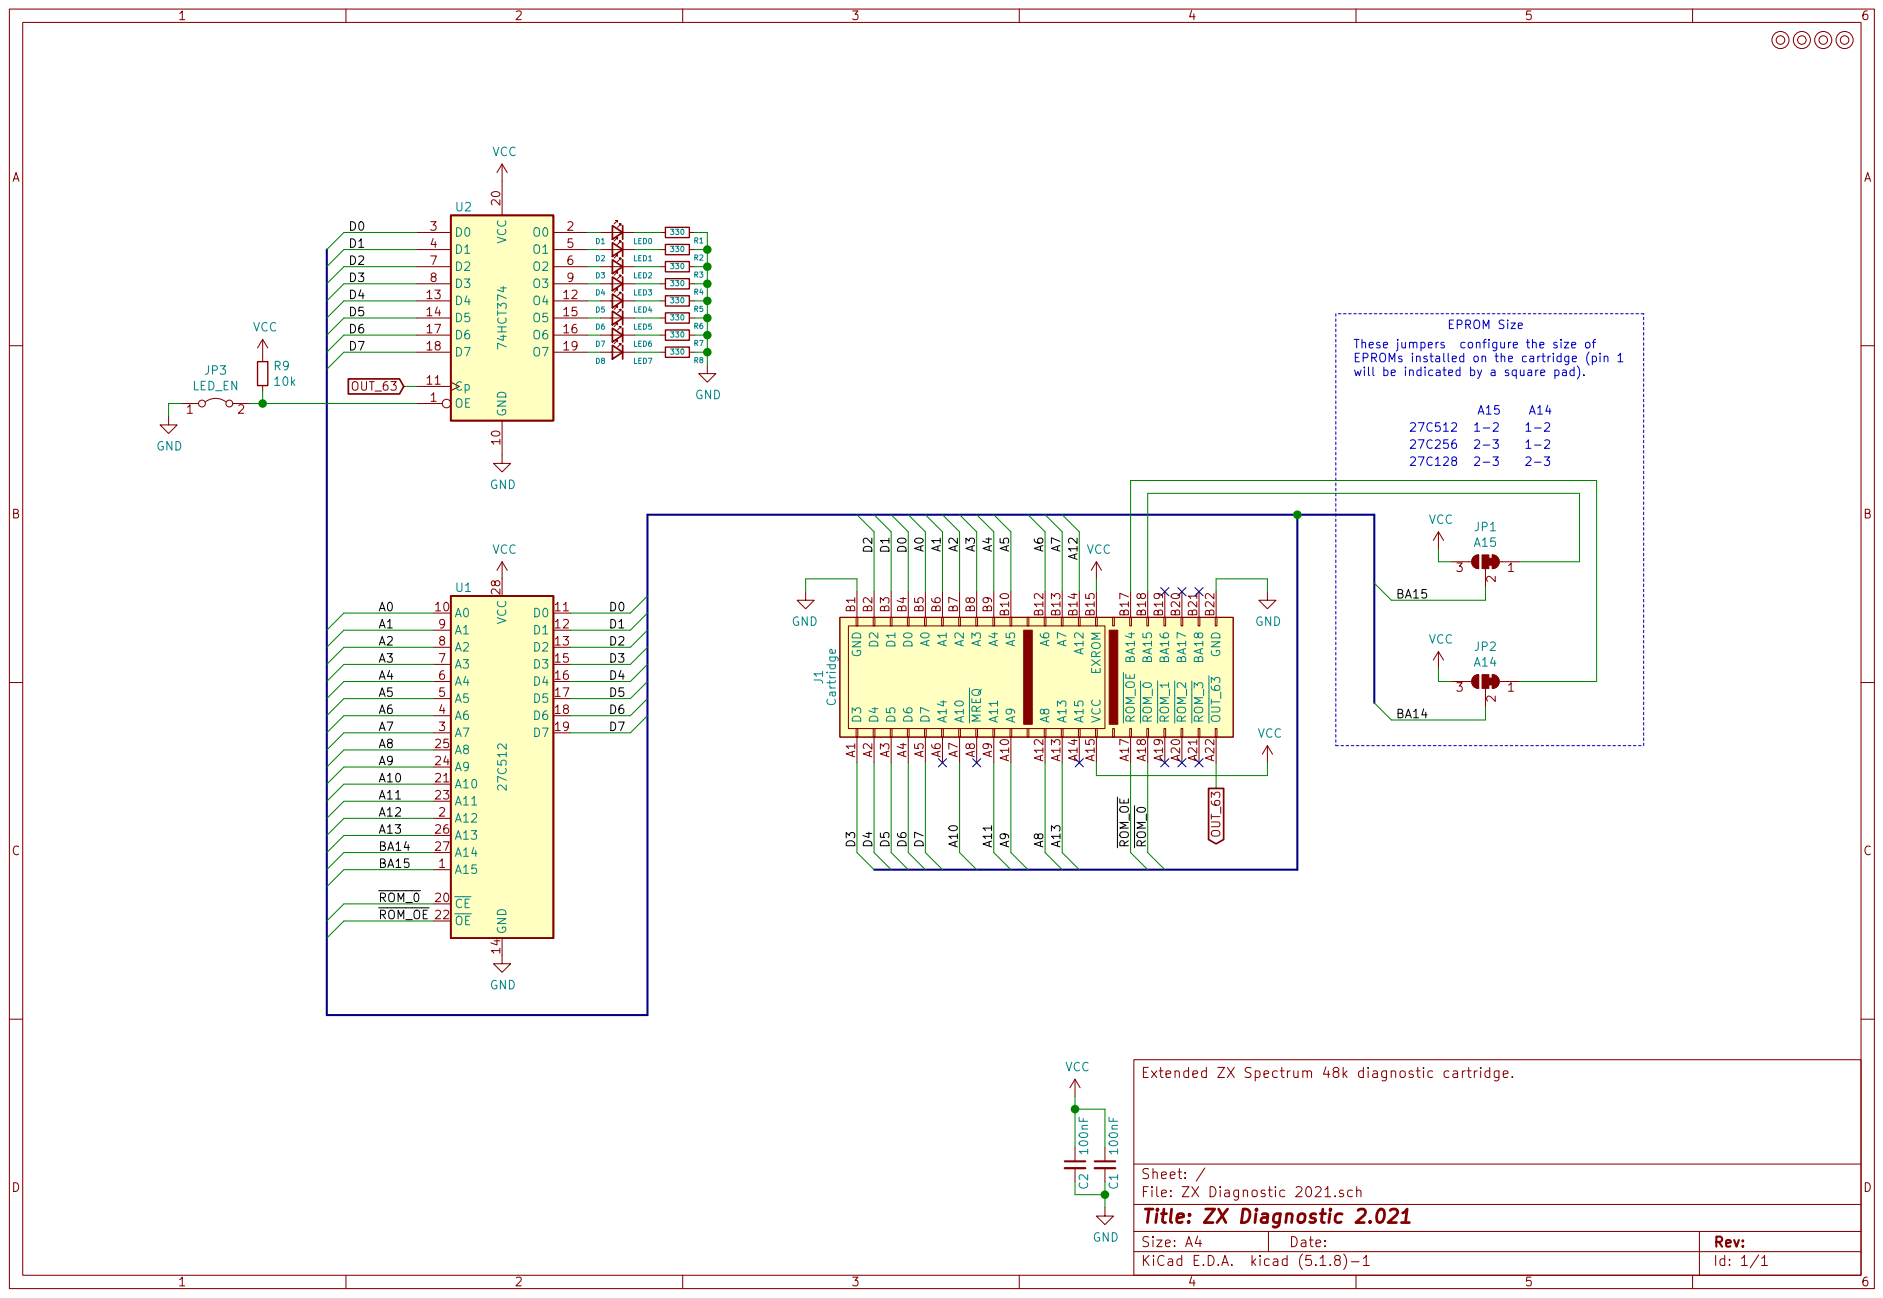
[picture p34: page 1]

will be indicated by a square pad). EPROM Size
EPROMs installed on the cartridge (pin 1

File: ZX Diagnostic 2021.sch Sheet: / Extended ZX Spectrum 48k diagnostic cartridge. C1 100nF VCC

Id: 1/1 Title: ZX Diagnostic 2.021

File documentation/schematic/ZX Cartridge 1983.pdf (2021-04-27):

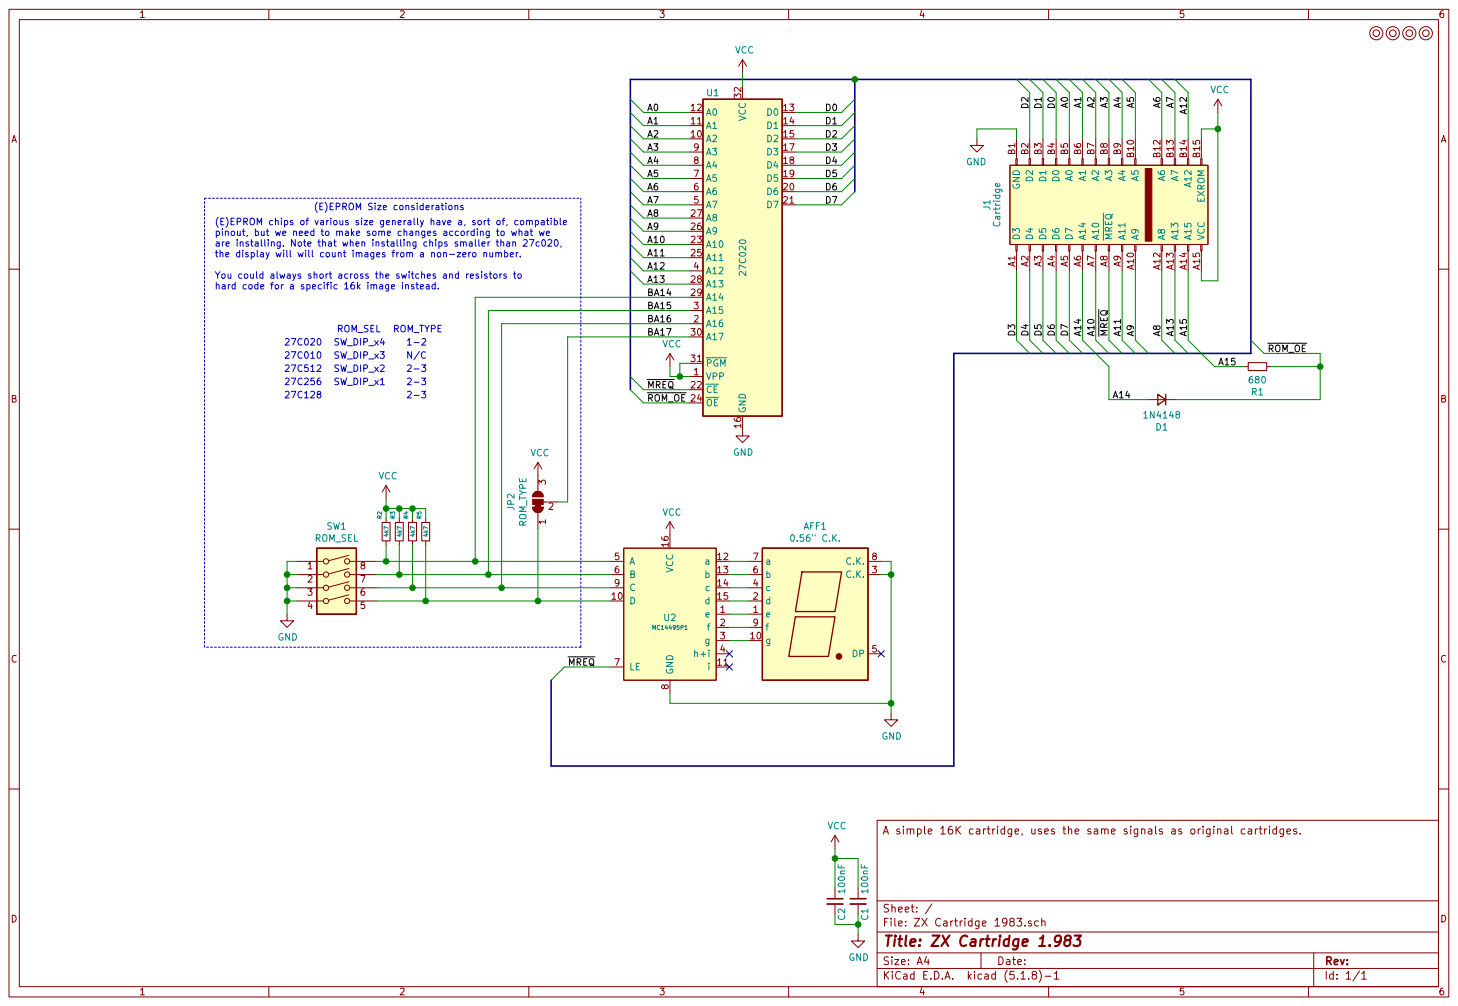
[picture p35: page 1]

(E)EPROM chips of various size generally have a, sort of, compatible
pinout, but we need to make some changes according to what we
are installing. Note that when installing chips smaller than 27c020,
the display will will count images from a non-zero number.

You could always short across the switches and resistors to
hard code for a specific 16k image instead. SW_DIP_x1 SW_DIP_x2

File: ZX Cartridge 1983.sch Sheet: / A simple 16K cartridge, uses the same signals as original cartridges.

Id: 1/1 Title: ZX Cartridge 1.983

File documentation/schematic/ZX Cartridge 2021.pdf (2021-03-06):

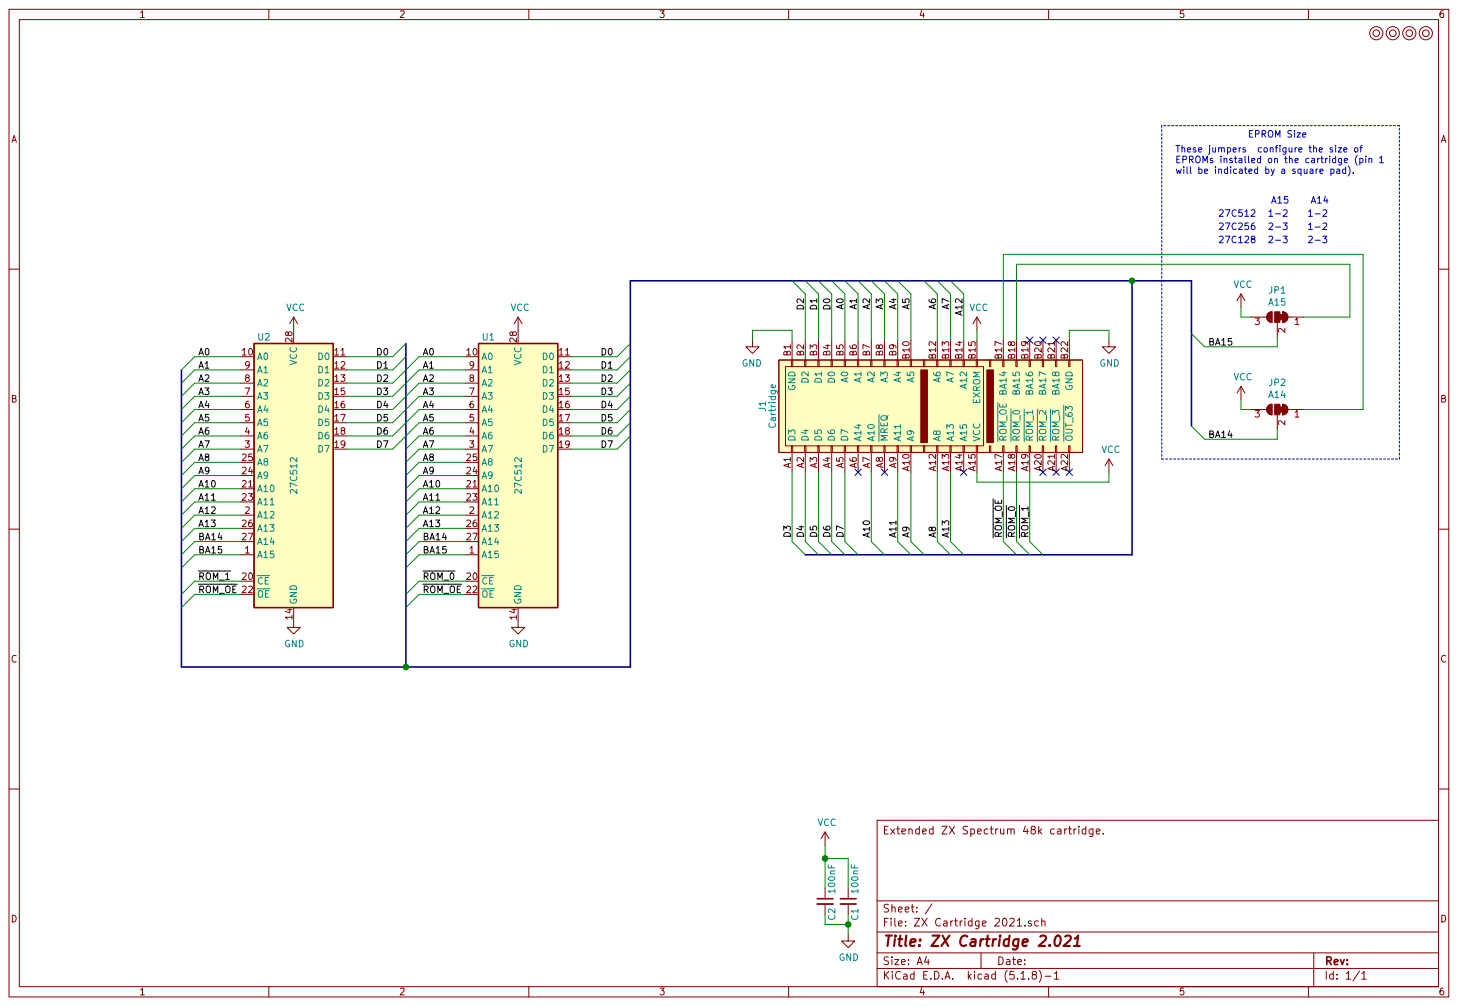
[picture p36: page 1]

will be indicated by a square pad). EPROM Size
EPROMs installed on the cartridge (pin 1

File: ZX Cartridge 2021.sch Sheet: / Extended ZX Spectrum 48k cartridge. GND

Id: 1/1 Title: ZX Cartridge 2.021

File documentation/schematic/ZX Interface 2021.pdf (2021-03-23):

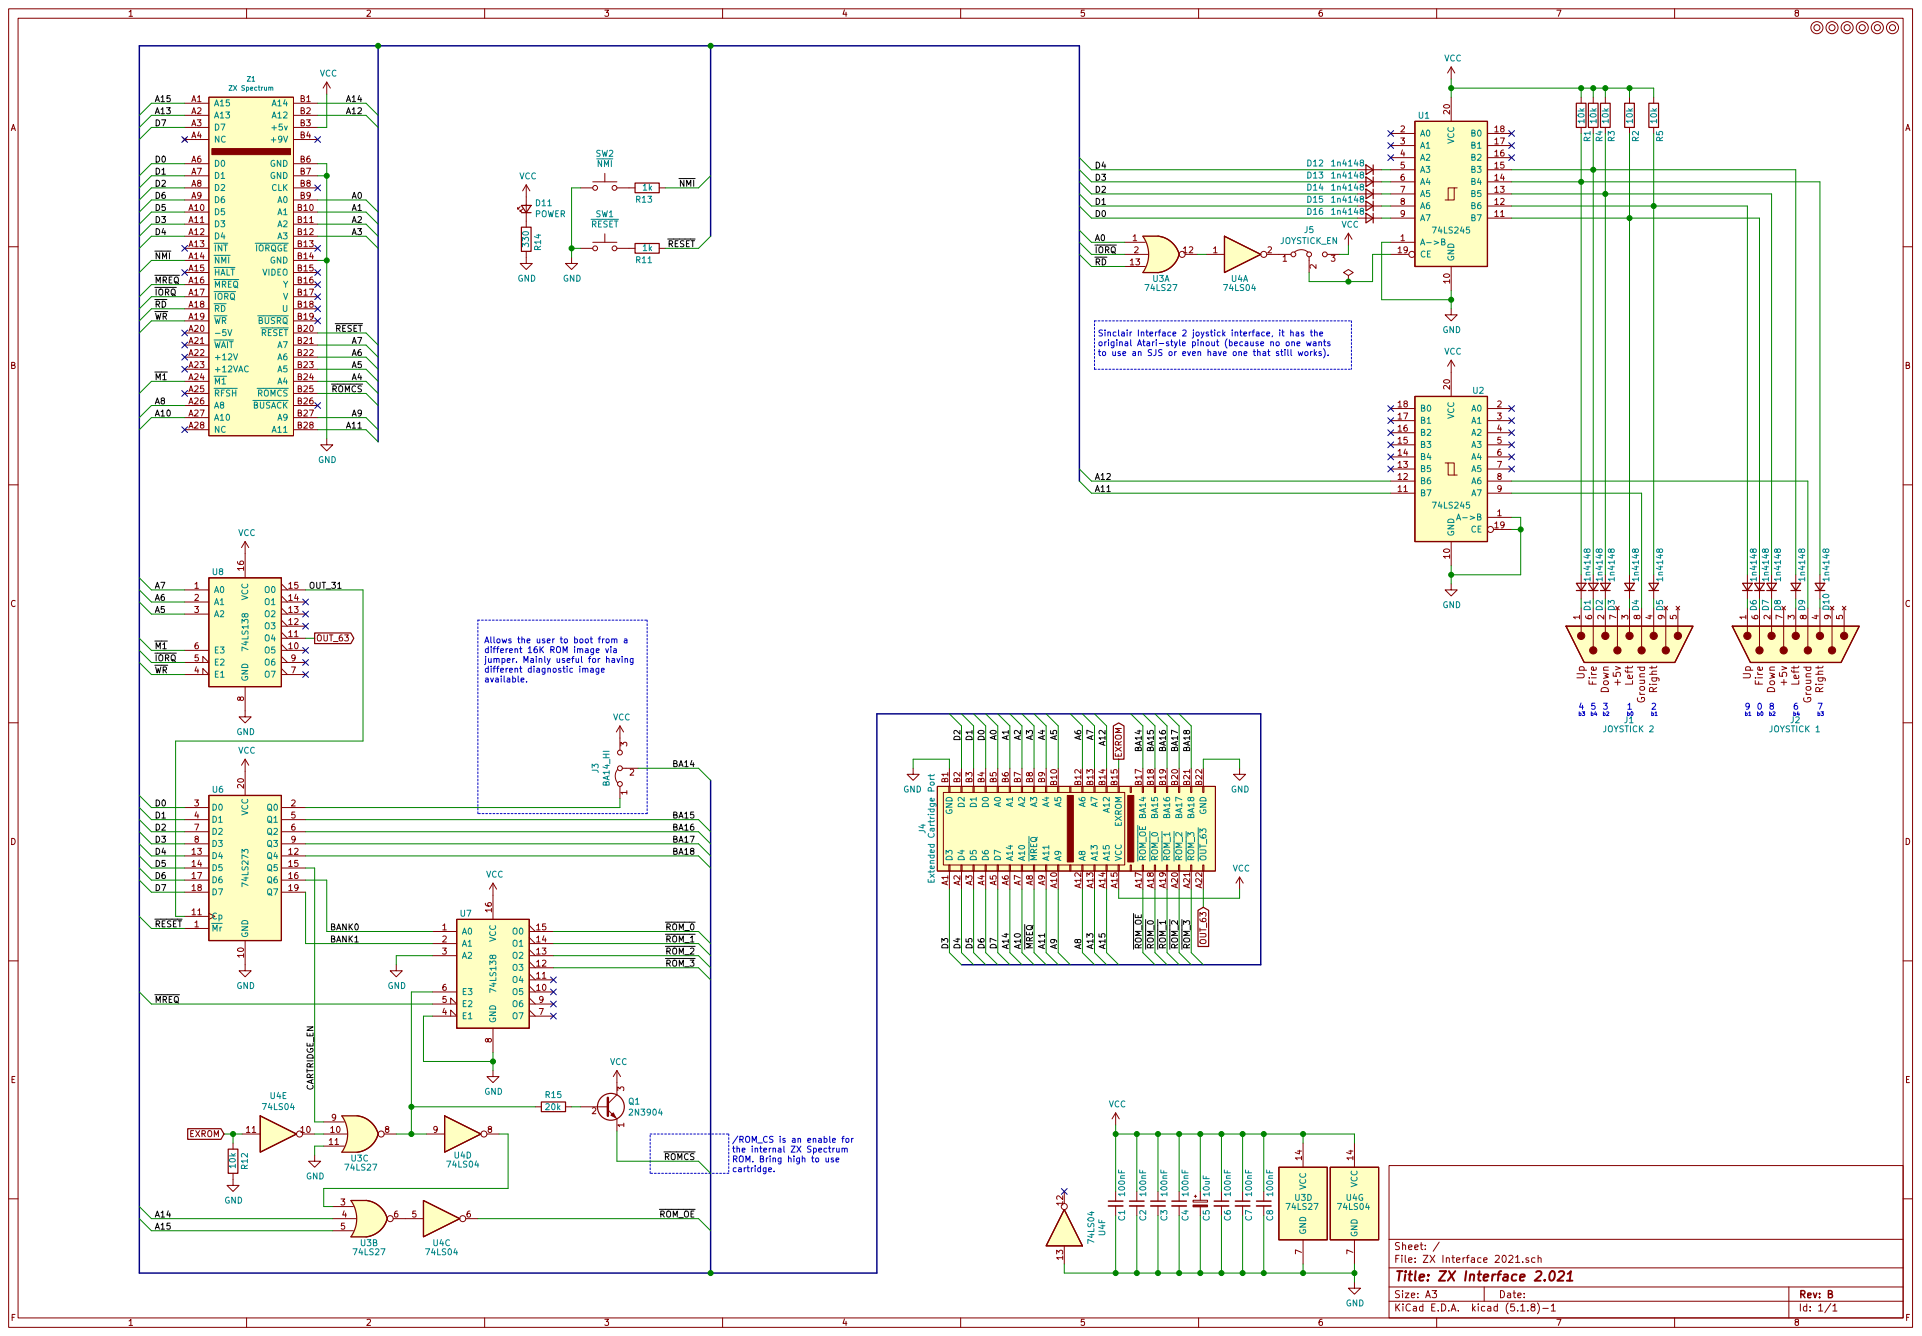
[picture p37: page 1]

Sinclair Interface 2 joystick interface, it has the
original Atari-style pinout (because no one wants
to use an SJS or even have one that still works).

different 16K ROM image via
jumper. Mainly useful for having
different diagnostic image

/ROM_CS is an enable for
the internal ZX Spectrum
ROM. Bring high to use
cartridge.

Id: 1/1 Title: ZX Interface 2.021

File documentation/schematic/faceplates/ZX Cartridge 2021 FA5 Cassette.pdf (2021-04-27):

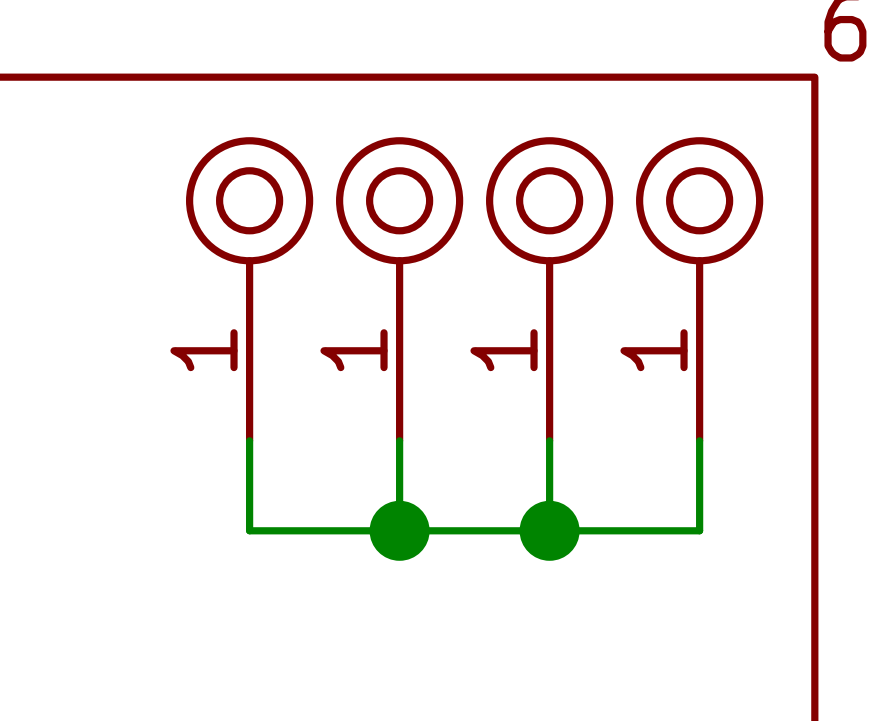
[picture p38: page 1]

It's just a faceplate, almost nothing to see here.

File: ZX Cartridge 2021 FA5 Cassette.sch Sheet: /
Id: 1/1 Title: ZX Cartridge 2.021 (Faceplate)

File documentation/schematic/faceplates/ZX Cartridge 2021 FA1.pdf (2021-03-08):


It's just a faceplate, almost nothing to see here.

File: ZX Cartridge 2021 FA1.sch Sheet: /
Id: 1/1 Title: ZX Cartridge 2.021 (Faceplate)

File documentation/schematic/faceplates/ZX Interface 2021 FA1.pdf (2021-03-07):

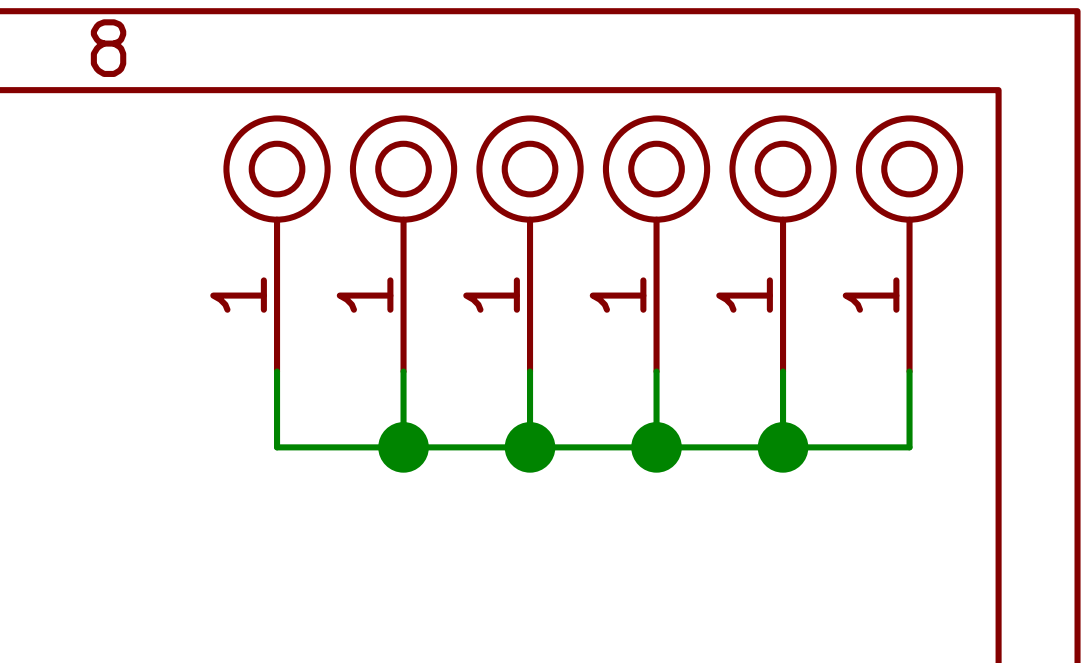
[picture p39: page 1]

It's just a faceplate, almost nothing to see here!

Id: 1/1 Title: ZX Interface 2.021 (Faceplate A1) File: ZX Interface 2021 FA1.sch Sheet: /

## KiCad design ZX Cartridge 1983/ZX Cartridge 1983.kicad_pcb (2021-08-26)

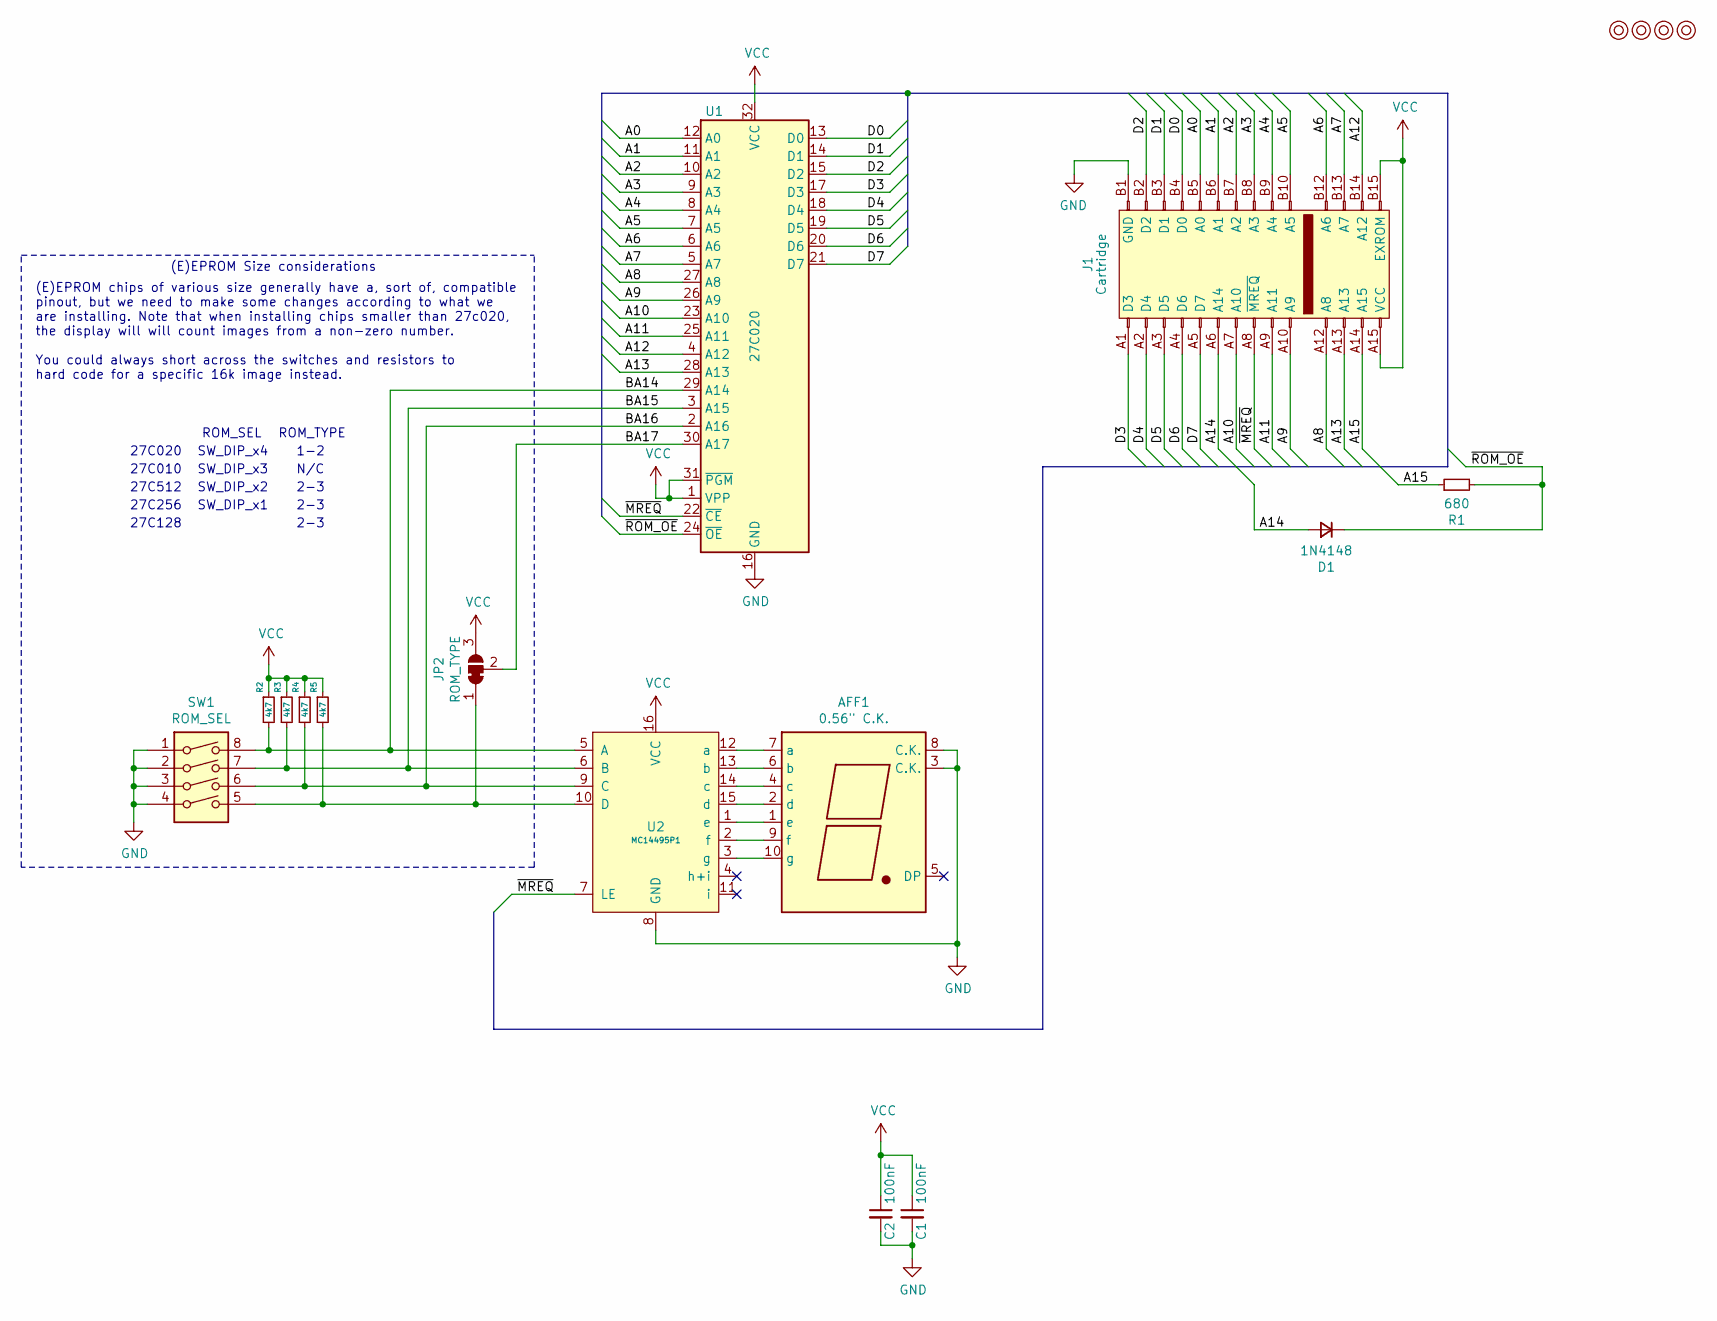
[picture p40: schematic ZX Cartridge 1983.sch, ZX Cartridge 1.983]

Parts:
AFF1: 0.56\" C.K.; 7SegmentLED_LTS6760_LTS6780
C1, C2: 100nF; C_Disc_D4.7mm_W2.5mm_P5.00mm
D1: 1N4148; D_DO-35_SOD27_P7.62mm_Horizontal
J1: Cartridge; ZX_Spectrum_Cartridge_Original
JP2: ROM_TYPE; select
M1, M2, M3, M4: Mounting; M3_pin
R1: 680; R_Axial_DIN0207_L6.3mm_D2.5mm_P10.16mm_Horizontal
R2, R3, R4, R5: 4k7; R_Axial_DIN0207_L6.3mm_D2.5mm_P7.62mm_Horizontal
SW1: ROM_SEL; SW_DIP_SPSTx04_Slide_9.78x12.34mm_W7.62mm_P2.54mm
U1: 27C020; DIP-32_W15.24mm_Socket_LongPads
U2: MC14495P1; DIP-16_W7.62mm_Socket_LongPads

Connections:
/A0: J1.B5 (A0), U1.12 (A0)
/A1: J1.B6 (A1), U1.11 (A1)
/A2: J1.B7 (A2), U1.10 (A2)
/A3: J1.B8 (A3), U1.9 (A3)
/A4: J1.B9 (A4), U1.8 (A4)
/A5: J1.B10 (A5), U1.7 (A5)
/A6: J1.B12 (A6), U1.6 (A6)
/A7: J1.B13 (A7), U1.5 (A7)
/A8: J1.A12 (A8), U1.27 (A8)
/A9: J1.A10 (A9), U1.26 (A9)
/A10: J1.A7 (A10), U1.23 (A10)
/A11: J1.A9 (A11), U1.25 (A11)
/A12: J1.B14 (A12), U1.4 (A12)
/A13: J1.A13, U1.28 (A13)
/A14: D1.2 (A), J1.A6 (A14)
/A15: J1.A14 (A15), R1.1
/BA14: R2.2, SW1.8, U1.29 (A14), U2.5 (A)
/BA15: R3.2, SW1.7, U1.3 (A15), U2.6 (B)
/BA16: R4.2, SW1.6, U1.2 (A16), U2.9 (C)
/BA17: JP2.2 (C), U1.30 (A17)
/D0: J1.B4 (D0), U1.13 (D0)
/D1: J1.B3 (D1), U1.14 (D1)
/D2: J1.B2 (D2), U1.15 (D2)
/D3: J1.A1 (D3), U1.17 (D3)
/D4: J1.A2 (D4), U1.18 (D4)
/D5: J1.A3 (D5), U1.19 (D5)
/D6: J1.A4 (D6), U1.20 (D6)
/D7: J1.A5 (D7), U1.21 (D7)
/~MREQ: J1.A8 (~MREQ), U1.22 (~CE), U2.7 (LE)
/~ROM_OE: D1.1 (K), R1.2, U1.24 (~OE)
GND: AFF1.3 (C.K.), AFF1.8 (C.K.), C1.2, C2.2, J1.B1 (GND), SW1.1, SW1.2, SW1.3, SW1.4, U1.16 (GND), U2.8 (GND)
unnamed: AFF1.1 (e), U2.1 (e)
unnamed: AFF1.2 (d), U2.15 (d)
unnamed: AFF1.4 (c), U2.14 (c)
unnamed: AFF1.6 (b), U2.13 (b)
unnamed: AFF1.7 (a), U2.12 (a)
unnamed: AFF1.9 (f), U2.2 (f)
unnamed: AFF1.10 (g), U2.3 (g)
unnamed: JP2.1 (A), R5.2, SW1.5, U2.10 (D)
VCC: C1.1, C2.1, J1.A15 (VCC), J1.B15 (EXROM), JP2.3 (B), R2.1, R3.1, R4.1, R5.1, U1.1 (VPP), U1.31 (~PGM), U1.32 (VCC), U2.16 (VCC)

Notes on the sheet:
27C512
27C256
27C128
2-3
(E)EPROM Size considerations
(E)EPROM chips of various size generally have a, sort of, compatible pinout, but we need to make some changes according to what we are installing. Note that when installing chips smaller than 27c020, the display will will count images from a non-zero number. You could always short across the switch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
27C010
SW_DIP_x3
SW_DIP_x2
SW_DIP_x1
27C020
ROM_SEL
SW_DIP_x4
ROM_TYPE
1-2
N/C

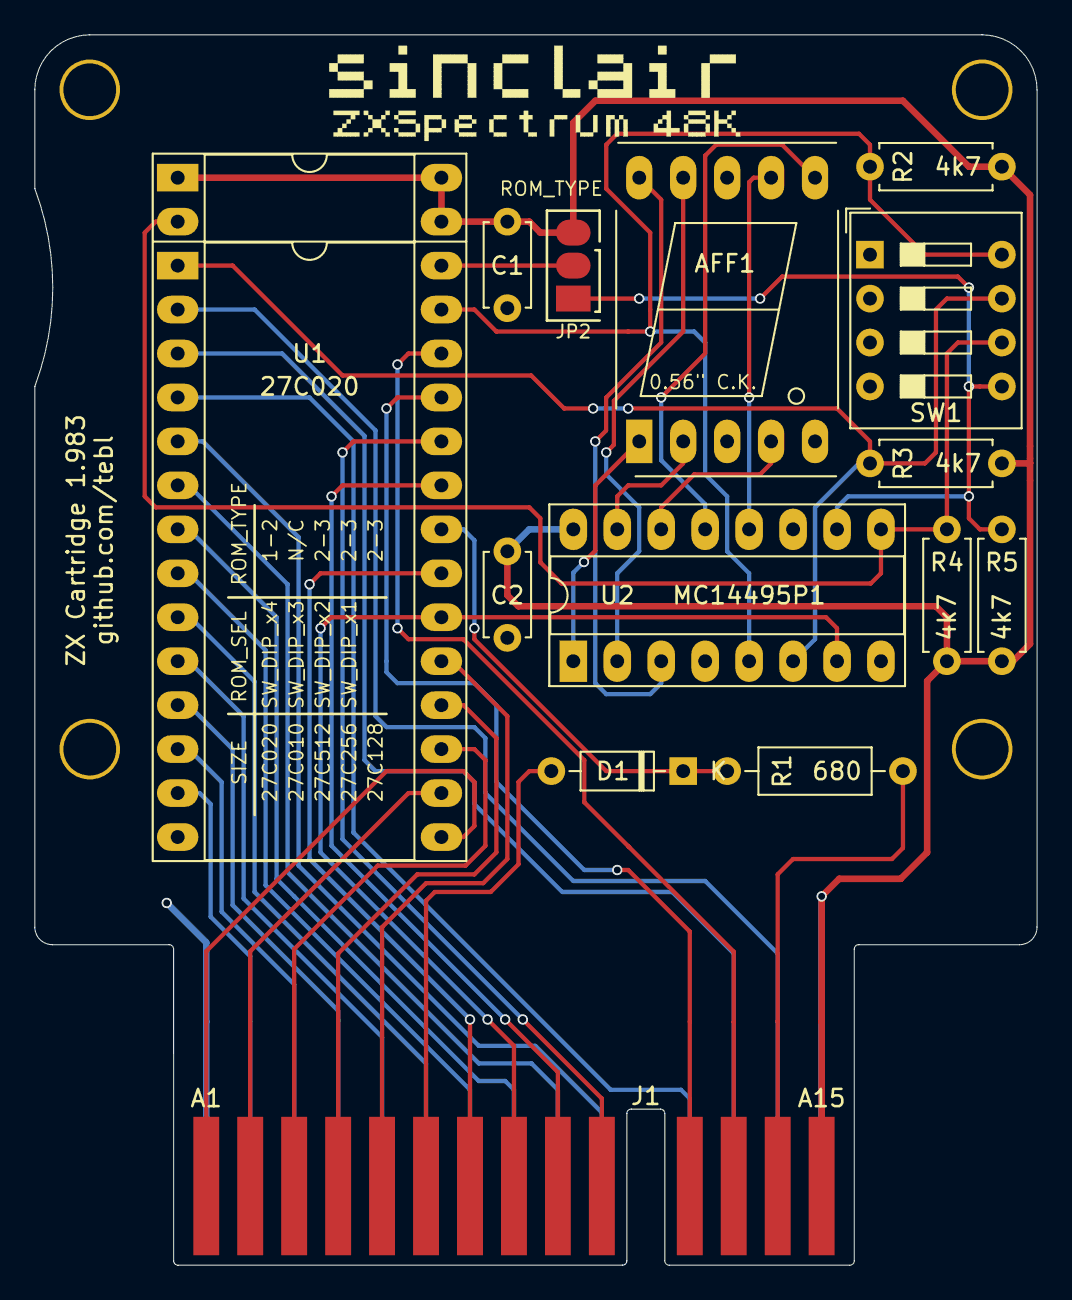
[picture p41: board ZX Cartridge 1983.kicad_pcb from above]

Board: 2 copper layers, 57.9 x 71.1 mm, 19 parts (0 on the bottom side), 40 nets.

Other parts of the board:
sinclair_title: sinclair_title

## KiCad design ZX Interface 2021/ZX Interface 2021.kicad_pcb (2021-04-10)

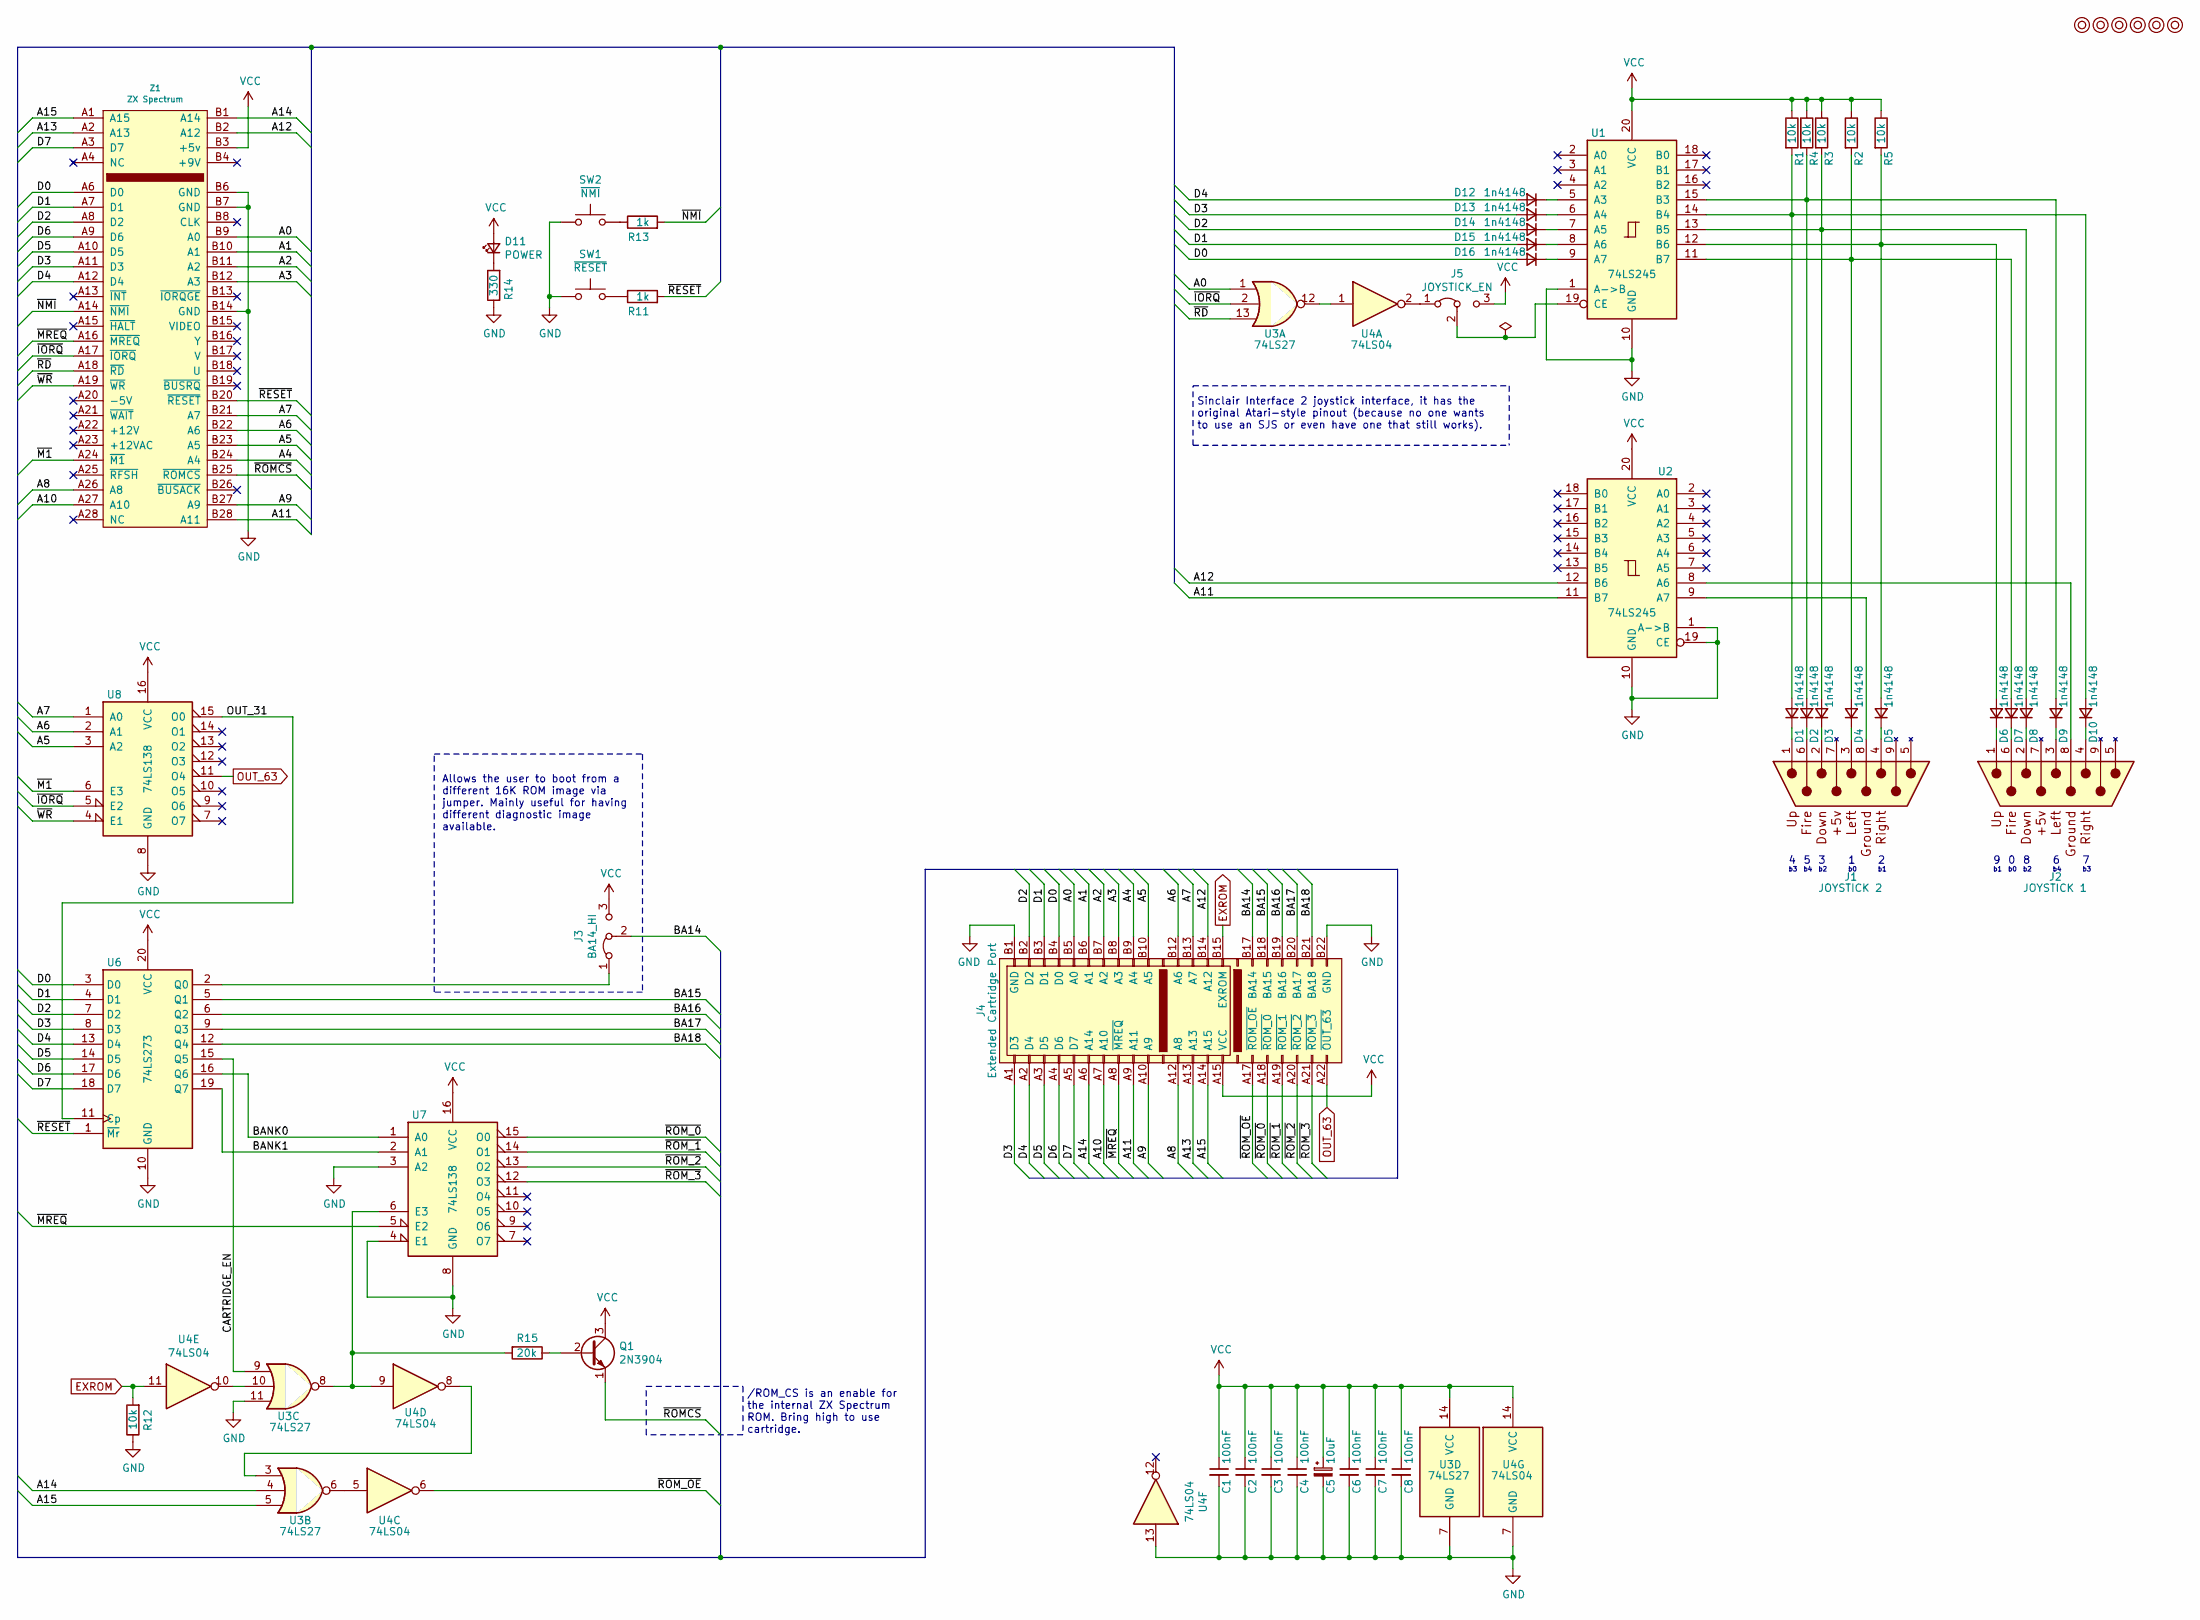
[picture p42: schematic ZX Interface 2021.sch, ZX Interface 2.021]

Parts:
C1, C2, C3, C4, C6, C7, C8: 100nF; C_Disc_D4.7mm_W2.5mm_P5.00mm
C5: 10uF; C_Radial_D4.0mm_H7.0mm_P1.50mm
D1, D2, D3, D4, D5, D6, D7, D8, D9, D10, D12, D13, D14, D15, D16: 1n4148; D_DO-35_SOD27_P7.62mm_Horizontal
D11: POWER; LED_D5.0mm
J1: JOYSTICK 2; DSUB-9_Male_Vertical_Pitch2.77x2.84mm
J2: JOYSTICK 1; DSUB-9_Male_Vertical_Pitch2.77x2.84mm
J3: BA14_HI; PinHeader_1x03_P2.54mm_Horizontal
J4: Extended Cartridge Port; ZX_Spectrum_Cartridge_Port
J5: JOYSTICK_EN; PinHeader_1x03_P2.54mm_Vertical
M1, M2, M3, M4, M5, M6: Mounting; M3_pin
Q1: 2N3904; TO-92_Inline_Wide
R1, R2, R3, R4, R5, R12: 10k; R_Axial_DIN0207_L6.3mm_D2.5mm_P10.16mm_Horizontal
R11, R13: 1k; R_Axial_DIN0207_L6.3mm_D2.5mm_P10.16mm_Horizontal
R14: 330; R_Axial_DIN0207_L6.3mm_D2.5mm_P10.16mm_Horizontal
R15: 20k; R_Axial_DIN0207_L6.3mm_D2.5mm_P10.16mm_Horizontal
SW1: ~RESET; SW_PUSH_6mm
SW2: ~NMI; SW_PUSH_6mm
U1, U2: 74LS245; DIP-20_W7.62mm_Socket_LongPads
U3: 74LS27; DIP-14_W7.62mm_Socket_LongPads
U4: 74LS04; DIP-14_W7.62mm_Socket_LongPads
U6: 74LS273; DIP-20_W7.62mm_Socket_LongPads
U7, U8: 74LS138; DIP-16_W7.62mm_Socket_LongPads
Z1: ZX Spectrum; ZX_Spectrum_Expansion_Edge

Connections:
/A0: J4.B5 (A0), U3.1, Z1.B9 (A0)
/A1: J4.B6 (A1), Z1.B10 (A1)
/A2: J4.B7 (A2), Z1.B11 (A2)
/A3: J4.B8 (A3), Z1.B12 (A3)
/A4: J4.B9 (A4), Z1.B24 (A4)
/A5: J4.B10 (A5), U8.3 (A2), Z1.B23 (A5)
/A6: J4.B12 (A6), U8.2 (A1), Z1.B22 (A6)
/A7: J4.B13 (A7), U8.1 (A0), Z1.B21 (A7)
/A8: J4.A12 (A8), Z1.A26 (A8)
/A9: J4.A10 (A9), Z1.B27 (A9)
/A10: J4.A7 (A10), Z1.A27 (A10)
/A11: J4.A9 (A11), U2.11 (B7), Z1.B28 (A11)
/A12: J4.B14 (A12), U2.12 (B6), Z1.B2 (A12)
/A13: J4.A13, Z1.A2 (A13)
/A14: J4.A6 (A14), U3.4, Z1.B1 (A14)
/A15: J4.A14 (A15), U3.5, Z1.A1 (A15)
/BA14: J3.2 (C), J4.B17 (BA14)
/BA15: J4.B18 (BA15), U6.5 (Q1)
/BA16: J4.B19 (BA16), U6.6 (Q2)
/BA17: J4.B20 (BA17), U6.9 (Q3)
/BA18: J4.B21 (BA18), U6.12 (Q4)
/BANK0: U6.16 (Q6), U7.1 (A0)
/BANK1: U6.19 (Q7), U7.2 (A1)
/CARTRIDGE_EN: U3.9, U6.15 (Q5)
/D0: D16.2 (A), J4.B4 (D0), U6.3 (D0), Z1.A6 (D0)
/D1: D15.2 (A), J4.B3 (D1), U6.4 (D1), Z1.A7 (D1)
/D2: D14.2 (A), J4.B2 (D2), U6.7 (D2), Z1.A8 (D2)
/D3: D13.2 (A), J4.A1 (D3), U6.8 (D3), Z1.A11 (D3)
/D4: D12.2 (A), J4.A2 (D4), U6.13 (D4), Z1.A12 (D4)
/D5: J4.A3 (D5), U6.14 (D5), Z1.A10 (D5)
/D6: J4.A4 (D6), U6.17 (D6), Z1.A9 (D6)
/D7: J4.A5 (D7), U6.18 (D7), Z1.A3 (D7)
/OUT_31: U6.11 (Cp), U8.15 (O0)
/~IORQ: U3.2, U8.5 (E2), Z1.A17 (~IORQ)
/~M1: U8.6 (E3), Z1.A24 (~M1)
/~MREQ: J4.A8 (~MREQ), U7.5 (E2), Z1.A16 (~MREQ)
/~NMI: R13.2, Z1.A14 (~NMI)
/~RD: U3.13, Z1.A18 (~RD)
/~RESET: R11.2, U6.1 (~Mr), Z1.B20 (~RESET)
/~ROMCS: Q1.1 (E), Z1.B25 (~ROMCS)
/~ROM_0: J4.A18 (~ROM_0), U7.15 (O0)
/~ROM_1: J4.A19 (~ROM_1), U7.14 (O1)
/~ROM_2: J4.A20 (~ROM_2), U7.13 (O2)
/~ROM_3: J4.A21 (~ROM_3), U7.12 (O3)
/~ROM_OE: J4.A17 (~ROM_OE), U4.6
/~WR: U8.4 (E1), Z1.A19 (~WR)
EXROM: J4.B15 (EXROM), R12.2, U4.11
GND: C1.2, C2.2, C3.2, C4.2, C5.2, C6.2, C7.2, C8.2, J4.B1 (GND), J4.B22 (GND), R12.1, R14.1, SW1.1, SW2.1, U1.1 (A->B), U1.10 (GND), U2.1 (A->B), U2.10 (GND), U2.19 (CE), U3.7 (GND), U3.11, U4.7 (GND), U4.13, U6.10 (GND), U7.3 (A2), U7.4 (E1), U7.8 (GND), U8.8 (GND), Z1.B6 (GND), Z1.B7 (GND), Z1.B14 (GND)
unnamed: D1.1 (K), J1.1
unnamed: D1.2 (A), D10.2 (A), R1.2, U1.14 (B4)
unnamed: D2.1 (K), J1.6
unnamed: D2.2 (A), D9.2 (A), R4.2, U1.15 (B3)
unnamed: D3.1 (K), J1.2
unnamed: D3.2 (A), D8.2 (A), R3.2, U1.13 (B5)
unnamed: D4.1 (K), J1.3
unnamed: D4.2 (A), D7.2 (A), R2.2, U1.11 (B7)
unnamed: D5.1 (K), J1.4
unnamed: D5.2 (A), D6.2 (A), R5.2, U1.12 (B6)
unnamed: D6.1 (K), J2.1
unnamed: D7.1 (K), J2.6
unnamed: D8.1 (K), J2.2
unnamed: D9.1 (K), J2.3
unnamed: D10.1 (K), J2.4
unnamed: D11.1 (K), R14.2
unnamed: D12.1 (K), U1.5 (A3)
unnamed: D13.1 (K), U1.6 (A4)
unnamed: D14.1 (K), U1.7 (A5)
unnamed: D15.1 (K), U1.8 (A6)
unnamed: D16.1 (K), U1.9 (A7)
unnamed: J1.8 (GND), U2.9 (A7)
unnamed: J2.8 (GND), U2.8 (A6)
unnamed: J3.1 (A), U6.2 (Q0)
unnamed: J5.1 (A), U4.2
unnamed: J5.2 (C), U1.19 (CE)
unnamed: Q1.2 (B), R15.1
unnamed: R11.1, SW1.2
unnamed: R13.1, SW2.2
unnamed: R15.2, U3.8, U4.9, U7.6 (E3)
unnamed: U3.3, U4.8
unnamed: U3.6, U4.5
unnamed: U3.10, U4.10
unnamed: U3.12, U4.1
OUT_63: J4.A22 (~OUT_63), U8.11 (O4)
VCC: C1.1, C2.1, C3.1, C4.1, C5.1, C6.1, C7.1, C8.1, D11.2 (A), J3.3 (B), J4.A15 (VCC), J5.3 (B), Q1.3 (C), R1.1, R2.1, R3.1, R4.1, R5.1, U1.20 (VCC), U2.20 (VCC), U3.14 (VCC), U4.14 (VCC), U6.20 (VCC), U7.16 (VCC), U8.16 (VCC), Z1.B3 (+5v)

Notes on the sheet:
/ROM_CS is an enable for the internal ZX Spectrum ROM. Bring high to use cartridge.
Sinclair Interface 2 joystick interface, it has the original Atari-style pinout (because no one wants to use an SJS or even have one that still works).
Allows the user to boot from a different 16K ROM image via jumper. Mainly useful for having different diagnostic image available.

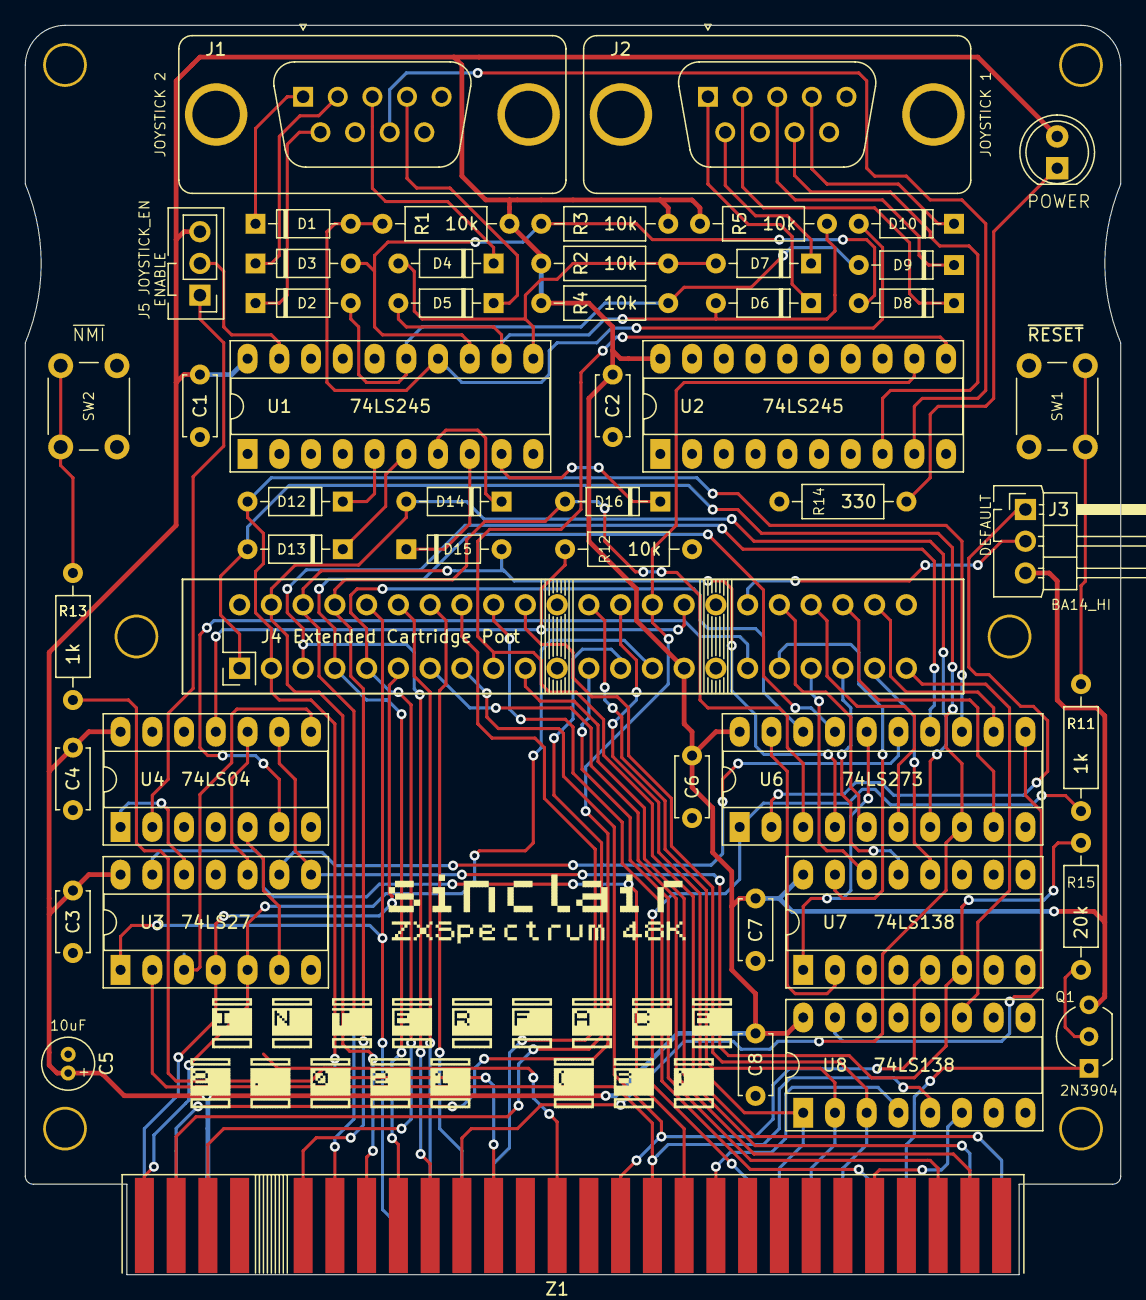
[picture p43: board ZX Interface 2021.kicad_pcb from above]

Board: 2 copper layers, 87.6 x 99.9 mm, 58 parts (0 on the bottom side), 84 nets.

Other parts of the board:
sinclair_title: Val**; interface_2021
sinclair_title#2: sinclair_title

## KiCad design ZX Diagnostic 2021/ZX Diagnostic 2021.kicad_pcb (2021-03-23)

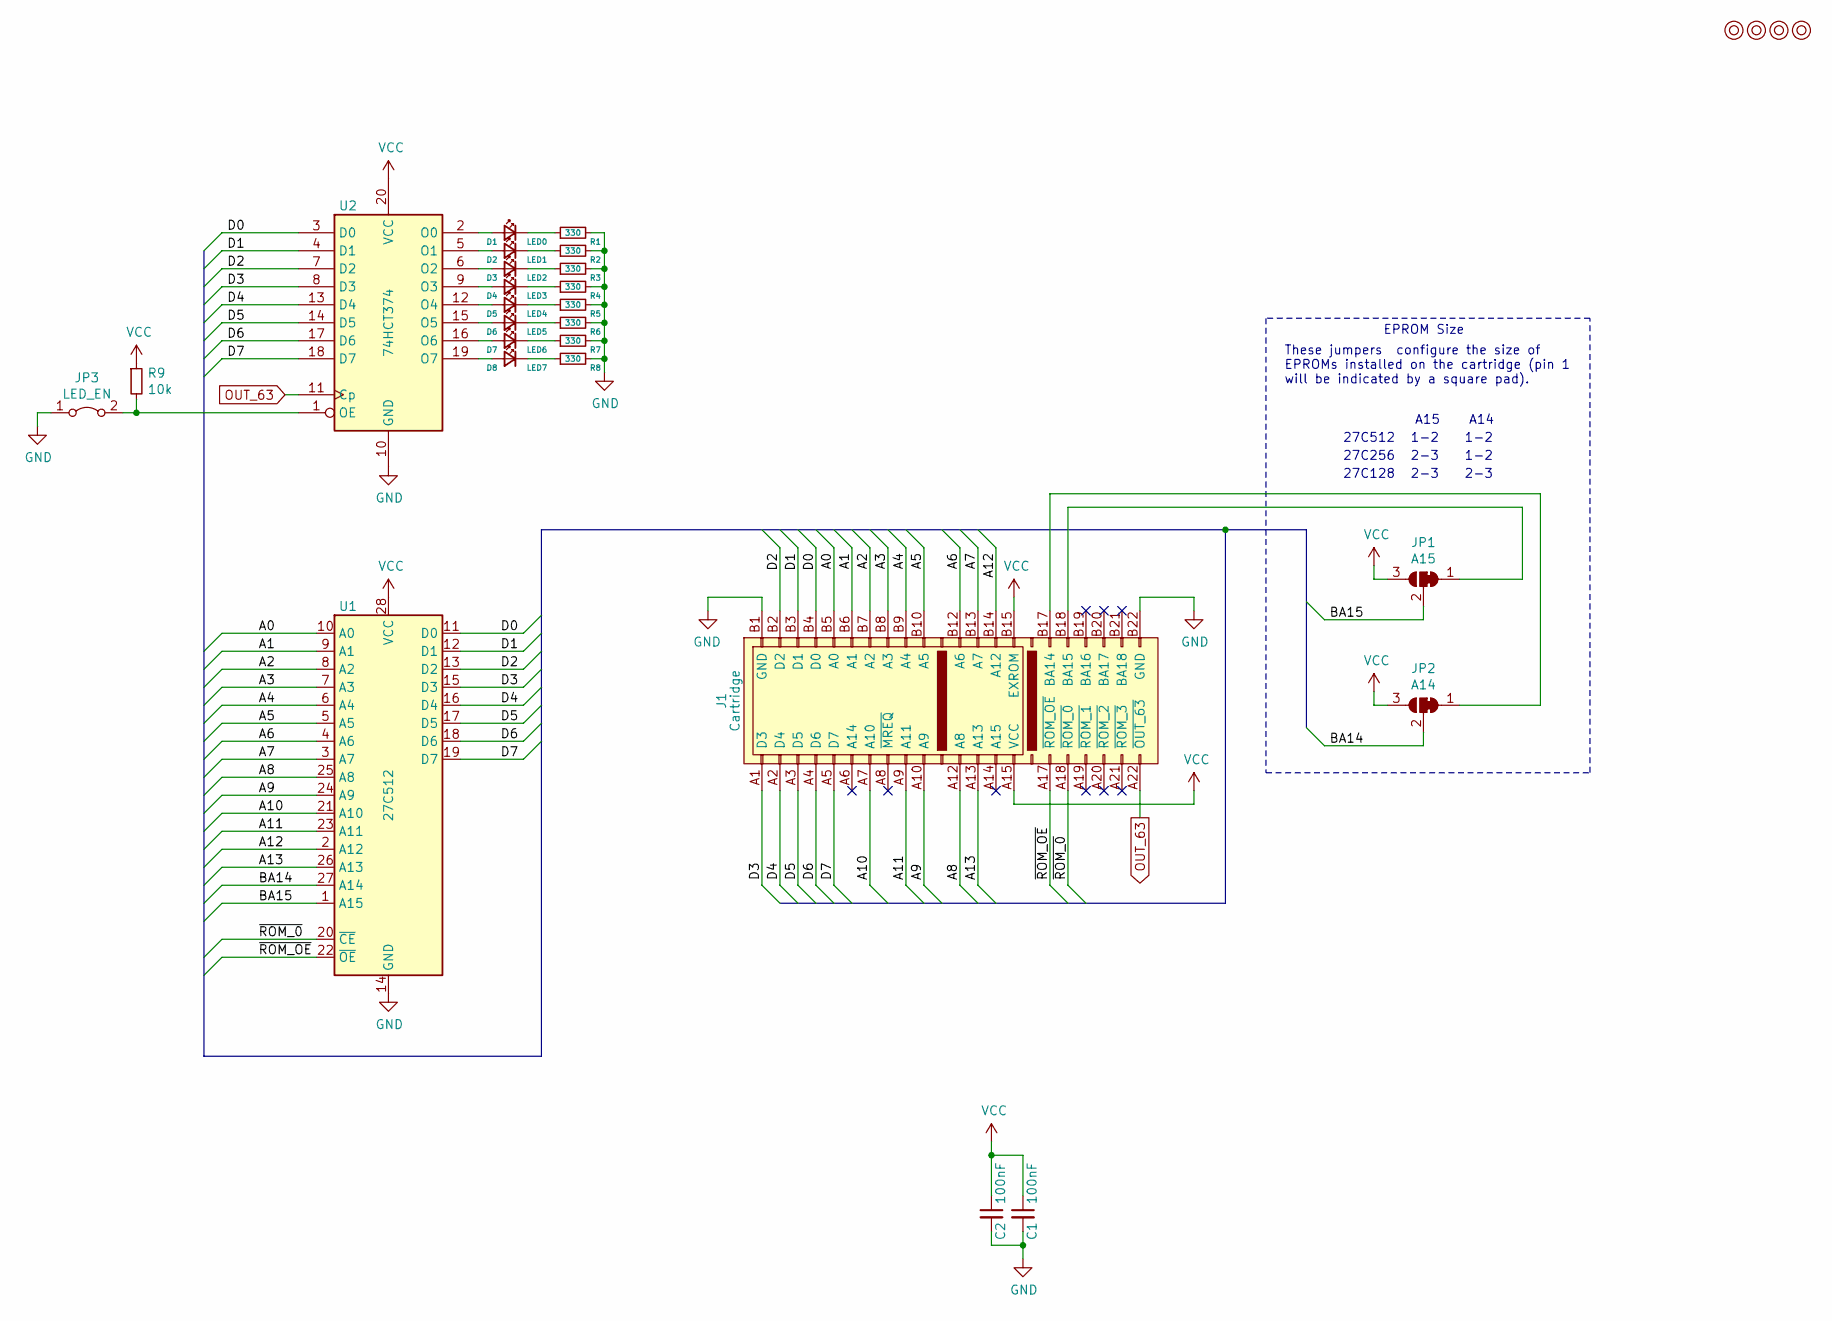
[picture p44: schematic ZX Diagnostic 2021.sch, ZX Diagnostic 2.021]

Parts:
C1, C2: 100nF; C_Disc_D4.7mm_W2.5mm_P5.00mm
D1: LED0; LED_D5.0mm
D2: LED1; LED_D5.0mm
D3: LED2; LED_D5.0mm
D4: LED3; LED_D5.0mm
D5: LED4; LED_D5.0mm
D6: LED5; LED_D5.0mm
D7: LED6; LED_D5.0mm
D8: LED7; LED_D5.0mm
J1: Cartridge; ZX_Spectrum_Cartridge
JP1: A15; select
JP2: A14; select
JP3: LED_EN; PinHeader_1x02_P2.54mm_Horizontal
M1, M2, M3, M4: Mounting; M3_pin
R1, R2, R3, R4, R5, R6, R7, R8: 330; R_Axial_DIN0207_L6.3mm_D2.5mm_P10.16mm_Horizontal
R9: 10k; R_Axial_DIN0207_L6.3mm_D2.5mm_P10.16mm_Horizontal
U1: 27C512; DIP-28_W15.24mm_Socket_LongPads
U2: 74HCT374; DIP-20_W7.62mm_Socket_LongPads

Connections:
/A0: J1.B5 (A0), U1.10 (A0)
/A1: J1.B6 (A1), U1.9 (A1)
/A2: J1.B7 (A2), U1.8 (A2)
/A3: J1.B8 (A3), U1.7 (A3)
/A4: J1.B9 (A4), U1.6 (A4)
/A5: J1.B10 (A5), U1.5 (A5)
/A6: J1.B12 (A6), U1.4 (A6)
/A7: J1.B13 (A7), U1.3 (A7)
/A8: J1.A12 (A8), U1.25 (A8)
/A9: J1.A10 (A9), U1.24 (A9)
/A10: J1.A7 (A10), U1.21 (A10)
/A11: J1.A9 (A11), U1.23 (A11)
/A12: J1.B14 (A12), U1.2 (A12)
/A13: J1.A13, U1.26 (A13)
/BA14: JP2.2 (C), U1.27 (A14)
/BA15: JP1.2 (C), U1.1 (A15)
/D0: J1.B4 (D0), U1.11 (D0), U2.3 (D0)
/D1: J1.B3 (D1), U1.12 (D1), U2.4 (D1)
/D2: J1.B2 (D2), U1.13 (D2), U2.7 (D2)
/D3: J1.A1 (D3), U1.15 (D3), U2.8 (D3)
/D4: J1.A2 (D4), U1.16 (D4), U2.13 (D4)
/D5: J1.A3 (D5), U1.17 (D5), U2.14 (D5)
/D6: J1.A4 (D6), U1.18 (D6), U2.17 (D6)
/D7: J1.A5 (D7), U1.19 (D7), U2.18 (D7)
/~ROM_0: J1.A18 (~ROM_0), U1.20 (~CE)
/~ROM_OE: J1.A17 (~ROM_OE), U1.22 (~OE)
GND: C1.2, C2.2, J1.B1 (GND), J1.B22 (GND), JP3.1 (A), R1.2, R2.2, R3.2, R4.2, R5.2, R6.2, R7.2, R8.2, U1.14 (GND), U2.10 (GND)
unnamed: D1.1 (K), R1.1
unnamed: D1.2 (A), U2.2 (O0)
unnamed: D2.1 (K), R2.1
unnamed: D2.2 (A), U2.5 (O1)
unnamed: D3.1 (K), R3.1
unnamed: D3.2 (A), U2.6 (O2)
unnamed: D4.1 (K), R4.1
unnamed: D4.2 (A), U2.9 (O3)
unnamed: D5.1 (K), R5.1
unnamed: D5.2 (A), U2.12 (O4)
unnamed: D6.1 (K), R6.1
unnamed: D6.2 (A), U2.15 (O5)
unnamed: D7.1 (K), R7.1
unnamed: D7.2 (A), U2.16 (O6)
unnamed: D8.1 (K), R8.1
unnamed: D8.2 (A), U2.19 (O7)
unnamed: J1.B17 (BA14), JP2.1 (A)
unnamed: J1.B18 (BA15), JP1.1 (A)
unnamed: JP3.2 (B), R9.2, U2.1 (OE)
OUT_63: J1.A22 (~OUT_63), U2.11 (Cp)
VCC: C1.1, C2.1, J1.A15 (VCC), J1.B15 (EXROM), JP1.3 (B), JP2.3 (B), R9.1, U1.28 (VCC), U2.20 (VCC)

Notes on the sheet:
EPROM Size
These jumpers configure the size of EPROMs installed on the cartridge (pin 1 will be indicated by a square pad).
A15
A14
27C512
27C256
27C128
1-2
2-3

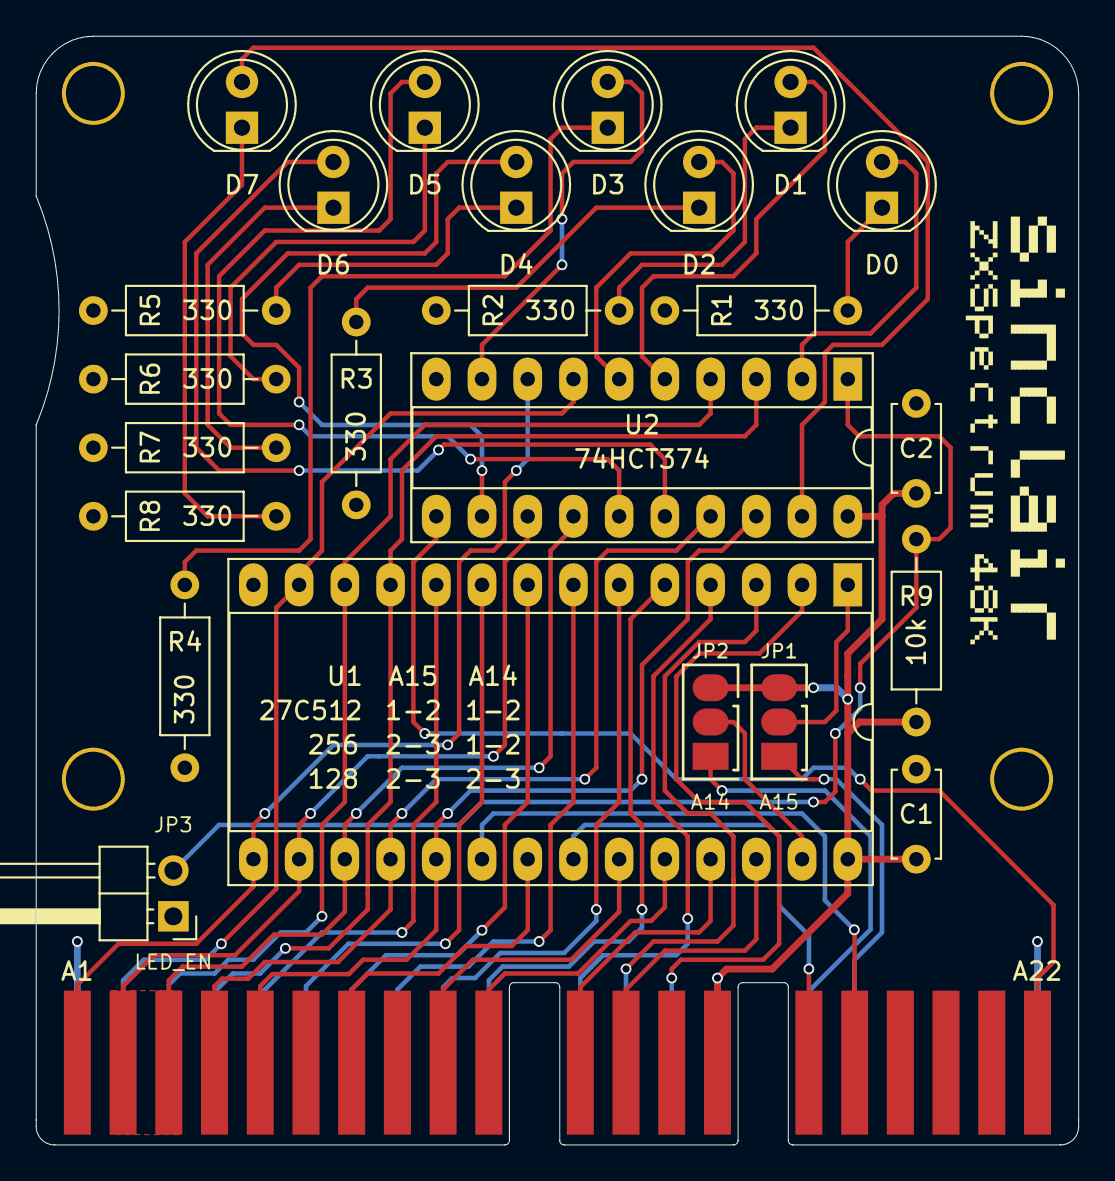
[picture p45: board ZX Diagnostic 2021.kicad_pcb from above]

Board: 2 copper layers, 57.9 x 61.6 mm, 30 parts (0 on the bottom side), 48 nets.

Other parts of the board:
sinclair_title: sinclair_title

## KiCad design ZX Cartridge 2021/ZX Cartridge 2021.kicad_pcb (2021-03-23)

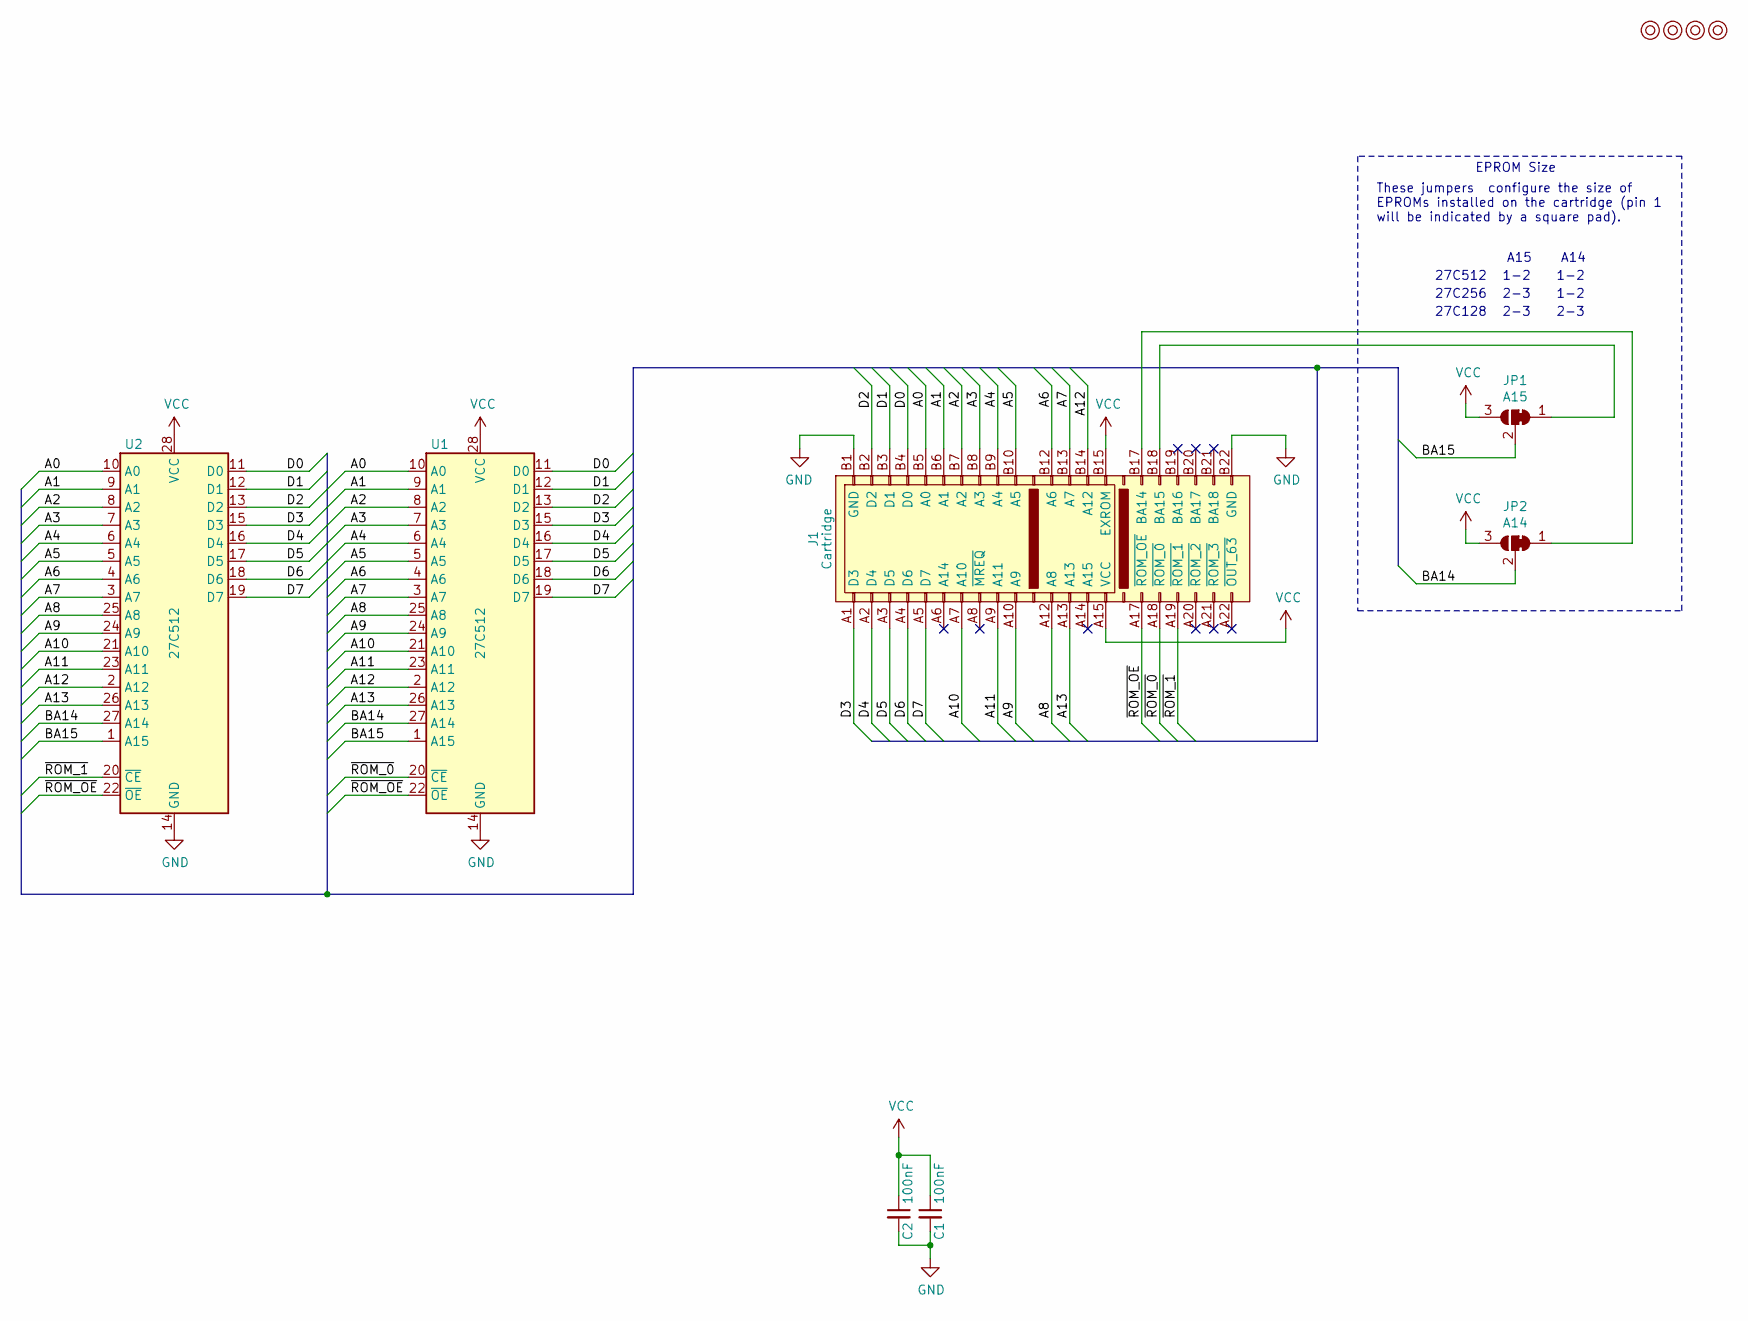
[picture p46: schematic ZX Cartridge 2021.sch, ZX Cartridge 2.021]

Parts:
C1, C2: 100nF; C_Disc_D4.7mm_W2.5mm_P5.00mm
J1: Cartridge; ZX_Spectrum_Cartridge
JP1: A15; select
JP2: A14; select
M1, M2, M3, M4: Mounting; M3_pin
U1, U2: 27C512; DIP-28_W15.24mm_Socket_LongPads

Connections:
/A0: J1.B5 (A0), U1.10 (A0), U2.10 (A0)
/A1: J1.B6 (A1), U1.9 (A1), U2.9 (A1)
/A2: J1.B7 (A2), U1.8 (A2), U2.8 (A2)
/A3: J1.B8 (A3), U1.7 (A3), U2.7 (A3)
/A4: J1.B9 (A4), U1.6 (A4), U2.6 (A4)
/A5: J1.B10 (A5), U1.5 (A5), U2.5 (A5)
/A6: J1.B12 (A6), U1.4 (A6), U2.4 (A6)
/A7: J1.B13 (A7), U1.3 (A7), U2.3 (A7)
/A8: J1.A12 (A8), U1.25 (A8), U2.25 (A8)
/A9: J1.A10 (A9), U1.24 (A9), U2.24 (A9)
/A10: J1.A7 (A10), U1.21 (A10), U2.21 (A10)
/A11: J1.A9 (A11), U1.23 (A11), U2.23 (A11)
/A12: J1.B14 (A12), U1.2 (A12), U2.2 (A12)
/A13: J1.A13, U1.26 (A13), U2.26 (A13)
/BA14: JP2.2 (C), U1.27 (A14), U2.27 (A14)
/BA15: JP1.2 (C), U1.1 (A15), U2.1 (A15)
/D0: J1.B4 (D0), U1.11 (D0), U2.11 (D0)
/D1: J1.B3 (D1), U1.12 (D1), U2.12 (D1)
/D2: J1.B2 (D2), U1.13 (D2), U2.13 (D2)
/D3: J1.A1 (D3), U1.15 (D3), U2.15 (D3)
/D4: J1.A2 (D4), U1.16 (D4), U2.16 (D4)
/D5: J1.A3 (D5), U1.17 (D5), U2.17 (D5)
/D6: J1.A4 (D6), U1.18 (D6), U2.18 (D6)
/D7: J1.A5 (D7), U1.19 (D7), U2.19 (D7)
/~ROM_0: J1.A18 (~ROM_0), U1.20 (~CE)
/~ROM_1: J1.A19 (~ROM_1), U2.20 (~CE)
/~ROM_OE: J1.A17 (~ROM_OE), U1.22 (~OE), U2.22 (~OE)
GND: C1.2, C2.2, J1.B1 (GND), J1.B22 (GND), U1.14 (GND), U2.14 (GND)
unnamed: J1.B17 (BA14), JP2.1 (A)
unnamed: J1.B18 (BA15), JP1.1 (A)
VCC: C1.1, C2.1, J1.A15 (VCC), J1.B15 (EXROM), JP1.3 (B), JP2.3 (B), U1.28 (VCC), U2.28 (VCC)

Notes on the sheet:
EPROM Size
These jumpers configure the size of EPROMs installed on the cartridge (pin 1 will be indicated by a square pad).
A15
A14
27C512
27C256
27C128
1-2
2-3

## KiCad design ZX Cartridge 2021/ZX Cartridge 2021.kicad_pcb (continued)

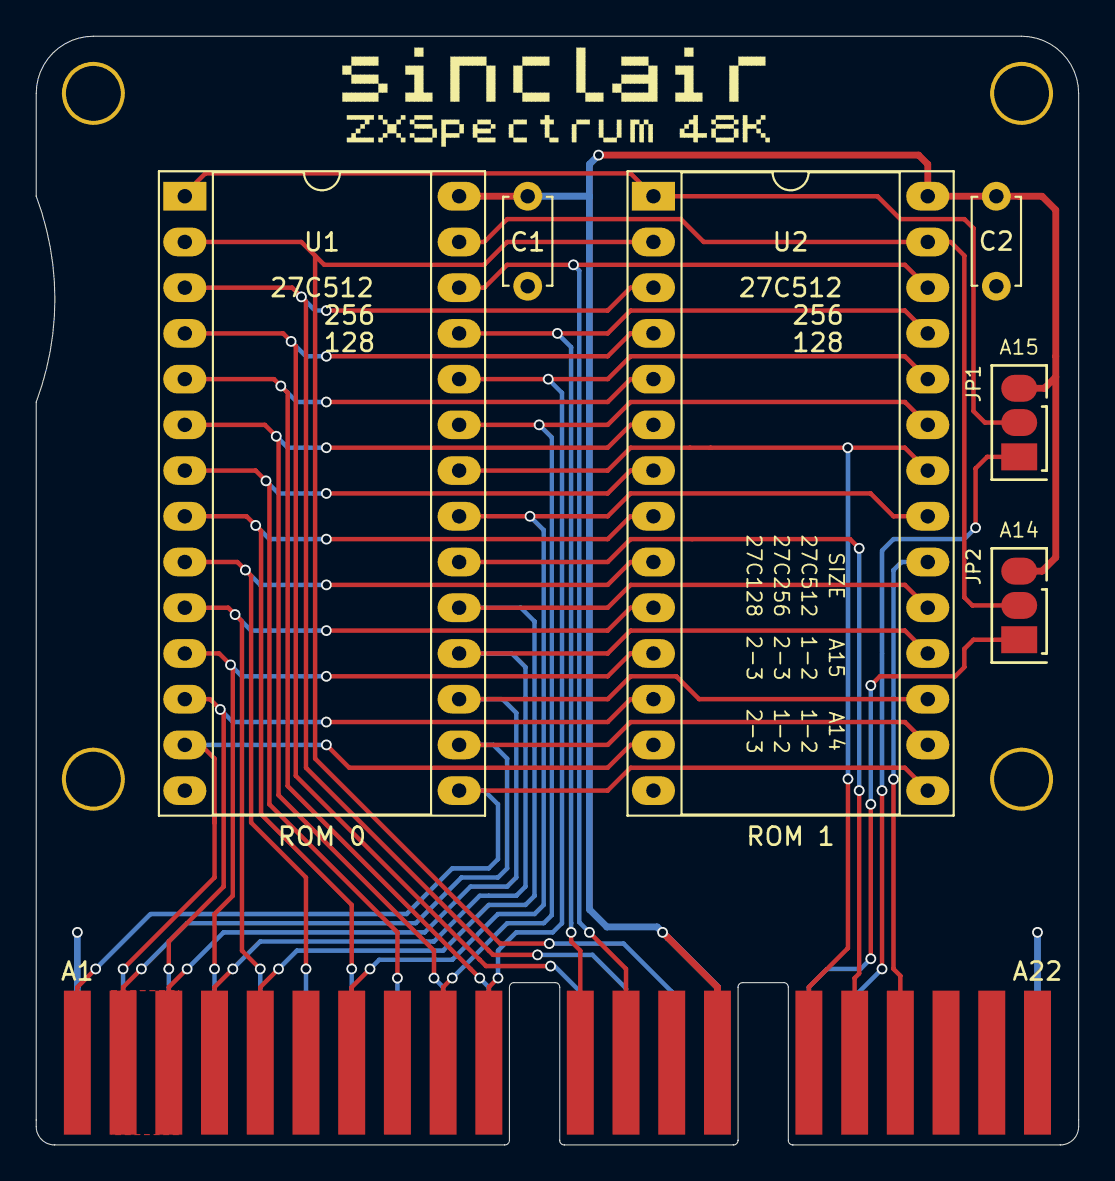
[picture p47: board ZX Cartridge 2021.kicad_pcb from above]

Board: 2 copper layers, 57.9 x 61.6 mm, 13 parts (1 on the bottom side), 31 nets.

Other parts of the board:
sinclair_title: sinclair_title
sinclair_title#2: sinclair_title

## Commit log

2021-02-28 Rough sketch
    [ZX Interface 2021.kicad_pcb, ZX Interface 2021.sch]
2021-03-03 Created proper extended cartridge symbols
    [ZX Cartridge 2021.kicad_pcb, ZX Cartridge 2021.sch, ZX Interface 2021.sch]
2021-03-03 Assigned footprints
    [ZX Interface 2021.sch]
2021-03-04 Laying some tracks...
    [ZX Interface 2021.kicad_pcb, ZX Interface 2021.sch]
2021-03-05 ... and the rest
    [ZX Cartridge 2021.sch, ZX Interface 2021.kicad_pcb, ZX Interface 2021.sch]
2021-03-05 Added some artwork
    [ZX Interface 2021.kicad_pcb, ZX Interface 2021.sch]
2021-03-05 Silkscreen tweaks
    [ZX Interface 2021.kicad_pcb]
2021-03-05 Cartridge components thrown in
    [ZX Cartridge 2021.kicad_pcb, ZX Cartridge 2021.sch]
2021-03-05 27c512 cartridge layout done
    [ZX Cartridge 2021.kicad_pcb, ZX Cartridge 2021.sch]
2021-03-06 Added 27C256 and 27C128 compatibility
    [ZX Cartridge 2021.kicad_pcb, ZX Cartridge 2021.sch]
2021-03-06 Added grip
    [ZX Cartridge 2021.kicad_pcb]
2021-03-06 Diagnostic riding the bus
    [ZX Diagnostic 2021.kicad_pcb, ZX Diagnostic 2021.sch]
2021-03-06 Diagnostic layout done
    [ZX Diagnostic 2021.kicad_pcb]
2021-03-07 Gerber export
    [ZX Cartridge 2021-B_Cu.gbl, ZX Cartridge 2021-B_Mask.gbs, ZX Cartridge 2021-B_Paste.gbp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]
2021-03-07 Unit Faceplate added
    [ZX Interface 2021 FA1-B_Cu.gbl, ZX Interface 2021 FA1-B_Mask.gbs, ZX Interface 2021 FA1-B_Paste.gbp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]
2021-03-08 Diagnostic faceplate
    [ZX Diagnostic 2021 FA1-B_Cu.gbl, ZX Diagnostic 2021 FA1-B_Mask.gbs, ZX Diagnostic 2021 FA1-B_Paste.gbp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]
2021-03-08 Added blank faceplate
    [ZX Cartridge 2021 FA1-B_Cu.gbl, ZX Cartridge 2021 FA1-B_Mask.gbs, ZX Cartridge 2021 FA1-B_Paste.gbp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]
2021-03-21 Cartridge pins were mirrored, still need to change cartridges
    [ZX Interface 2021.kicad_pcb, ZX Interface 2021.sch]
2021-03-23 Made 74ls245 open collector instead of using resistors
    [ZX Diagnostic 2021.sch, ZX Interface 2021 FA1.kicad_pcb, ZX Interface 2021.kicad_pcb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]
2021-03-23 unscrambled joystick pins
    [ZX Interface 2021.kicad_pcb]
2021-03-23 Tweaked interface title
    [ZX Interface 2021.kicad_pcb, ZX Interface 2021.sch]
2021-03-23 Add POWER LED cutout
    [ZX Interface 2021 FA1.kicad_pcb]
2021-03-23 Fixed cartridge pinout
    [ZX Cartridge 2021.kicad_pcb]
2021-03-23 Fixed diagnostic pinout
    [ZX Cartridge 2021.kicad_pcb, ZX Diagnostic 2021.kicad_pcb]
2021-03-23 Fixed a mounting pin bug
    [ZX Diagnostic 2021.kicad_pcb]
2021-04-02 Larger DB9 cutouts
    [ZX Interface 2021 FA1-B_Cu.gbl, ZX Interface 2021 FA1-B_Mask.gbs, ZX Interface 2021 FA1-B_Paste.gbp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]
2021-04-05 Untested 1983 cartridge (16k only)
    [ZX Cartridge 1983-B_Cu.gbl, ZX Cartridge 1983-B_Mask.gbs, ZX Cartridge 1983-B_Paste.gbp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]
2021-04-06 Changed 1983 to 1.983
    [ZX Cartridge 1983-B_Cu.gbl, ZX Cartridge 1983-B_Mask.gbs, ZX Cartridge 1983-B_Paste.gbp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]
2021-04-09 bank switching document
2021-04-09 LED out notice
2021-04-10 Marked positive C5 pin
    [ZX Interface 2021-B_Cu.gbl, ZX Interface 2021-B_Mask.gbs, ZX Interface 2021-B_Paste.gbp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]
2021-04-11 Updated order URLs
    [ZX Cartridge 2021-B_Cu.gbl, ZX Cartridge 2021-B_Mask.gbs, ZX Cartridge 2021-B_Paste.gbp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]
2021-04-16 Tweaked edge shape
    [ZX Cartridge 1983-B_Cu.gbl, ZX Cartridge 1983-B_Mask.gbs, ZX Cartridge 1983-B_Paste.gbp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]
2021-04-23 Added z80 loader for bank switching
2021-04-24 Added a blank slot placeholder
2021-04-25 Updated bank switching documentation
2021-04-27 Updated schematic
2021-04-27 Cassette themed faceplate
    [ZX Cartridge 2021 FA5 Cassette-B_Cu.gbl, ZX Cartridge 2021 FA5 Cassette-B_Mask.gbs, ZX Cartridge 2021 FA5 Cassette-B_Paste.gbp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]
2021-04-27 Larger writable area
    [ZX Cartridge 2021 FA1-B_Cu.gbl, ZX Cartridge 2021 FA1-B_Mask.gbs, ZX Cartridge 2021 FA1-B_Paste.gbp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]
2021-04-27 Moved pins to line up with original Kempson Pro Joystick interface
    [ZX Cartridge 1983-B_Cu.gbl, ZX Cartridge 1983-B_Mask.gbs, ZX Cartridge 1983-B_Paste.gbp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]
2021-04-28 Cartridge creator support blank slots
2021-04-29 Changed FA1 design
    [ZX Cartridge 2021 FA1-B_Cu.gbl, ZX Cartridge 2021 FA1-B_Mask.gbs, ZX Cartridge 2021 FA1-B_Paste.gbp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]
2021-05-09 Marked pinouts for smaller chips
    [ZX Cartridge 1983-B_Cu.gbl, ZX Cartridge 1983-B_Mask.gbs, ZX Cartridge 1983-B_Paste.gbp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]
2021-08-26 Cartridge 1.983 needed some more height to clear RAM turbo interface case
    [ZX Cartridge 1983-B_Cu.gbl, ZX Cartridge 1983-B_Mask.gbs, ZX Cartridge 1983-B_Paste.gbp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]
2024-11-21 Missing schematic

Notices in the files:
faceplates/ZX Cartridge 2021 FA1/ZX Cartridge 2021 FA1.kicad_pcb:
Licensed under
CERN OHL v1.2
